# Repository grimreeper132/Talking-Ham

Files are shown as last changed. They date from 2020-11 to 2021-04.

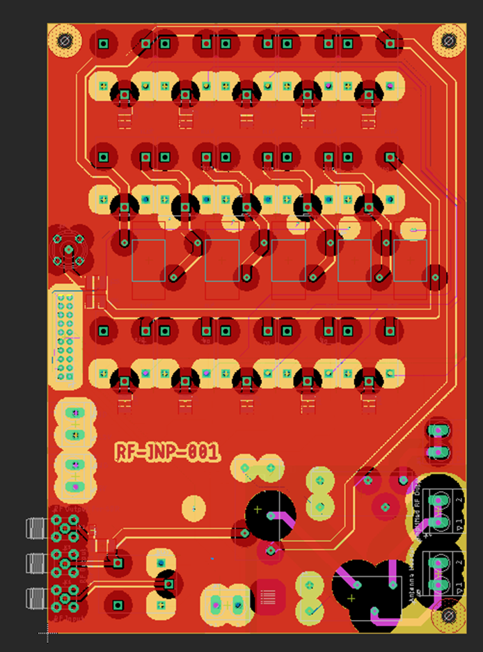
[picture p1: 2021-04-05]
Schematics/Layout Scheen shots/RF-INP-001 With Planes.png

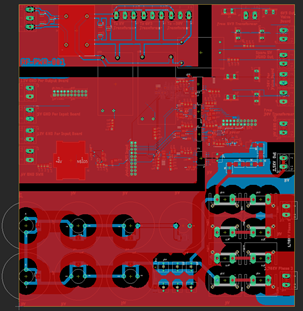
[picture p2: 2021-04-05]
Schematics/Layout Scheen shots/RF-PWR-001 With Planes.png

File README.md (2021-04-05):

# Talking-Ham
Open source HF, RF Valve Amplifier for HAM Radio. 

This has been started as a 4th year University Project in collaberation between Mage Control Systems and Strathclyde University

This project was taken up to the finalising the design but at time of writing (5/4/2021) it has not been written up

WARNING This device uses HV (2500 V) do not design it without prior knowledge and making a safety plan

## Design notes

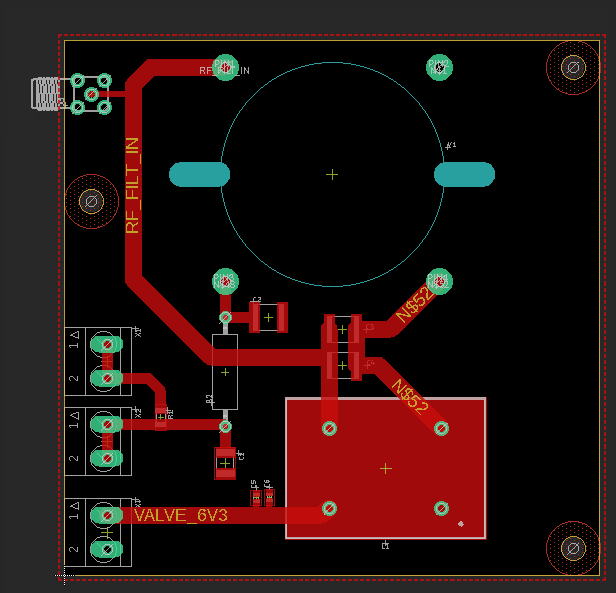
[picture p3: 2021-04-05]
Schematics/Layout Scheen shots/RF-VAL-001 W Hole.png

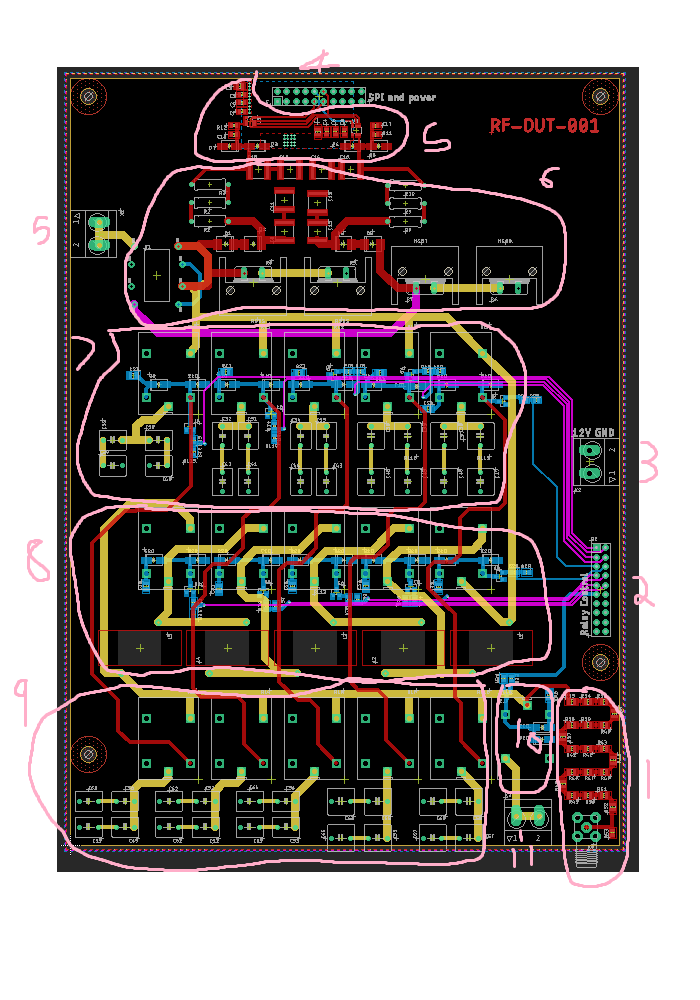
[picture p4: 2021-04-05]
Schematics/Layout Scheen shots/RF-OUT-001 Annotated.png

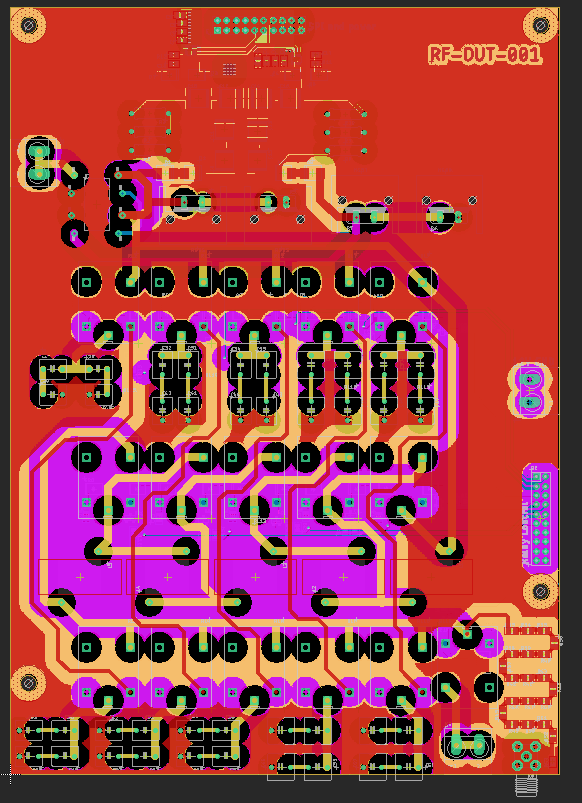
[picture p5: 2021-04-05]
Schematics/Layout Scheen shots/RF-OUT-001 With Planes.png

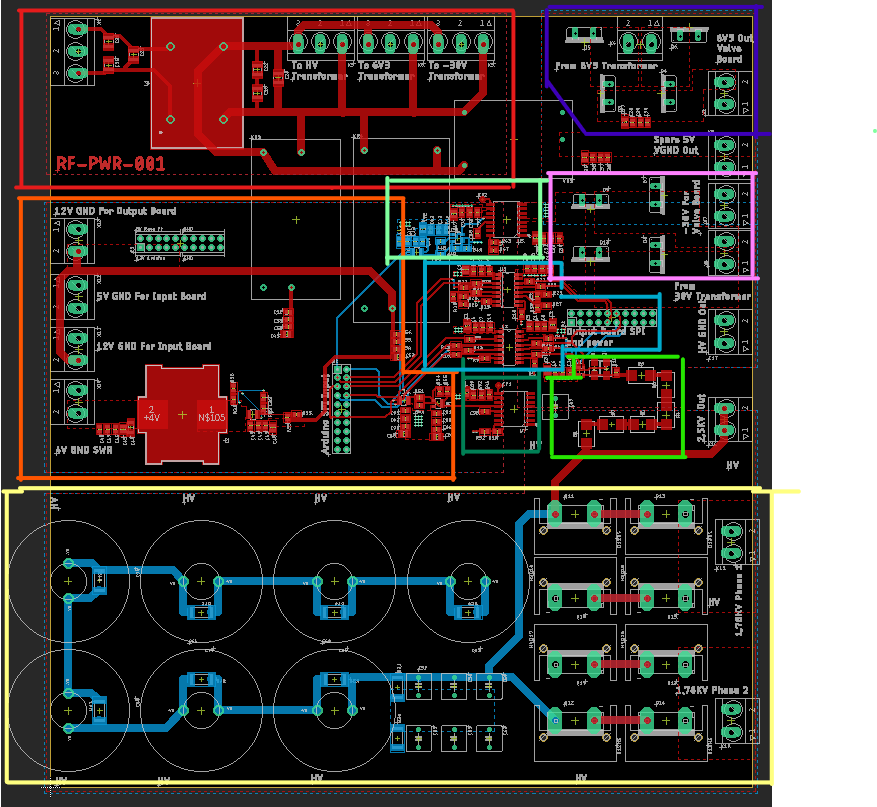
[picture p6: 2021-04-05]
Schematics/Layout Scheen shots/RF-PWR-001 Annotated.png

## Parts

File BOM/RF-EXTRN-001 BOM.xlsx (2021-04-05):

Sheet: Complete
 | Board ID |  |  | Engineer |  |  | Project |  |  | Job NO.
 | Revision | 1 |  | Approval |  |  | Customer |  |  | Boards Required | 1
Type Colour | Schematic Ref | Quantity | Spare Parts | Description | Footprint | Value | Tolerance | Manufacturer | Manufacturer Part Number | Preferred Supplier | Order-code | Alternate Supplier | Alt Order-Code | Unit/Reel Price | Packaging | Reel QTY | Stock | Price per board | Total Price (all boards) | Order Quantity | Order Price
7 | VNA1 | 1 |  | Nano VNA 4 | External | up to 1.5GHz |  | TANOU | NANO VNA 4 | Amazon | Link (https://www.amazon.co.uk/TANOU-NanoVNA-H4-Display-50KHz-1-5GHz-Analyzer/dp/B08BNC626K) |  |  | £49.61 | Cut Tape | 1000 |  | £49.61 | £49.61 | 1 | £49.61
7 | RSP1 | 1 |  | Raspberry Pi 3 | External |  |  | Raspberry Pi | RPI3-MODBP-BULK | Mouser | 358-RPI3-MODBP-BULK |  |  | £33.70 | Cut Tape | 1000 |  | £33.70 | £33.70 | 1 | £33.70
7 | DUE1 | 1 |  | Arduino Due | External |  |  | Arduino | Due | Mouser | 782-A000062 | Digi-Key | 1050-1049-ND | £28.51 | Cut Tape | 1000 |  | £28.51 | £28.51 | 1 | £28.51
7 | SDR1, SDR2 | 2 |  | Software Defined Radio | External |  |  | RTL-SDR | R820T2 RTL2832U | Amazon | Link (https://www.amazon.co.uk/RTL-SDR-Blog-RTL2832U-Software-Defined/dp/B0129EBDS2) |  |  | £49.99 | Cut Tape | 1000 |  | £99.98 | £99.98 | 2 | £99.98
10 | PCB1 | 1 |  | RF-PWR-001 PCB | RF-PWR-001 |  |  | JLC | RF-PWR-001 | JLC |  |  |  | £15.62 | Cut Tape | 1000 |  | £15.62 | £15.62 | 1 | £15.62
10 | PCB2 | 1 |  | RF-INP-001 PCB | RF-INP-001 |  |  | JLC | RF-INP-001 | JLC |  |  |  | £32.26 | Cut Tape | 1000 |  | £32.26 | £32.26 | 1 | £32.26
10 | PCB3 | 1 |  | RF-VAL-001 PCB | RF-VAL-001 |  |  | JLC | RF-VAL-001 | JLC |  |  |  | £1.45 | Cut Tape | 1000 |  | £1.45 | £1.45 | 1 | £1.45
10 | PCB4 | 1 |  | RF-OUT-001 PCB | RF-OUT-001 |  |  | JLC | RF-OUT-001 | JLC |  |  |  | £36.40 | Cut Tape | 1000 |  | £36.40 | £36.40 | 1 | £36.40
7 | USB1, USB2 | 2 |  | USB Isolator | External |  |  | Seeed Studio | 114991949 | Mouser | 713-114991949 |  |  | £14.47 | Cut Tape | 1000 |  | £28.94 | £28.94 | 2 | £28.94
 |  |  |  |  |  |  |  |  |  |  |  |  |  |  | Cut Tape | 1000 |  | £0.00 | £0.00 | 0 | £0.00
 |  |  |  |  |  |  |  |  |  |  |  |  |  |  | Cut Tape | 1000 |  | £0.00 | £0.00 | 0 | £0.00
 |  |  |  |  |  |  |  |  |  |  |  |  |  |  | Cut Tape | 1000 |  | £0.00 | £0.00 | 0 | £0.00
 |  |  |  |  |  |  |  |  |  |  |  |  |  |  | Cut Tape | 1000 |  | £0.00 | £0.00 | 0 | £0.00
 |  |  |  |  |  |  |  |  |  |  |  |  |  |  | Cut Tape | 1000 |  | £0.00 | £0.00 | 0 | £0.00
 |  |  |  |  |  |  |  |  |  |  |  |  |  |  | Cut Tape | 1000 |  | £0.00 | £0.00 | 0 | £0.00
 |  |  |  |  |  |  |  |  |  |  |  |  |  |  | Cut Tape | 1000 |  | £0.00 | £0.00 | 0 | £0.00
 |  |  |  |  |  |  |  |  |  |  |  |  |  |  | Cut Tape | 1000 |  | £0.00 | £0.00 | 0 | £0.00
 |  |  |  |  |  |  |  |  |  |  |  |  |  |  | Cut Tape | 1000 |  | £0.00 | £0.00 | 0 | £0.00
 |  |  |  |  |  |  |  |  |  |  |  |  |  |  | Cut Tape | 1000 |  | £0.00 | £0.00 | 0 | £0.00
 |  |  |  |  |  |  |  |  |  |  |  |  |  |  | Cut Tape | 1000 |  | £0.00 | £0.00 | 0 | £0.00
 |  |  |  |  |  |  |  |  |  |  |  |  |  |  | Cut Tape | 1000 |  | £0.00 | £0.00 | 0 | £0.00
 |  |  |  |  |  |  |  |  |  |  |  |  |  |  | Cut Tape | 1000 |  | £0.00 | £0.00 | 0 | £0.00
 |  |  |  |  |  |  |  |  |  |  |  |  |  |  | Cut Tape | 1000 |  | £0.00 | £0.00 | 0 | £0.00
 |  |  |  |  |  |  |  |  |  |  |  |  |  |  | Cut Tape | 1000 |  | £0.00 | £0.00 | 0 | £0.00
 |  |  |  |  |  |  |  |  |  |  |  |  |  |  | Cut Tape | 1000 |  | £0.00 | £0.00 | 0 | £0.00
 |  |  |  |  |  |  |  |  |  |  |  |  |  |  | Cut Tape | 1000 |  | £0.00 | £0.00 | 0 | £0.00
 |  |  |  |  |  |  |  |  |  |  |  |  |  |  | Cut Tape | 1000 |  | £0.00 | £0.00 | 0 | £0.00
 |  |  |  |  |  |  |  |  |  |  |  |  |  |  | Cut Tape | 1000 |  | £0.00 | £0.00 | 0 | £0.00
 |  |  |  |  |  |  |  |  |  |  |  |  |  |  | Cut Tape | 1000 |  | £0.00 | £0.00 | 0 | £0.00
 |  |  |  |  |  |  |  |  |  |  |  |  |  |  | Cut Tape | 1000 |  | £0.00 | £0.00 | 0 | £0.00
 |  |  |  |  |  |  |  |  |  |  |  |  |  |  | Cut Tape | 1000 |  | £0.00 | £0.00 | 0 | £0.00
 |  |  |  |  |  |  |  |  |  |  |  |  |  |  | Cut Tape | 1000 |  | £0.00 | £0.00 | 0 | £0.00
 |  |  |  |  |  |  |  |  |  |  |  |  |  |  | Cut Tape | 1000 |  | £0.00 | £0.00 | 0 | £0.00
 |  |  |  |  |  |  |  |  |  |  |  |  |  |  | Cut Tape | 1000 |  | £0.00 | £0.00 | 0 | £0.00
 |  |  |  |  |  |  |  |  |  |  |  |  |  |  | Cut Tape | 1000 |  | £0.00 | £0.00 | 0 | £0.00
 |  |  |  |  |  |  |  |  |  |  |  |  |  |  | Cut Tape | 1000 |  | £0.00 | £0.00 | 0 | £0.00
 |  |  |  |  |  |  |  |  |  |  |  |  |  |  | Cut Tape | 1000 |  | £0.00 | £0.00 | 0 | £0.00
 |  |  |  |  |  |  |  |  |  |  |  |  |  |  | Cut Tape | 1000 |  | £0.00 | £0.00 | 0 | £0.00
 |  |  |  |  |  |  |  |  |  |  |  |  |  |  | Cut Tape | 1000 |  | £0.00 | £0.00 | 0 | £0.00
 |  |  |  |  |  |  |  |  |  |  |  |  |  |  | Cut Tape | 1000 |  | £0.00 | £0.00 | 0 | £0.00
 |  |  |  |  |  |  |  |  |  |  |  |  |  |  | Cut Tape | 1000 |  | £0.00 | £0.00 | 0 | £0.00
 |  |  |  |  |  |  |  |  |  |  |  |  |  |  | Cut Tape | 1000 |  | £0.00 | £0.00 | 0 | £0.00
 |  |  |  |  |  |  |  |  |  |  |  |  |  |  | Cut Tape | 1000 |  | £0.00 | £0.00 | 0 | £0.00
 |  |  |  |  |  |  |  |  |  |  |  |  |  |  | Cut Tape | 1000 |  | £0.00 | £0.00 | 0 | £0.00
 |  |  |  |  |  |  |  |  |  |  |  |  |  |  | Cut Tape | 1000 |  | £0.00 | £0.00 | 0 | £0.00
 |  |  |  |  |  |  |  |  |  |  |  |  |  |  | Cut Tape | 1000 |  | £0.00 | £0.00 | 0 | £0.00
 |  |  |  |  |  |  |  |  |  |  |  |  |  |  | Cut Tape | 1000 |  | £0.00 | £0.00 | 0 | £0.00
 |  |  |  |  |  |  |  |  |  |  |  |  |  |  | Cut Tape | 1000 |  | £0.00 | £0.00 | 0 | £0.00
 |  |  |  |  |  |  |  |  |  |  |  |  |  |  | Cut Tape | 1000 |  | £0.00 | £0.00 | 0 | £0.00
 |  |  |  |  |  |  |  |  |  |  |  |  |  |  | Cut Tape | 1000 |  | £0.00 | £0.00 | 0 | £0.00
 |  |  |  |  |  |  |  |  |  |  |  |  |  |  | Cut Tape | 1000 |  | £0.00 | £0.00 | 0 | £0.00
 |  |  |  |  |  |  |  |  |  |  |  |  |  |  | Cut Tape | 1000 |  | £0.00 | £0.00 | 0 | £0.00
 |  |  |  |  |  |  |  |  |  |  |  |  |  |  | Cut Tape | 1000 |  | £0.00 | £0.00 | 0 | £0.00
 |  |  |  |  |  |  |  |  |  |  |  |  |  |  | Cut Tape | 1000 |  | £0.00 | £0.00 | 0 | £0.00
 |  |  |  |  |  |  |  |  |  |  |  |  |  |  | Cut Tape | 1000 |  | £0.00 | £0.00 | 0 | £0.00
 |  |  |  |  |  |  |  |  |  |  |  |  |  |  | Cut Tape | 1000 |  | £0.00 | £0.00 | 0 | £0.00
 |  |  |  |  |  |  |  |  |  |  |  |  |  |  | Cut Tape | 1000 |  | £0.00 | £0.00 | 0 | £0.00
 |  |  |  |  |  |  |  |  |  |  |  |  |  |  | Cut Tape | 1000 |  | £0.00 | £0.00 | 0 | £0.00
 |  |  |  |  |  |  |  |  |  |  |  |  |  |  | Cut Tape | 1000 |  | £0.00 | £0.00 | 0 | £0.00
 |  |  |  |  |  |  |  |  |  |  |  |  |  |  | Cut Tape | 1000 |  | £0.00 | £0.00 | 0 | £0.00
 |  |  |  |  |  |  |  |  |  |  |  |  |  |  | Cut Tape | 1000 |  | £0.00 | £0.00 | 0 | £0.00
 |  |  |  |  |  |  |  |  |  |  |  |  |  |  | Cut Tape | 1000 |  | £0.00 | £0.00 | 0 | £0.00
 |  |  |  |  |  |  |  |  |  |  |  |  |  |  | Cut Tape | 1000 |  | £0.00 | £0.00 | 0 | £0.00
 |  |  |  |  |  |  |  |  |  |  |  |  |  |  | Cut Tape | 1000 |  | £0.00 | £0.00 | 0 | £0.00
 |  |  |  |  |  |  |  |  |  |  |  |  |  |  | Cut Tape | 1000 |  | £0.00 | £0.00 | 0 | £0.00
 |  |  |  |  |  |  |  |  |  |  |  |  |  |  | Cut Tape | 1000 |  | £0.00 | £0.00 | 0 | £0.00
 |  |  |  |  |  |  |  |  |  |  |  |  |  |  | Cut Tape | 1000 |  | £0.00 | £0.00 | 0 | £0.00
 |  |  |  |  |  |  |  |  |  |  |  |  |  |  | Cut Tape | 1000 |  | £0.00 | £0.00 | 0 | £0.00
 |  |  |  |  |  |  |  |  |  |  |  |  |  |  | Cut Tape | 1000 |  | £0.00 | £0.00 | 0 | £0.00
 |  |  |  |  |  |  |  |  |  |  |  |  |  |  | Cut Tape | 1000 |  | £0.00 | £0.00 | 0 | £0.00
 |  |  |  |  |  |  |  |  |  |  |  |  |  |  | Cut Tape | 1000 |  | £0.00 | £0.00 | 0 | £0.00
 |  |  |  |  |  |  |  |  |  |  |  |  |  |  | Cut Tape | 1000 |  | £0.00 | £0.00 | 0 | £0.00
 |  |  |  |  |  |  |  |  |  |  |  |  |  |  | Cut Tape | 1000 |  | £0.00 | £0.00 | 0 | £0.00
 |  |  |  |  |  |  |  |  |  |  |  |  |  |  | Cut Tape | 1000 |  | £0.00 | £0.00 | 0 | £0.00
 |  |  |  |  |  |  |  |  |  |  |  |  |  |  | Cut Tape | 1000 |  | £0.00 | £0.00 | 0 | £0.00
 |  |  |  |  |  |  |  |  |  |  |  |  |  |  | Cut Tape | 1000 |  | £0.00 | £0.00 | 0 | £0.00
 |  |  |  |  |  |  |  |  |  |  |  |  |  |  | Cut Tape | 1000 |  | £0.00 | £0.00 | 0 | £0.00
 |  |  |  |  |  |  |  |  |  |  |  |  |  |  | Cut Tape | 1000 |  | £0.00 | £0.00 | 0 | £0.00
 |  |  |  |  |  |  |  |  |  |  |  |  |  |  | Cut Tape | 1000 |  | £0.00 | £0.00 | 0 | £0.00
 |  |  |  |  |  |  |  |  |  |  |  |  |  |  | Cut Tape | 1000 |  | £0.00 | £0.00 | 0 | £0.00
 |  |  |  |  |  |  |  |  |  |  |  |  |  |  | Cut Tape | 1000 |  | £0.00 | £0.00 | 0 | £0.00
 |  |  |  |  |  |  |  |  |  |  |  |  |  |  | Cut Tape | 1000 |  | £0.00 | £0.00 | 0 | £0.00
 |  |  |  |  |  |  |  |  |  |  |  |  |  |  | Cut Tape | 1000 |  | £0.00 | £0.00 | 0 | £0.00
 |  |  |  |  |  |  |  |  |  |  |  |  |  |  | Cut Tape | 1000 |  | £0.00 | £0.00 | 0 | £0.00
 |  |  |  |  |  |  |  |  |  |  |  |  |  |  | Cut Tape | 1000 |  | £0.00 | £0.00 | 0 | £0.00
 |  |  |  |  |  |  |  |  |  |  |  |  |  |  | Cut Tape | 1000 |  | £0.00 | £0.00 | 0 | £0.00
 |  |  |  |  |  |  |  |  |  |  |  |  |  |  | Cut Tape | 1000 |  | £0.00 | £0.00 | 0 | £0.00
 |  |  |  |  |  |  |  |  |  |  |  |  |  |  | Cut Tape | 1000 |  | £0.00 | £0.00 | 0 | £0.00
 |  |  |  |  |  |  |  |  |  |  |  |  |  |  | Cut Tape | 1000 |  | £0.00 | £0.00 | 0 | £0.00
 |  |  |  |  |  |  |  |  |  |  |  |  |  |  | Cut Tape | 1000 |  | £0.00 | £0.00 | 0 | £0.00
 |  |  |  |  |  |  |  |  |  |  |  |  |  |  | Cut Tape | 1000 |  | £0.00 | £0.00 | 0 | £0.00
 |  |  |  |  |  |  |  |  |  |  |  |  |  |  | Cut Tape | 1000 |  | £0.00 | £0.00 | 0 | £0.00
 |  |  |  |  |  |  |  |  |  |  |  |  |  |  | Cut Tape | 1000 |  | £0.00 | £0.00 | 0 | £0.00
 |  |  |  |  |  |  |  |  |  |  |  |  |  |  | Cut Tape | 1000 |  | £0.00 | £0.00 | 0 | £0.00
 |  |  |  |  |  |  |  |  |  |  |  |  |  |  | Cut Tape | 1000 |  | £0.00 | £0.00 | 0 | £0.00
 |  |  |  |  |  |  |  |  |  |  |  |  |  |  | Cut Tape | 1000 |  | £0.00 | £0.00 | 0 | £0.00
 |  |  |  |  |  |  |  |  |  |  |  |  |  |  | Cut Tape | 1000 |  | £0.00 | £0.00 | 0 | £0.00
 |  |  |  |  |  |  |  |  |  |  |  |  |  |  | Cut Tape | 1000 |  | £0.00 | £0.00 | 0 | £0.00
 |  |  |  |  |  |  |  |  |  |  |  |  |  |  | Cut Tape | 1000 |  | £0.00 | £0.00 | 0 | £0.00
 |  |  |  |  |  |  |  |  |  |  |  |  |  |  | Cut Tape | 1000 |  | £0.00 | £0.00 | 0 | £0.00
 |  |  |  |  |  |  |  |  |  |  |  |  |  |  | Cut Tape | 1000 |  | £0.00 | £0.00 | 0 | £0.00
 |  |  |  |  |  |  |  |  |  |  |  |  |  |  | Cut Tape | 1000 |  | £0.00 | £0.00 | 0 | £0.00
 |  |  |  |  |  |  |  |  |  |  |  |  |  |  | Cut Tape | 1000 |  | £0.00 | £0.00 | 0 | £0.00
 |  |  |  |  |  |  |  |  |  |  |  |  |  |  | Cut Tape | 1000 |  | £0.00 | £0.00 | 0 | £0.00
 |  |  |  |  |  |  |  |  |  |  |  |  |  |  | Cut Tape | 1000 |  | £0.00 | £0.00 | 0 | £0.00
 |  |  |  |  |  |  |  |  |  |  |  |  |  |  | Cut Tape | 1000 |  | £0.00 | £0.00 | 0 | £0.00
 |  |  |  |  |  |  |  |  |  |  |  |  |  |  | Cut Tape | 1000 |  | £0.00 | £0.00 | 0 | £0.00
 |  |  |  |  |  |  |  |  |  |  |  |  |  |  | Cut Tape | 1000 |  | £0.00 | £0.00 | 0 | £0.00
 |  |  |  |  |  |  |  |  |  |  |  |  |  |  | Cut Tape | 1000 |  | £0.00 | £0.00 | 0 | £0.00
 |  |  |  |  |  |  |  |  |  |  |  |  |  |  | Cut Tape | 1000 |  | £0.00 | £0.00 | 0 | £0.00
 |  |  |  |  |  |  |  |  |  |  |  |  |  |  | Cut Tape | 1000 |  | £0.00 | £0.00 | 0 | £0.00
 |  |  |  |  |  |  |  |  |  |  |  |  |  |  | Cut Tape | 1000 |  | £0.00 | £0.00 | 0 | £0.00
 |  |  |  |  |  |  |  |  |  |  |  |  |  |  | Cut Tape | 1000 |  | £0.00 | £0.00 | 0 | £0.00
 |  |  |  |  |  |  |  |  |  |  |  |  |  |  | Cut Tape | 1000 |  | £0.00 | £0.00 | 0 | £0.00
 |  |  |  |  |  |  |  |  |  |  |  |  |  |  | Cut Tape | 1000 |  | £0.00 | £0.00 | 0 | £0.00
 |  |  |  |  |  |  |  |  |  |  |  |  |  |  | Cut Tape | 1000 |  | £0.00 | £0.00 | 0 | £0.00
 |  |  |  |  |  |  |  |  |  |  |  |  |  |  | Cut Tape | 1000 |  | £0.00 | £0.00 | 0 | £0.00
 |  |  |  |  |  |  |  |  |  |  |  |  |  |  | Cut Tape | 1000 |  | £0.00 | £0.00 | 0 | £0.00
 |  |  |  |  |  |  |  |  |  |  |  |  |  |  | Cut Tape | 1000 |  | £0.00 | £0.00 | 0 | £0.00
 |  |  |  |  |  |  |  |  |  |  |  |  |  |  | Cut Tape | 1000 |  | £0.00 | £0.00 | 0 | £0.00
 |  |  |  |  |  |  |  |  |  |  |  |  |  |  | Cut Tape | 1000 |  | £0.00 | £0.00 | 0 | £0.00
 |  |  |  |  |  |  |  |  |  |  |  |  |  |  | Cut Tape | 1000 |  | £0.00 | £0.00 | 0 | £0.00
 |  |  |  |  |  |  |  |  |  |  |  |  |  |  | Cut Tape | 1000 |  | £0.00 | £0.00 | 0 | £0.00
 |  |  |  |  |  |  |  |  |  |  |  |  |  |  | Cut Tape | 1000 |  | £0.00 | £0.00 | 0 | £0.00
 |  |  |  |  |  |  |  |  |  |  |  |  |  |  | Cut Tape | 1000 |  | £0.00 | £0.00 | 0 | £0.00
 |  |  |  |  |  |  |  |  |  |  |  |  |  |  | Cut Tape | 1000 |  | £0.00 | £0.00 | 0 | £0.00
 |  |  |  |  |  |  |  |  |  |  |  |  |  |  | Cut Tape | 1000 |  | £0.00 | £0.00 | 0 | £0.00
 |  |  |  |  |  |  |  |  |  |  |  |  |  |  | Cut Tape | 1000 |  | £0.00 | £0.00 | 0 | £0.00
 |  |  |  |  |  |  |  |  |  |  |  |  |  |  | Cut Tape | 1000 |  | £0.00 | £0.00 | 0 | £0.00
 |  |  |  |  |  |  |  |  |  |  |  |  |  |  | Cut Tape | 1000 |  | £0.00 | £0.00 | 0 | £0.00
 |  |  |  |  |  |  |  |  |  |  |  |  |  |  | Cut Tape | 1000 |  | £0.00 | £0.00 | 0 | £0.00
 |  |  |  |  |  |  |  |  |  |  |  |  |  |  | Cut Tape | 1000 |  | £0.00 | £0.00 | 0 | £0.00
 |  |  |  |  |  |  |  |  |  |  |  |  |  |  | Cut Tape | 1000 |  | £0.00 | £0.00 | 0 | £0.00
 |  |  |  |  |  |  |  |  |  |  |  |  |  |  | Cut Tape | 1000 |  | £0.00 | £0.00 | 0 | £0.00
 |  |  |  |  |  |  |  |  |  |  |  |  |  |  | Cut Tape | 1000 |  | £0.00 | £0.00 | 0 | £0.00
 |  |  |  |  |  |  |  |  |  |  |  |  |  |  | Cut Tape | 1000 |  | £0.00 | £0.00 | 0 | £0.00
 |  |  |  |  |  |  |  |  |  |  |  |  |  |  | Cut Tape | 1000 |  | £0.00 | £0.00 | 0 | £0.00
 |  |  |  |  |  |  |  |  |  |  |  |  |  |  | Cut Tape | 1000 |  | £0.00 | £0.00 | 0 | £0.00
 |  |  |  |  |  |  |  |  |  |  |  |  |  |  | Cut Tape | 1000 |  | £0.00 | £0.00 | 0 | £0.00
 |  |  |  |  |  |  |  |  |  |  |  |  |  |  | Cut Tape | 1000 |  | £0.00 | £0.00 | 0 | £0.00
 |  |  |  |  |  |  |  |  |  |  |  |  |  |  | Cut Tape | 1000 |  | £0.00 | £0.00 | 0 | £0.00
 |  |  |  |  |  |  |  |  |  |  |  |  |  |  | Cut Tape | 1000 |  | £0.00 | £0.00 | 0 | £0.00
 |  |  |  |  |  |  |  |  |  |  |  |  |  |  | Cut Tape | 1000 |  | £0.00 | £0.00 | 0 | £0.00
 |  |  |  |  |  |  |  |  |  |  |  |  |  |  | Cut Tape | 1000 |  | £0.00 | £0.00 | 0 | £0.00
 |  |  |  |  |  |  |  |  |  |  |  |  |  |  | Cut Tape | 1000 |  | £0.00 | £0.00 | 0 | £0.00
 |  |  |  |  |  |  |  |  |  |  |  |  |  |  | Cut Tape | 1000 |  | £0.00 | £0.00 | 0 | £0.00
 |  |  |  |  |  |  |  |  |  |  |  |  |  |  | Cut Tape | 1000 |  | £0.00 | £0.00 | 0 | £0.00
 |  |  |  |  |  |  |  |  |  |  |  |  |  |  | Cut Tape | 1000 |  | £0.00 | £0.00 | 0 | £0.00
 |  |  |  |  |  |  |  |  |  |  |  |  |  |  | Cut Tape | 1000 |  | £0.00 | £0.00 | 0 | £0.00
 |  |  |  |  |  |  |  |  |  |  |  |  |  |  | Cut Tape | 1000 |  | £0.00 | £0.00 | 0 | £0.00
 |  |  |  |  |  |  |  |  |  |  |  |  |  |  | Cut Tape | 1000 |  | £0.00 | £0.00 | 0 | £0.00
 |  |  |  |  |  |  |  |  |  |  |  |  |  |  | Cut Tape | 1000 |  | £0.00 | £0.00 | 0 | £0.00
 |  |  |  |  |  |  |  |  |  |  |  |  |  |  | Cut Tape | 1000 |  | £0.00 | £0.00 | 0 | £0.00
 |  |  |  |  |  |  |  |  |  |  |  |  |  |  | Cut Tape | 1000 |  | £0.00 | £0.00 | 0 | £0.00
 |  |  |  |  |  |  |  |  |  |  |  |  |  |  | Cut Tape | 1000 |  | £0.00 | £0.00 | 0 | £0.00
 |  |  |  |  |  |  |  |  |  |  |  |  |  |  | Cut Tape | 1000 |  | £0.00 | £0.00 | 0 | £0.00
 |  |  |  |  |  |  |  |  |  |  |  |  |  |  | Cut Tape | 1000 |  | £0.00 | £0.00 | 0 | £0.00
 |  |  |  |  |  |  |  |  |  |  |  |  |  |  | Cut Tape | 1000 |  | £0.00 | £0.00 | 0 | £0.00
 |  |  |  |  |  |  |  |  |  |  |  |  |  |  | Cut Tape | 1000 |  | £0.00 | £0.00 | 0 | £0.00
 |  |  |  |  |  |  |  |  |  |  |  |  |  |  | Cut Tape | 1001 |  | £0.00 | £0.00 | 0 | £0.00
 |  |  |  |  |  |  |  |  |  |  |  |  |  |  | Cut Tape | 1002 |  | £0.00 | £0.00 | 0 | £0.00
 |  |  |  |  |  |  |  |  |  |  |  |  |  |  | Cut Tape | 1003 |  | £0.00 | £0.00 | 0 | £0.00
 |  |  |  |  |  |  |  |  |  |  |  |  |  |  | Cut Tape | 1004 |  | £0.00 | £0.00 | 0 | £0.00
 |  |  |  |  |  |  |  |  |  |  |  |  |  |  | Cut Tape | 1005 |  | £0.00 | £0.00 | 0 | £0.00
 |  |  |  |  |  |  |  |  |  |  |  |  |  |  | Cut Tape | 1006 |  | £0.00 | £0.00 | 0 | £0.00
 |  |  |  |  |  |  |  |  |  |  |  |  |  |  | Cut Tape | 1007 |  | £0.00 | £0.00 | 0 | £0.00
 |  |  |  |  |  |  |  |  |  |  |  |  |  |  | Cut Tape | 1008 |  | £0.00 | £0.00 | 0 | £0.00
 |  |  |  |  |  |  |  |  |  |  |  |  |  |  | Cut Tape | 1009 |  | £0.00 | £0.00 | 0 | £0.00
 |  |  |  |  |  |  |  |  |  |  |  |  |  |  | Cut Tape | 1010 |  | £0.00 | £0.00 | 0 | £0.00
 |  |  |  |  |  |  |  |  |  |  |  |  |  |  | Cut Tape | 1011 |  | £0.00 | £0.00 | 0 | £0.00
 |  |  |  |  |  |  |  |  |  |  |  |  |  |  | Cut Tape | 1012 |  | £0.00 | £0.00 | 0 | £0.00
 |  |  |  |  |  |  |  |  |  |  |  |  |  |  | Cut Tape | 1013 |  | £0.00 | £0.00 | 0 | £0.00
 |  |  |  |  |  |  |  |  |  |  |  |  |  |  | Cut Tape | 1014 |  | £0.00 | £0.00 | 0 | £0.00
 |  |  |  |  |  |  |  |  |  |  |  |  |  |  | Cut Tape | 1015 |  | £0.00 | £0.00 | 0 | £0.00
 |  |  |  |  |  |  |  |  |  |  |  |  |  |  | Cut Tape | 1016 |  | £0.00 | £0.00 | 0 | £0.00
 |  |  |  |  |  |  |  |  |  |  |  |  |  |  | Cut Tape | 1017 |  | £0.00 | £0.00 | 0 | £0.00
 |  |  |  |  |  |  |  |  |  |  |  |  |  |  | Cut Tape | 1018 |  | £0.00 | £0.00 | 0 | £0.00
 |  |  |  |  |  |  |  |  |  |  |  |  |  |  | Cut Tape | 1019 |  | £0.00 | £0.00 | 0 | £0.00
 |  |  |  |  |  |  |  |  |  |  |  |  |  |  | Cut Tape | 1020 |  | £0.00 | £0.00 | 0 | £0.00
 |  |  |  |  |  |  |  |  |  |  |  |  |  |  | Cut Tape | 1021 |  | £0.00 | £0.00 | 0 | £0.00
 |  |  |  |  |  |  |  |  |  |  |  |  |  |  | Cut Tape | 1022 |  | £0.00 | £0.00 | 0 | £0.00
 |  |  |  |  |  |  |  |  |  |  |  |  |  |  | Cut Tape | 1023 |  | £0.00 | £0.00 | 0 | £0.00
 |  |  |  |  |  |  |  |  |  |  |  |  |  |  | Cut Tape | 1024 |  | £0.00 | £0.00 | 0 | £0.00
 |  |  |  |  |  |  |  |  |  |  |  |  |  |  | Cut Tape | 1025 |  | £0.00 | £0.00 | 0 | £0.00
 |  |  |  |  |  |  |  |  |  |  |  |  |  |  | Cut Tape | 1026 |  | £0.00 | £0.00 | 0 | £0.00
 |  |  |  |  |  |  |  |  |  |  |  |  |  |  | Cut Tape | 1027 |  | £0.00 | £0.00 | 0 | £0.00
 |  |  |  |  |  |  |  |  |  |  |  |  |  |  | Cut Tape | 1028 |  | £0.00 | £0.00 | 0 | £0.00
 |  |  |  |  |  |  |  |  |  |  |  |  |  |  | Cut Tape | 1029 |  | £0.00 | £0.00 | 0 | £0.00
 |  |  |  |  |  |  |  |  |  |  |  |  |  |  | Cut Tape | 1030 |  | £0.00 | £0.00 | 0 | £0.00
 |  |  |  |  |  |  |  |  |  |  |  |  |  |  | Cut Tape | 1031 |  | £0.00 | £0.00 | 0 | £0.00
 |  |  |  |  |  |  |  |  |  |  |  |  |  |  | Cut Tape | 1032 |  | £0.00 | £0.00 | 0 | £0.00
 |  |  |  |  |  |  |  |  |  |  |  |  |  |  | Cut Tape | 1033 |  | £0.00 | £0.00 | 0 | £0.00
 |  |  |  |  |  |  |  |  |  |  |  |  |  |  | Cut Tape | 1034 |  | £0.00 | £0.00 | 0 | £0.00
 |  |  |  |  |  |  |  |  |  |  |  |  |  |  | Cut Tape | 1035 |  | £0.00 | £0.00 | 0 | £0.00
 |  |  |  |  |  |  |  |  |  |  |  |  |  |  | Cut Tape | 1036 |  | £0.00 | £0.00 | 0 | £0.00
 |  |  |  |  |  |  |  |  |  |  |  |  |  |  | Cut Tape | 1037 |  | £0.00 | £0.00 | 0 | £0.00
 |  |  |  |  |  |  |  |  |  |  |  |  |  |  | Cut Tape | 1038 |  | £0.00 | £0.00 | 0 | £0.00
 |  |  |  |  |  |  |  |  |  |  |  |  |  |  | Cut Tape | 1039 |  | £0.00 | £0.00 | 0 | £0.00
 |  |  |  |  |  |  |  |  |  |  |  |  |  |  | Cut Tape | 1040 |  | £0.00 | £0.00 | 0 | £0.00
 |  |  |  |  |  |  |  |  |  |  |  |  |  |  | Cut Tape | 1041 |  | £0.00 | £0.00 | 0 | £0.00
 |  |  |  |  |  |  |  |  |  |  |  |  |  |  | Cut Tape | 1042 |  | £0.00 | £0.00 | 0 | £0.00
 |  |  |  |  |  |  |  |  |  |  |  |  |  |  | Cut Tape | 1043 |  | £0.00 | £0.00 | 0 | £0.00
 |  |  |  |  |  |  |  |  |  |  |  |  |  |  | Cut Tape | 1044 |  | £0.00 | £0.00 | 0 | £0.00
 |  |  |  |  |  |  |  |  |  |  |  |  |  |  | Cut Tape | 1045 |  | £0.00 | £0.00 | 0 | £0.00
 |  |  |  |  |  |  |  |  |  |  |  |  |  |  | Cut Tape | 1046 |  | £0.00 | £0.00 | 0 | £0.00
 |  |  |  |  |  |  |  |  |  |  |  |  |  |  | Cut Tape | 1047 |  | £0.00 | £0.00 | 0 | £0.00
 |  |  |  |  |  |  |  |  |  |  |  |  |  |  | Cut Tape | 1048 |  | £0.00 | £0.00 | 0 | £0.00
 |  |  |  |  |  |  |  |  |  |  |  |  |  |  | Cut Tape | 1049 |  | £0.00 | £0.00 | 0 | £0.00
 |  |  |  |  |  |  |  |  |  |  |  |  |  |  | Cut Tape | 1050 |  | £0.00 | £0.00 | 0 | £0.00
 |  |  |  |  |  |  |  |  |  |  |  |  |  |  | Cut Tape | 1051 |  | £0.00 | £0.00 | 0 | £0.00
 |  |  |  |  |  |  |  |  |  |  |  |  |  |  | Cut Tape | 1052 |  | £0.00 | £0.00 | 0 | £0.00
 |  |  |  |  |  |  |  |  |  |  |  |  |  |  | Cut Tape | 1053 |  | £0.00 | £0.00 | 0 | £0.00
 |  |  |  |  |  |  |  |  |  |  |  |  |  |  | Cut Tape | 1054 |  | £0.00 | £0.00 | 0 | £0.00
 |  |  |  |  |  |  |  |  |  |  |  |  |  |  | Cut Tape | 1055 |  | £0.00 | £0.00 | 0 | £0.00
 |  |  |  |  |  |  |  |  |  |  |  |  |  |  | Cut Tape | 1056 |  | £0.00 | £0.00 | 0 | £0.00
 |  |  |  |  |  |  |  |  |  |  |  |  |  |  | Cut Tape | 1057 |  | £0.00 | £0.00 | 0 | £0.00
 |  |  |  |  |  |  |  |  |  |  |  |  |  |  | Cut Tape | 1058 |  | £0.00 | £0.00 | 0 | £0.00
 |  |  |  |  |  |  |  |  |  |  |  |  |  |  | Cut Tape | 1059 |  | £0.00 | £0.00 | 0 | £0.00
 |  |  |  |  |  |  |  |  |  |  |  |  |  |  | Cut Tape | 1060 |  | £0.00 | £0.00 | 0 | £0.00
 |  |  |  |  |  |  |  |  |  |  |  |  |  |  | Cut Tape | 1061 |  | £0.00 | £0.00 | 0 | £0.00
 |  |  |  |  |  |  |  |  |  |  |  |  |  |  | Cut Tape | 1062 |  | £0.00 | £0.00 | 0 | £0.00
 |  |  |  |  |  |  |  |  |  |  |  |  |  |  | Cut Tape | 1063 |  | £0.00 | £0.00 | 0 | £0.00
 |  |  |  |  |  |  |  |  |  |  |  |  |  |  | Cut Tape | 1064 |  | £0.00 | £0.00 | 0 | £0.00
 |  |  |  |  |  |  |  |  |  |  |  |  |  |  | Cut Tape | 1065 |  | £0.00 | £0.00 | 0 | £0.00
 |  |  |  |  |  |  |  |  |  |  |  |  |  |  | Cut Tape | 1066 |  | £0.00 | £0.00 | 0 | £0.00
 |  |  |  |  |  |  |  |  |  |  |  |  |  |  | Cut Tape | 1067 |  | £0.00 | £0.00 | 0 | £0.00
 |  |  |  |  |  |  |  |  |  |  |  |  |  |  | Cut Tape | 1068 |  | £0.00 | £0.00 | 0 | £0.00
 |  |  |  |  |  |  |  |  |  |  |  |  |  |  | Cut Tape | 1069 |  | £0.00 | £0.00 | 0 | £0.00
 |  |  |  |  |  |  |  |  |  |  |  |  |  |  | Cut Tape | 1070 |  | £0.00 | £0.00 | 0 | £0.00
 |  |  |  |  |  |  |  |  |  |  |  |  |  |  | Cut Tape | 1071 |  | £0.00 | £0.00 | 0 | £0.00
 |  |  |  |  |  |  |  |  |  |  |  |  |  |  | Cut Tape | 1072 |  | £0.00 | £0.00 | 0 | £0.00
 |  |  |  |  |  |  |  |  |  |  |  |  |  |  | Cut Tape | 1073 |  | £0.00 | £0.00 | 0 | £0.00
 |  |  |  |  |  |  |  |  |  |  |  |  |  |  | Cut Tape | 1074 |  | £0.00 | £0.00 | 0 | £0.00
 |  |  |  |  |  |  |  |  |  |  |  |  |  |  | Cut Tape | 1075 |  | £0.00 | £0.00 | 0 | £0.00
 |  |  |  |  |  |  |  |  |  |  |  |  |  |  | Cut Tape | 1076 |  | £0.00 | £0.00 | 0 | £0.00
 |  |  |  |  |  |  |  |  |  |  |  |  |  |  | Cut Tape | 1077 |  | £0.00 | £0.00 | 0 | £0.00
 |  |  |  |  |  |  |  |  |  |  |  |  |  |  | Cut Tape | 1078 |  | £0.00 | £0.00 | 0 | £0.00
 |  |  |  |  |  |  |  |  |  |  |  |  |  |  | Cut Tape | 1079 |  | £0.00 | £0.00 | 0 | £0.00
 |  |  |  |  |  |  |  |  |  |  |  |  |  |  | Cut Tape | 1080 |  | £0.00 | £0.00 | 0 | £0.00
 |  |  |  |  |  |  |  |  |  |  |  |  |  |  | Cut Tape | 1081 |  | £0.00 | £0.00 | 0 | £0.00
 |  |  |  |  |  |  |  |  |  |  |  |  |  |  | Cut Tape | 1082 |  | £0.00 | £0.00 | 0 | £0.00
 |  |  |  |  |  |  |  |  |  |  |  |  |  |  | Cut Tape | 1083 |  | £0.00 | £0.00 | 0 | £0.00
 |  |  |  |  |  |  |  |  |  |  |  |  |  |  | Cut Tape | 1084 |  | £0.00 | £0.00 | 0 | £0.00
 |  |  |  |  |  |  |  |  |  |  |  |  |  |  | Cut Tape | 1085 |  | £0.00 | £0.00 | 0 | £0.00
 |  |  |  |  |  |  |  |  |  |  |  |  |  |  | Cut Tape | 1086 |  | £0.00 | £0.00 | 0 | £0.00
 |  |  |  |  |  |  |  |  |  |  |  |  |  |  | Cut Tape | 1087 |  | £0.00 | £0.00 | 0 | £0.00
 |  |  |  |  |  |  |  |  |  |  |  |  |  |  | Cut Tape | 1088 |  | £0.00 | £0.00 | 0 | £0.00
 |  |  |  |  |  |  |  |  |  |  |  |  |  |  | Cut Tape | 1089 |  | £0.00 | £0.00 | 0 | £0.00
 |  |  |  |  |  |  |  |  |  |  |  |  |  |  | Cut Tape | 1090 |  | £0.00 | £0.00 | 0 | £0.00
 |  |  |  |  |  |  |  |  |  |  |  |  |  |  | Cut Tape | 1091 |  | £0.00 | £0.00 | 0 | £0.00
 |  |  |  |  |  |  |  |  |  |  |  |  |  |  | Cut Tape | 1092 |  | £0.00 | £0.00 | 0 | £0.00
 |  |  |  |  |  |  |  |  |  |  |  |  |  |  | Cut Tape | 1093 |  | £0.00 | £0.00 | 0 | £0.00
 |  |  |  |  |  |  |  |  |  |  |  |  |  |  | Cut Tape | 1094 |  | £0.00 | £0.00 | 0 | £0.00
 |  |  |  |  |  |  |  |  |  |  |  |  |  |  | Cut Tape | 1095 |  | £0.00 | £0.00 | 0 | £0.00
 |  |  |  |  |  |  |  |  |  |  |  |  |  |  | Cut Tape | 1096 |  | £0.00 | £0.00 | 0 | £0.00
 |  |  |  |  |  |  |  |  |  |  |  |  |  |  | Cut Tape | 1097 |  | £0.00 | £0.00 | 0 | £0.00
 |  |  |  |  |  |  |  |  |  |  |  |  |  |  | Cut Tape | 1098 |  | £0.00 | £0.00 | 0 | £0.00
 |  |  |  |  |  |  |  |  |  |  |  |  |  |  | Cut Tape | 1099 |  | £0.00 | £0.00 | 0 | £0.00
 |  |  |  |  |  |  |  |  |  |  |  |  |  |  | Cut Tape | 1100 |  | £0.00 | £0.00 | 0 | £0.00
 |  |  |  |  |  |  |  |  |  |  |  |  |  |  | Cut Tape | 1101 |  | £0.00 | £0.00 | 0 | £0.00
 |  |  |  |  |  |  |  |  |  |  |  |  |  |  | Cut Tape | 1102 |  | £0.00 | £0.00 | 0 | £0.00
 |  |  |  |  |  |  |  |  |  |  |  |  |  |  | Cut Tape | 1103 |  | £0.00 | £0.00 | 0 | £0.00
 |  |  |  |  |  |  |  |  |  |  |  |  |  |  | Cut Tape | 1104 |  | £0.00 | £0.00 | 0 | £0.00
 |  |  |  |  |  |  |  |  |  |  |  |  |  |  | Cut Tape | 1105 |  | £0.00 | £0.00 | 0 | £0.00
 |  |  |  |  |  |  |  |  |  |  |  |  |  |  | Cut Tape | 1106 |  | £0.00 | £0.00 | 0 | £0.00
 |  |  |  |  |  |  |  |  |  |  |  |  |  |  | Cut Tape | 1107 |  | £0.00 | £0.00 | 0 | £0.00
 |  |  |  |  |  |  |  |  |  |  |  |  |  |  | Cut Tape | 1108 |  | £0.00 | £0.00 | 0 | £0.00
 |  |  |  |  |  |  |  |  |  |  |  |  |  |  | Cut Tape | 1109 |  | £0.00 | £0.00 | 0 | £0.00
 |  |  |  |  |  |  |  |  |  |  |  |  |  |  | Cut Tape | 1110 |  | £0.00 | £0.00 | 0 | £0.00
 |  |  |  |  |  |  |  |  |  |  |  |  |  |  | Cut Tape | 1111 |  | £0.00 | £0.00 | 0 | £0.00
 |  |  |  |  |  |  |  |  |  |  |  |  |  |  | Cut Tape | 1112 |  | £0.00 | £0.00 | 0 | £0.00
 |  |  |  |  |  |  |  |  |  |  |  |  |  |  | Cut Tape | 1113 |  | £0.00 | £0.00 | 0 | £0.00
 |  |  |  |  |  |  |  |  |  |  |  |  |  |  | Cut Tape | 1114 |  | £0.00 | £0.00 | 0 | £0.00
 |  |  |  |  |  |  |  |  |  |  |  |  |  |  | Cut Tape | 1115 |  | £0.00 | £0.00 | 0 | £0.00
 |  |  |  |  |  |  |  |  |  |  |  |  |  |  | Cut Tape | 1116 |  | £0.00 | £0.00 | 0 | £0.00
 |  |  |  |  |  |  |  |  |  |  |  |  |  |  | Cut Tape | 1117 |  | £0.00 | £0.00 | 0 | £0.00
 |  |  |  |  |  |  |  |  |  |  |  |  |  |  | Cut Tape | 1118 |  | £0.00 | £0.00 | 0 | £0.00
 |  |  |  |  |  |  |  |  |  |  |  |  |  |  | Cut Tape | 1119 |  | £0.00 | £0.00 | 0 | £0.00
 |  |  |  |  |  |  |  |  |  |  |  |  |  |  | Cut Tape | 1120 |  | £0.00 | £0.00 | 0 | £0.00
 |  |  |  |  |  |  |  |  |  |  |  |  |  |  | Cut Tape | 1121 |  | £0.00 | £0.00 | 0 | £0.00
 |  |  |  |  |  |  |  |  |  |  |  |  |  |  | Cut Tape | 1122 |  | £0.00 | £0.00 | 0 | £0.00
 |  |  |  |  |  |  |  |  |  |  |  |  |  |  | Cut Tape | 1123 |  | £0.00 | £0.00 | 0 | £0.00
 |  |  |  |  |  |  |  |  |  |  |  |  |  |  | Cut Tape | 1124 |  | £0.00 | £0.00 | 0 | £0.00
 |  |  |  |  |  |  |  |  |  |  |  |  |  |  | Cut Tape | 1125 |  | £0.00 | £0.00 | 0 | £0.00
 |  |  |  |  |  |  |  |  |  |  |  |  |  |  | Cut Tape | 1126 |  | £0.00 | £0.00 | 0 | £0.00
 |  |  |  |  |  |  |  |  |  |  |  |  |  |  | Cut Tape | 1127 |  | £0.00 | £0.00 | 0 | £0.00
 |  |  |  |  |  |  |  |  |  |  |  |  |  |  | Cut Tape | 1128 |  | £0.00 | £0.00 | 0 | £0.00
 |  |  |  |  |  |  |  |  |  |  |  |  |  |  | Cut Tape | 1129 |  | £0.00 | £0.00 | 0 | £0.00
 |  |  |  |  |  |  |  |  |  |  |  |  |  |  | Cut Tape | 1130 |  | £0.00 | £0.00 | 0 | £0.00
 |  |  |  |  |  |  |  |  |  |  |  |  |  |  | Cut Tape | 1131 |  | £0.00 | £0.00 | 0 | £0.00
 |  |  |  |  |  |  |  |  |  |  |  |  |  |  | Cut Tape | 1132 |  | £0.00 | £0.00 | 0 | £0.00
 |  |  |  |  |  |  |  |  |  |  |  |  |  |  | Cut Tape | 1133 |  | £0.00 | £0.00 | 0 | £0.00
 |  |  |  |  |  |  |  |  |  |  |  |  |  |  | Cut Tape | 1134 |  | £0.00 | £0.00 | 0 | £0.00
 |  |  |  |  |  |  |  |  |  |  |  |  |  |  | Cut Tape | 1135 |  | £0.00 | £0.00 | 0 | £0.00
 |  |  |  |  |  |  |  |  |  |  |  |  |  |  | Cut Tape | 1136 |  | £0.00 | £0.00 | 0 | £0.00
 |  |  |  |  |  |  |  |  |  |  |  |  |  |  | Cut Tape | 1137 |  | £0.00 | £0.00 | 0 | £0.00
 |  |  |  |  |  |  |  |  |  |  |  |  |  |  | Cut Tape | 1138 |  | £0.00 | £0.00 | 0 | £0.00
 |  |  |  |  |  |  |  |  |  |  |  |  |  |  | Cut Tape | 1139 |  | £0.00 | £0.00 | 0 | £0.00
 |  |  |  |  |  |  |  |  |  |  |  |  |  |  | Cut Tape | 1140 |  | £0.00 | £0.00 | 0 | £0.00
 |  |  |  |  |  |  |  |  |  |  |  |  |  |  | Cut Tape | 1141 |  | £0.00 | £0.00 | 0 | £0.00
 |  |  |  |  |  |  |  |  |  |  |  |  |  |  | Cut Tape | 1142 |  | £0.00 | £0.00 | 0 | £0.00
 |  |  |  |  |  |  |  |  |  |  |  |  |  |  | Cut Tape | 1143 |  | £0.00 | £0.00 | 0 | £0.00
 |  |  |  |  |  |  |  |  |  |  |  |  |  |  | Cut Tape | 1144 |  | £0.00 | £0.00 | 0 | £0.00
 |  |  |  |  |  |  |  |  |  |  |  |  |  |  | Cut Tape | 1145 |  | £0.00 | £0.00 | 0 | £0.00
 |  |  |  |  |  |  |  |  |  |  |  |  |  |  | Cut Tape | 1146 |  | £0.00 | £0.00 | 0 | £0.00
 |  |  |  |  |  |  |  |  |  |  |  |  |  |  | Cut Tape | 1147 |  | £0.00 | £0.00 | 0 | £0.00
 |  |  |  |  |  |  |  |  |  |  |  |  |  |  | Cut Tape | 1148 |  | £0.00 | £0.00 | 0 | £0.00
 |  |  |  |  |  |  |  |  |  |  |  |  |  |  | Cut Tape | 1149 |  | £0.00 | £0.00 | 0 | £0.00
 |  |  |  |  |  |  |  |  |  |  |  |  |  |  | Cut Tape | 1150 |  | £0.00 | £0.00 | 0 | £0.00
 |  |  |  |  |  |  |  |  |  |  |  |  |  |  | Cut Tape | 1151 |  | £0.00 | £0.00 | 0 | £0.00
 |  |  |  |  |  |  |  |  |  |  |  |  |  |  | Cut Tape | 1152 |  | £0.00 | £0.00 | 0 | £0.00
 |  |  |  |  |  |  |  |  |  |  |  |  |  |  | Cut Tape | 1153 |  | £0.00 | £0.00 | 0 | £0.00
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

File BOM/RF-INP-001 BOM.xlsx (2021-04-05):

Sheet: Complete
 | Board ID |  |  | Engineer |  |  | Project |  |  | Job NO.
 | Revision | 1 |  | Approval |  |  | Customer |  |  | Boards Required | 1
Type Colour | Schematic Ref | Quantity | Spare Parts | Description | Footprint | Value | Tolerance | Manufacturer | Manufacturer Part Number | Preferred Supplier | Order-code | Alternate Supplier | Alt Order-Code | Unit/Reel Price | Packaging | Reel QTY | Stock | Price per board | Total Price (all boards) | Order Quantity | Order Price
1 | C1, C2, C3, C4, C5, C6, C8, C9, C10, C11, C12, C16 | 12 |  | X5R Ceramic Capacitor | C0805 | 10u/25V |  | Samsung Electro-Mechanics | CL21A106KAYNNNE | Mouser | 187-CL21A106KAYNNNE |  |  | £0.14 | Cut Tape | 1000 |  | £1.64 | £1.64 | 12 | £1.64
2 | R1, R2, R3, R4, R9, R15, R16, R17, R18, R19, R31, R32 | 12 |  | Thick Film Resistor | R0603 | 100R | 1.00% | Vishay/Dale | CRCW0603100RFKEAC | Mouser | 71-CRCW0603100RFKEAC |  |  | £0.08 | Cut Tape | 1000 |  | £0.92 | £0.92 | 12 | £0.92
2 | R29 | 1 |  | Thick Film Resistor | R2512 | 51k/200V/250mW | 5.00% | Yageo | RC2512JK-0751KL | Mouser | 603-RC2512JK-0751KL |  |  | £0.28 | Cut Tape | 1000 |  | £0.28 | £0.28 | 1 | £0.28
2 | R30 | 1 |  | Thick Film Resistor | R0603 | 50R | 1.00% | Vishay / Dale | CRCW060350R0FKTA | Mouser | 71-CRCW0603-50 |  |  | £0.18 | Cut Tape | 1000 |  | £0.18 | £0.18 | 1 | £0.18
2 | R5, R6, R7, R8, R10, R12, R20, R21, R22, R23, R24, R34 | 12 |  | Thick Film Resistor | R0603 | 4k7 | 5.00% | Vishay / Dale | CRCW06034K70JNEAC | Mouser | 71-CRCW06034K70JNEAC |  |  | £0.08 | Cut Tape | 1000 |  | £0.92 | £0.92 | 12 | £0.92
2 | R33 | 1 |  | Thick Film Resistor | R0603 | 9k1 | 5.00% | ROHM Semiconductor | SDR03EZPJ912 | Mouser | 755-SDR03EZPJ912 |  |  | £0.08 | Cut Tape | 1000 |  | £0.08 | £0.08 | 1 | £0.08
3 | L1 | 1 |  | RF Inductor Toroid Core | T80-6 | 5 turns 20 AWG |  | Micrometals | T60-6 | Pace Components | link (http://www.pacecomponents.co.uk/pace-components/micrometals-iron-powder-Miscellaneous/rf-applications/t-60-6-micrometals-iron-powder-toroid) |  |  | £0.88 | Cut Tape | 1000 |  | £0.88 | £0.88 | 1 | £0.88
3 | L2 | 1 |  | RF Inductor Toroid Core | T80-6 | 7 turns 20 AWG |  | Micrometals | T60-6 | Pace Components | link (http://www.pacecomponents.co.uk/pace-components/micrometals-iron-powder-Miscellaneous/rf-applications/t-60-6-micrometals-iron-powder-toroid) |  |  | £0.88 | Cut Tape | 1000 |  | £0.88 | £0.88 | 1 | £0.88
3 | L3 | 1 |  | RF Inductor Toroid Core | T80-6 | 10 turns 20 AWG |  | Micrometals | T60-6 | Pace Components | link (http://www.pacecomponents.co.uk/pace-components/micrometals-iron-powder-Miscellaneous/rf-applications/t-60-6-micrometals-iron-powder-toroid) |  |  | £0.88 | Cut Tape | 1000 |  | £0.88 | £0.88 | 1 | £0.88
3 | L4 | 1 |  | RF Inductor Toroid Core | T80-6 | 15 turns 20 AWG |  | Micrometals | T60-6 | Pace Components | link (http://www.pacecomponents.co.uk/pace-components/micrometals-iron-powder-Miscellaneous/rf-applications/t-60-6-micrometals-iron-powder-toroid) |  |  | £0.88 | Cut Tape | 1000 |  | £0.88 | £0.88 | 1 | £0.88
3 | L5 | 1 |  | RF Inductor Toroid Core | T80-6 | 22 turns 20 AWG |  | Micrometals | T60-6 | Pace Components | link (http://www.pacecomponents.co.uk/pace-components/micrometals-iron-powder-Miscellaneous/rf-applications/t-60-6-micrometals-iron-powder-toroid) |  |  | £0.88 | Cut Tape | 1000 |  | £0.88 | £0.88 | 1 | £0.88
4 | D1, D2, D3, D4, D5, D6, D7, D8, D9, D10, D11, D12, D15, D16, D17, D18, D19, D20, D21, D22, D23, D24, D30, D32 | 24 |  | Schottky Diode | SMA | 0.62V 1A |  | Vishay General Semiconductor | SS1H10-M3/61T | Mouser | 78-SS1H10-M361T |  |  | £0.28 | Cut Tape | 1000 |  | £6.77 | £6.77 | 24 | £6.77
6 | Q1, Q2, Q3, Q4, Q5, Q6, Q8, Q9, Q10, Q11, Q12, Q16 | 12 |  | N-Channel MOSFET | SOT23 |  |  | Nexperia | 2N7002NXAKR | Mouser | 771-2N7002NXAKR |  |  | £0.08 | Cut Tape | 1000 |  | £0.92 | £0.92 | 12 | £0.92
7 | K1, K2, K3 | 3 |  | General Purpose Relay | Custom |  |  | TE Connectivity / P&B | 3-1415899-5 | Mouser | 655-3-1415899-5 |  |  | £1.50 | Cut Tape | 1000 |  | £4.50 | £4.50 | 3 | £4.50
7 | P1 | 1 |  | 20 pin Headeer | 2.54mm 2 by 10 pos | 20 pins |  | Amphenol FCI | 10129381-920001BLF | Mouser | 649-1012938192001BLF |  |  | £0.33 | Cut Tape | 1000 |  | £0.33 | £0.33 | 1 | £0.33
7 | RL1, RL2, RL3, RL4, RL5, RL6, RL7, RL8, RL9, RL10, RL15, RL16, RL17, RL18, RL19, RL22 | 16 |  | General Purpose Relay | G5LE | SPDT |  | Omron Electronics | G5LE-1-VD DC12 | Mouser | 653-G5LE-1-VDDC12 |  |  | £1.07 | Cut Tape | 1000 |  | £17.12 | £17.12 | 16 | £17.12
8 | X1, X2, X5 | 3 |  | SMA Connector | Through hole SMA |  |  | Linx Technologies | CONSMA002-L-G | Mouser | 712-CONSMA002-L-G | Digi-Key | CONSMA002-L-G-ND | £3.11 | Cut Tape | 1000 |  | £9.33 | £9.33 | 3 | £9.33
8 | X3, X4, X6, X7, X9, X10 | 6 |  | Terminal Block | 6.35mm 2 pos | 2 pos |  | Phoenix Contact | 1714955 | Mouser | 651-1714955 | Digi-Key | 277-1269-ND | £0.96 | Cut Tape | 1000 |  | £5.78 | £5.78 | 6 | £5.78
8 | X8 | 1 |  | BNC RF Connector | TH BNC |  |  | Amphenol RF | 112404 | Mouser | 523-112404 |  |  | £2.18 | Cut Tape | 1000 |  | £2.18 | £2.18 | 1 | £2.18
 |  |  |  |  |  |  |  |  |  |  |  |  |  |  | Cut Tape | 1000 |  | £0.00 | £0.00 | 0 | £0.00
 |  |  |  |  |  |  |  |  |  |  |  |  |  |  | Cut Tape | 1000 |  | £0.00 | £0.00 | 0 | £0.00
 |  |  |  |  |  |  |  |  |  |  |  |  |  |  | Cut Tape | 1000 |  | £0.00 | £0.00 | 0 | £0.00
 |  |  |  |  |  |  |  |  |  |  |  |  |  |  | Cut Tape | 1000 |  | £0.00 | £0.00 | 0 | £0.00
 |  |  |  |  |  |  |  |  |  |  |  |  |  |  | Cut Tape | 1000 |  | £0.00 | £0.00 | 0 | £0.00
 |  |  |  |  |  |  |  |  |  |  |  |  |  |  | Cut Tape | 1000 |  | £0.00 | £0.00 | 0 | £0.00
 |  |  |  |  |  |  |  |  |  |  |  |  |  |  | Cut Tape | 1000 |  | £0.00 | £0.00 | 0 | £0.00
 |  |  |  |  |  |  |  |  |  |  |  |  |  |  | Cut Tape | 1000 |  | £0.00 | £0.00 | 0 | £0.00
 |  |  |  |  |  |  |  |  |  |  |  |  |  |  | Cut Tape | 1000 |  | £0.00 | £0.00 | 0 | £0.00
 |  |  |  |  |  |  |  |  |  |  |  |  |  |  | Cut Tape | 1000 |  | £0.00 | £0.00 | 0 | £0.00
 |  |  |  |  |  |  |  |  |  |  |  |  |  |  | Cut Tape | 1000 |  | £0.00 | £0.00 | 0 | £0.00
 |  |  |  |  |  |  |  |  |  |  |  |  |  |  | Cut Tape | 1000 |  | £0.00 | £0.00 | 0 | £0.00
 |  |  |  |  |  |  |  |  |  |  |  |  |  |  | Cut Tape | 1000 |  | £0.00 | £0.00 | 0 | £0.00
 |  |  |  |  |  |  |  |  |  |  |  |  |  |  | Cut Tape | 1000 |  | £0.00 | £0.00 | 0 | £0.00
 |  |  |  |  |  |  |  |  |  |  |  |  |  |  | Cut Tape | 1000 |  | £0.00 | £0.00 | 0 | £0.00
 |  |  |  |  |  |  |  |  |  |  |  |  |  |  | Cut Tape | 1000 |  | £0.00 | £0.00 | 0 | £0.00
 |  |  |  |  |  |  |  |  |  |  |  |  |  |  | Cut Tape | 1000 |  | £0.00 | £0.00 | 0 | £0.00
 |  |  |  |  |  |  |  |  |  |  |  |  |  |  | Cut Tape | 1000 |  | £0.00 | £0.00 | 0 | £0.00
 |  |  |  |  |  |  |  |  |  |  |  |  |  |  | Cut Tape | 1000 |  | £0.00 | £0.00 | 0 | £0.00
 |  |  |  |  |  |  |  |  |  |  |  |  |  |  | Cut Tape | 1000 |  | £0.00 | £0.00 | 0 | £0.00
 |  |  |  |  |  |  |  |  |  |  |  |  |  |  | Cut Tape | 1000 |  | £0.00 | £0.00 | 0 | £0.00
 |  |  |  |  |  |  |  |  |  |  |  |  |  |  | Cut Tape | 1000 |  | £0.00 | £0.00 | 0 | £0.00
 |  |  |  |  |  |  |  |  |  |  |  |  |  |  | Cut Tape | 1000 |  | £0.00 | £0.00 | 0 | £0.00
 |  |  |  |  |  |  |  |  |  |  |  |  |  |  | Cut Tape | 1000 |  | £0.00 | £0.00 | 0 | £0.00
 |  |  |  |  |  |  |  |  |  |  |  |  |  |  | Cut Tape | 1000 |  | £0.00 | £0.00 | 0 | £0.00
 |  |  |  |  |  |  |  |  |  |  |  |  |  |  | Cut Tape | 1000 |  | £0.00 | £0.00 | 0 | £0.00
 |  |  |  |  |  |  |  |  |  |  |  |  |  |  | Cut Tape | 1000 |  | £0.00 | £0.00 | 0 | £0.00
 |  |  |  |  |  |  |  |  |  |  |  |  |  |  | Cut Tape | 1000 |  | £0.00 | £0.00 | 0 | £0.00
 |  |  |  |  |  |  |  |  |  |  |  |  |  |  | Cut Tape | 1000 |  | £0.00 | £0.00 | 0 | £0.00
 |  |  |  |  |  |  |  |  |  |  |  |  |  |  | Cut Tape | 1000 |  | £0.00 | £0.00 | 0 | £0.00
 |  |  |  |  |  |  |  |  |  |  |  |  |  |  | Cut Tape | 1000 |  | £0.00 | £0.00 | 0 | £0.00
 |  |  |  |  |  |  |  |  |  |  |  |  |  |  | Cut Tape | 1000 |  | £0.00 | £0.00 | 0 | £0.00
 |  |  |  |  |  |  |  |  |  |  |  |  |  |  | Cut Tape | 1000 |  | £0.00 | £0.00 | 0 | £0.00
 |  |  |  |  |  |  |  |  |  |  |  |  |  |  | Cut Tape | 1000 |  | £0.00 | £0.00 | 0 | £0.00
 |  |  |  |  |  |  |  |  |  |  |  |  |  |  | Cut Tape | 1000 |  | £0.00 | £0.00 | 0 | £0.00
 |  |  |  |  |  |  |  |  |  |  |  |  |  |  | Cut Tape | 1000 |  | £0.00 | £0.00 | 0 | £0.00
 |  |  |  |  |  |  |  |  |  |  |  |  |  |  | Cut Tape | 1000 |  | £0.00 | £0.00 | 0 | £0.00
 |  |  |  |  |  |  |  |  |  |  |  |  |  |  | Cut Tape | 1000 |  | £0.00 | £0.00 | 0 | £0.00
 |  |  |  |  |  |  |  |  |  |  |  |  |  |  | Cut Tape | 1000 |  | £0.00 | £0.00 | 0 | £0.00
 |  |  |  |  |  |  |  |  |  |  |  |  |  |  | Cut Tape | 1000 |  | £0.00 | £0.00 | 0 | £0.00
 |  |  |  |  |  |  |  |  |  |  |  |  |  |  | Cut Tape | 1000 |  | £0.00 | £0.00 | 0 | £0.00
 |  |  |  |  |  |  |  |  |  |  |  |  |  |  | Cut Tape | 1000 |  | £0.00 | £0.00 | 0 | £0.00
 |  |  |  |  |  |  |  |  |  |  |  |  |  |  | Cut Tape | 1000 |  | £0.00 | £0.00 | 0 | £0.00
 |  |  |  |  |  |  |  |  |  |  |  |  |  |  | Cut Tape | 1000 |  | £0.00 | £0.00 | 0 | £0.00
 |  |  |  |  |  |  |  |  |  |  |  |  |  |  | Cut Tape | 1000 |  | £0.00 | £0.00 | 0 | £0.00
 |  |  |  |  |  |  |  |  |  |  |  |  |  |  | Cut Tape | 1000 |  | £0.00 | £0.00 | 0 | £0.00
 |  |  |  |  |  |  |  |  |  |  |  |  |  |  | Cut Tape | 1000 |  | £0.00 | £0.00 | 0 | £0.00
 |  |  |  |  |  |  |  |  |  |  |  |  |  |  | Cut Tape | 1000 |  | £0.00 | £0.00 | 0 | £0.00
 |  |  |  |  |  |  |  |  |  |  |  |  |  |  | Cut Tape | 1000 |  | £0.00 | £0.00 | 0 | £0.00
 |  |  |  |  |  |  |  |  |  |  |  |  |  |  | Cut Tape | 1000 |  | £0.00 | £0.00 | 0 | £0.00
 |  |  |  |  |  |  |  |  |  |  |  |  |  |  | Cut Tape | 1000 |  | £0.00 | £0.00 | 0 | £0.00
 |  |  |  |  |  |  |  |  |  |  |  |  |  |  | Cut Tape | 1000 |  | £0.00 | £0.00 | 0 | £0.00
 |  |  |  |  |  |  |  |  |  |  |  |  |  |  | Cut Tape | 1000 |  | £0.00 | £0.00 | 0 | £0.00
 |  |  |  |  |  |  |  |  |  |  |  |  |  |  | Cut Tape | 1000 |  | £0.00 | £0.00 | 0 | £0.00
 |  |  |  |  |  |  |  |  |  |  |  |  |  |  | Cut Tape | 1000 |  | £0.00 | £0.00 | 0 | £0.00
 |  |  |  |  |  |  |  |  |  |  |  |  |  |  | Cut Tape | 1000 |  | £0.00 | £0.00 | 0 | £0.00
 |  |  |  |  |  |  |  |  |  |  |  |  |  |  | Cut Tape | 1000 |  | £0.00 | £0.00 | 0 | £0.00
 |  |  |  |  |  |  |  |  |  |  |  |  |  |  | Cut Tape | 1000 |  | £0.00 | £0.00 | 0 | £0.00
 |  |  |  |  |  |  |  |  |  |  |  |  |  |  | Cut Tape | 1000 |  | £0.00 | £0.00 | 0 | £0.00
 |  |  |  |  |  |  |  |  |  |  |  |  |  |  | Cut Tape | 1000 |  | £0.00 | £0.00 | 0 | £0.00
 |  |  |  |  |  |  |  |  |  |  |  |  |  |  | Cut Tape | 1000 |  | £0.00 | £0.00 | 0 | £0.00
 |  |  |  |  |  |  |  |  |  |  |  |  |  |  | Cut Tape | 1000 |  | £0.00 | £0.00 | 0 | £0.00
 |  |  |  |  |  |  |  |  |  |  |  |  |  |  | Cut Tape | 1000 |  | £0.00 | £0.00 | 0 | £0.00
 |  |  |  |  |  |  |  |  |  |  |  |  |  |  | Cut Tape | 1000 |  | £0.00 | £0.00 | 0 | £0.00
 |  |  |  |  |  |  |  |  |  |  |  |  |  |  | Cut Tape | 1000 |  | £0.00 | £0.00 | 0 | £0.00
 |  |  |  |  |  |  |  |  |  |  |  |  |  |  | Cut Tape | 1000 |  | £0.00 | £0.00 | 0 | £0.00
 |  |  |  |  |  |  |  |  |  |  |  |  |  |  | Cut Tape | 1000 |  | £0.00 | £0.00 | 0 | £0.00
 |  |  |  |  |  |  |  |  |  |  |  |  |  |  | Cut Tape | 1000 |  | £0.00 | £0.00 | 0 | £0.00
 |  |  |  |  |  |  |  |  |  |  |  |  |  |  | Cut Tape | 1000 |  | £0.00 | £0.00 | 0 | £0.00
 |  |  |  |  |  |  |  |  |  |  |  |  |  |  | Cut Tape | 1000 |  | £0.00 | £0.00 | 0 | £0.00
 |  |  |  |  |  |  |  |  |  |  |  |  |  |  | Cut Tape | 1000 |  | £0.00 | £0.00 | 0 | £0.00
 |  |  |  |  |  |  |  |  |  |  |  |  |  |  | Cut Tape | 1000 |  | £0.00 | £0.00 | 0 | £0.00
 |  |  |  |  |  |  |  |  |  |  |  |  |  |  | Cut Tape | 1000 |  | £0.00 | £0.00 | 0 | £0.00
 |  |  |  |  |  |  |  |  |  |  |  |  |  |  | Cut Tape | 1000 |  | £0.00 | £0.00 | 0 | £0.00
 |  |  |  |  |  |  |  |  |  |  |  |  |  |  | Cut Tape | 1000 |  | £0.00 | £0.00 | 0 | £0.00
 |  |  |  |  |  |  |  |  |  |  |  |  |  |  | Cut Tape | 1000 |  | £0.00 | £0.00 | 0 | £0.00
 |  |  |  |  |  |  |  |  |  |  |  |  |  |  | Cut Tape | 1000 |  | £0.00 | £0.00 | 0 | £0.00
 |  |  |  |  |  |  |  |  |  |  |  |  |  |  | Cut Tape | 1000 |  | £0.00 | £0.00 | 0 | £0.00
 |  |  |  |  |  |  |  |  |  |  |  |  |  |  | Cut Tape | 1000 |  | £0.00 | £0.00 | 0 | £0.00
 |  |  |  |  |  |  |  |  |  |  |  |  |  |  | Cut Tape | 1000 |  | £0.00 | £0.00 | 0 | £0.00
 |  |  |  |  |  |  |  |  |  |  |  |  |  |  | Cut Tape | 1000 |  | £0.00 | £0.00 | 0 | £0.00
 |  |  |  |  |  |  |  |  |  |  |  |  |  |  | Cut Tape | 1000 |  | £0.00 | £0.00 | 0 | £0.00
 |  |  |  |  |  |  |  |  |  |  |  |  |  |  | Cut Tape | 1000 |  | £0.00 | £0.00 | 0 | £0.00
 |  |  |  |  |  |  |  |  |  |  |  |  |  |  | Cut Tape | 1000 |  | £0.00 | £0.00 | 0 | £0.00
 |  |  |  |  |  |  |  |  |  |  |  |  |  |  | Cut Tape | 1000 |  | £0.00 | £0.00 | 0 | £0.00
 |  |  |  |  |  |  |  |  |  |  |  |  |  |  | Cut Tape | 1000 |  | £0.00 | £0.00 | 0 | £0.00
 |  |  |  |  |  |  |  |  |  |  |  |  |  |  | Cut Tape | 1000 |  | £0.00 | £0.00 | 0 | £0.00
 |  |  |  |  |  |  |  |  |  |  |  |  |  |  | Cut Tape | 1000 |  | £0.00 | £0.00 | 0 | £0.00
 |  |  |  |  |  |  |  |  |  |  |  |  |  |  | Cut Tape | 1000 |  | £0.00 | £0.00 | 0 | £0.00
 |  |  |  |  |  |  |  |  |  |  |  |  |  |  | Cut Tape | 1000 |  | £0.00 | £0.00 | 0 | £0.00
 |  |  |  |  |  |  |  |  |  |  |  |  |  |  | Cut Tape | 1000 |  | £0.00 | £0.00 | 0 | £0.00
 |  |  |  |  |  |  |  |  |  |  |  |  |  |  | Cut Tape | 1000 |  | £0.00 | £0.00 | 0 | £0.00
 |  |  |  |  |  |  |  |  |  |  |  |  |  |  | Cut Tape | 1000 |  | £0.00 | £0.00 | 0 | £0.00
 |  |  |  |  |  |  |  |  |  |  |  |  |  |  | Cut Tape | 1000 |  | £0.00 | £0.00 | 0 | £0.00
 |  |  |  |  |  |  |  |  |  |  |  |  |  |  | Cut Tape | 1000 |  | £0.00 | £0.00 | 0 | £0.00
 |  |  |  |  |  |  |  |  |  |  |  |  |  |  | Cut Tape | 1000 |  | £0.00 | £0.00 | 0 | £0.00
 |  |  |  |  |  |  |  |  |  |  |  |  |  |  | Cut Tape | 1000 |  | £0.00 | £0.00 | 0 | £0.00
 |  |  |  |  |  |  |  |  |  |  |  |  |  |  | Cut Tape | 1000 |  | £0.00 | £0.00 | 0 | £0.00
 |  |  |  |  |  |  |  |  |  |  |  |  |  |  | Cut Tape | 1000 |  | £0.00 | £0.00 | 0 | £0.00
 |  |  |  |  |  |  |  |  |  |  |  |  |  |  | Cut Tape | 1000 |  | £0.00 | £0.00 | 0 | £0.00
 |  |  |  |  |  |  |  |  |  |  |  |  |  |  | Cut Tape | 1000 |  | £0.00 | £0.00 | 0 | £0.00
 |  |  |  |  |  |  |  |  |  |  |  |  |  |  | Cut Tape | 1000 |  | £0.00 | £0.00 | 0 | £0.00
 |  |  |  |  |  |  |  |  |  |  |  |  |  |  | Cut Tape | 1000 |  | £0.00 | £0.00 | 0 | £0.00
 |  |  |  |  |  |  |  |  |  |  |  |  |  |  | Cut Tape | 1000 |  | £0.00 | £0.00 | 0 | £0.00
 |  |  |  |  |  |  |  |  |  |  |  |  |  |  | Cut Tape | 1000 |  | £0.00 | £0.00 | 0 | £0.00
 |  |  |  |  |  |  |  |  |  |  |  |  |  |  | Cut Tape | 1000 |  | £0.00 | £0.00 | 0 | £0.00
 |  |  |  |  |  |  |  |  |  |  |  |  |  |  | Cut Tape | 1000 |  | £0.00 | £0.00 | 0 | £0.00
 |  |  |  |  |  |  |  |  |  |  |  |  |  |  | Cut Tape | 1000 |  | £0.00 | £0.00 | 0 | £0.00
 |  |  |  |  |  |  |  |  |  |  |  |  |  |  | Cut Tape | 1000 |  | £0.00 | £0.00 | 0 | £0.00
 |  |  |  |  |  |  |  |  |  |  |  |  |  |  | Cut Tape | 1000 |  | £0.00 | £0.00 | 0 | £0.00
 |  |  |  |  |  |  |  |  |  |  |  |  |  |  | Cut Tape | 1000 |  | £0.00 | £0.00 | 0 | £0.00
 |  |  |  |  |  |  |  |  |  |  |  |  |  |  | Cut Tape | 1000 |  | £0.00 | £0.00 | 0 | £0.00
 |  |  |  |  |  |  |  |  |  |  |  |  |  |  | Cut Tape | 1000 |  | £0.00 | £0.00 | 0 | £0.00
 |  |  |  |  |  |  |  |  |  |  |  |  |  |  | Cut Tape | 1000 |  | £0.00 | £0.00 | 0 | £0.00
 |  |  |  |  |  |  |  |  |  |  |  |  |  |  | Cut Tape | 1000 |  | £0.00 | £0.00 | 0 | £0.00
 |  |  |  |  |  |  |  |  |  |  |  |  |  |  | Cut Tape | 1000 |  | £0.00 | £0.00 | 0 | £0.00
 |  |  |  |  |  |  |  |  |  |  |  |  |  |  | Cut Tape | 1000 |  | £0.00 | £0.00 | 0 | £0.00
 |  |  |  |  |  |  |  |  |  |  |  |  |  |  | Cut Tape | 1000 |  | £0.00 | £0.00 | 0 | £0.00
 |  |  |  |  |  |  |  |  |  |  |  |  |  |  | Cut Tape | 1000 |  | £0.00 | £0.00 | 0 | £0.00
 |  |  |  |  |  |  |  |  |  |  |  |  |  |  | Cut Tape | 1000 |  | £0.00 | £0.00 | 0 | £0.00
 |  |  |  |  |  |  |  |  |  |  |  |  |  |  | Cut Tape | 1000 |  | £0.00 | £0.00 | 0 | £0.00
 |  |  |  |  |  |  |  |  |  |  |  |  |  |  | Cut Tape | 1000 |  | £0.00 | £0.00 | 0 | £0.00
 |  |  |  |  |  |  |  |  |  |  |  |  |  |  | Cut Tape | 1000 |  | £0.00 | £0.00 | 0 | £0.00
 |  |  |  |  |  |  |  |  |  |  |  |  |  |  | Cut Tape | 1000 |  | £0.00 | £0.00 | 0 | £0.00
 |  |  |  |  |  |  |  |  |  |  |  |  |  |  | Cut Tape | 1000 |  | £0.00 | £0.00 | 0 | £0.00
 |  |  |  |  |  |  |  |  |  |  |  |  |  |  | Cut Tape | 1000 |  | £0.00 | £0.00 | 0 | £0.00
 |  |  |  |  |  |  |  |  |  |  |  |  |  |  | Cut Tape | 1000 |  | £0.00 | £0.00 | 0 | £0.00
 |  |  |  |  |  |  |  |  |  |  |  |  |  |  | Cut Tape | 1000 |  | £0.00 | £0.00 | 0 | £0.00
 |  |  |  |  |  |  |  |  |  |  |  |  |  |  | Cut Tape | 1000 |  | £0.00 | £0.00 | 0 | £0.00
 |  |  |  |  |  |  |  |  |  |  |  |  |  |  | Cut Tape | 1000 |  | £0.00 | £0.00 | 0 | £0.00
 |  |  |  |  |  |  |  |  |  |  |  |  |  |  | Cut Tape | 1000 |  | £0.00 | £0.00 | 0 | £0.00
 |  |  |  |  |  |  |  |  |  |  |  |  |  |  | Cut Tape | 1000 |  | £0.00 | £0.00 | 0 | £0.00
 |  |  |  |  |  |  |  |  |  |  |  |  |  |  | Cut Tape | 1000 |  | £0.00 | £0.00 | 0 | £0.00
 |  |  |  |  |  |  |  |  |  |  |  |  |  |  | Cut Tape | 1000 |  | £0.00 | £0.00 | 0 | £0.00
 |  |  |  |  |  |  |  |  |  |  |  |  |  |  | Cut Tape | 1000 |  | £0.00 | £0.00 | 0 | £0.00
 |  |  |  |  |  |  |  |  |  |  |  |  |  |  | Cut Tape | 1000 |  | £0.00 | £0.00 | 0 | £0.00
 |  |  |  |  |  |  |  |  |  |  |  |  |  |  | Cut Tape | 1000 |  | £0.00 | £0.00 | 0 | £0.00
 |  |  |  |  |  |  |  |  |  |  |  |  |  |  | Cut Tape | 1000 |  | £0.00 | £0.00 | 0 | £0.00
 |  |  |  |  |  |  |  |  |  |  |  |  |  |  | Cut Tape | 1000 |  | £0.00 | £0.00 | 0 | £0.00
 |  |  |  |  |  |  |  |  |  |  |  |  |  |  | Cut Tape | 1000 |  | £0.00 | £0.00 | 0 | £0.00
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

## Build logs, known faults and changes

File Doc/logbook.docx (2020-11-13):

# Talking Ham Logbook

## System Architecture

There are 2 possible different possible overall system architecture of the system the difference between the two will be 1 works entirely off of a Raspberry pi or split between a Raspberry pi and an Atmel ATSAM3X8E AU, (same MCU on Arduino Due) the advantage between the 2 is the following

Just Raspberry Pi

This requires fewer components as you don’t require an additional MCU
No command translation between Raspberry Pi and Arduino

Combined Approach

This allows the code be separated between the two systems and the work load as well.
The MCU is more specially designed for use of controlling components
I already know how to code Arduinos

The Raspberry pi is needed in order to interface with the NANO VNAs used to monitor the input and output signals

### Version 1

The system architecture for V1 (the one with the Raspberry Pi and Arduino Due MCU) is shown in Figure 1.

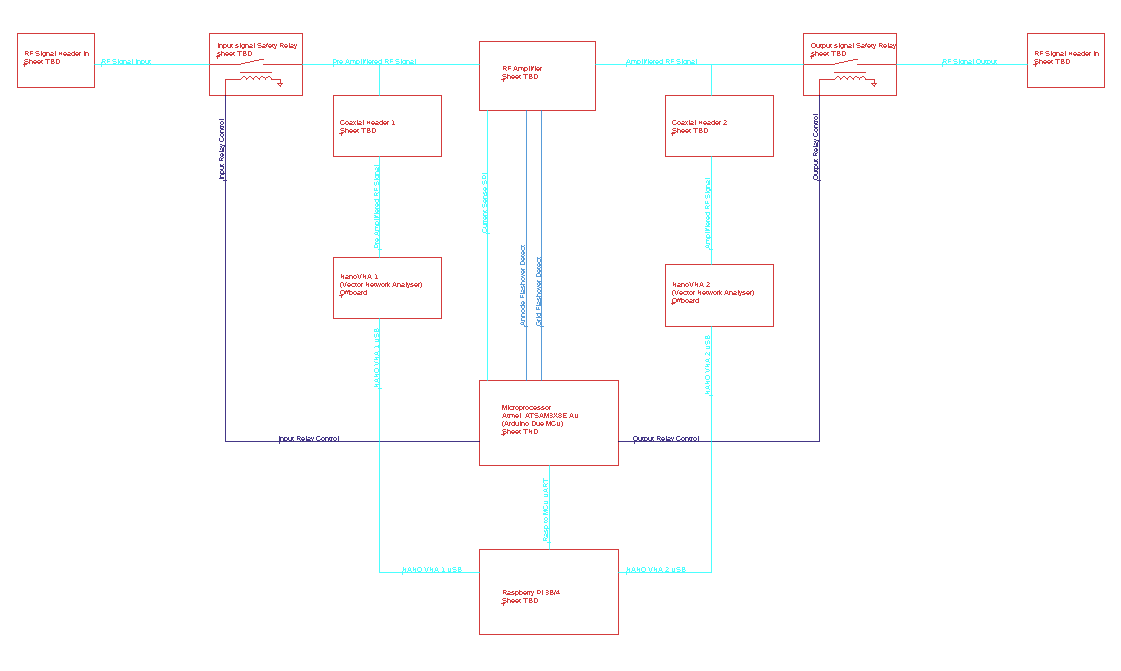
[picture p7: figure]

Figure 1- Overall System Arcitecture (With Rasp Pi and MCU)

### Version 2

The system architecture for V2 (the one with just the Raspberry Pi) is shown in Figure 2.

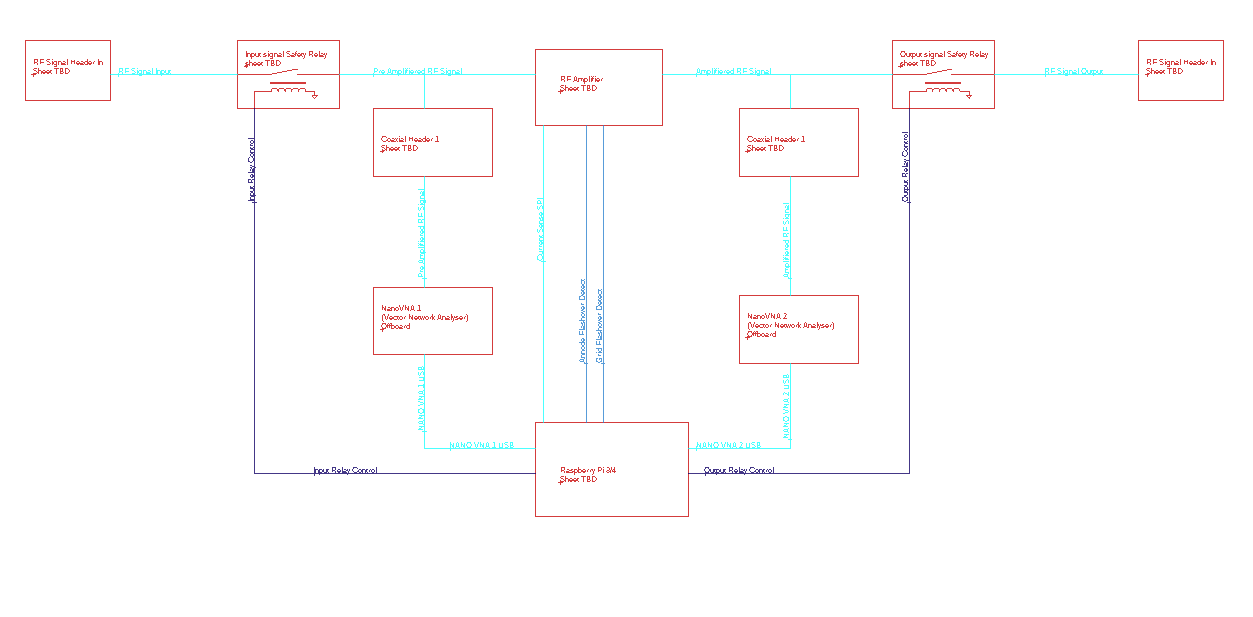
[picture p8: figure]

Figure 2- Overall System Architecture (With just Rasp Pi)

### RF Amplifier

The RF Amplifier mentioned in the Overall System Architecture is shown in more detail in Figure 3.

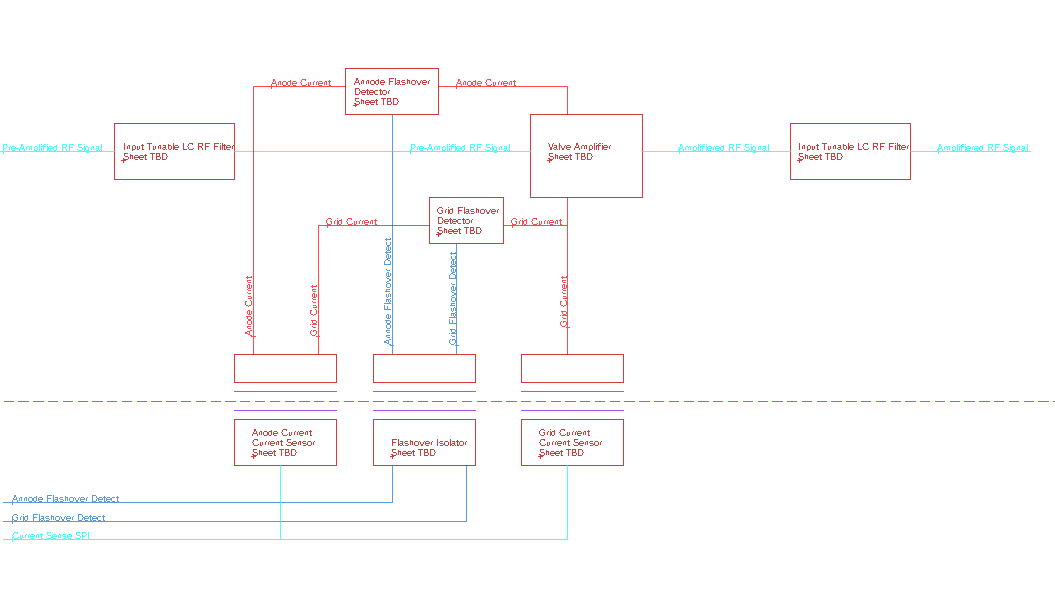
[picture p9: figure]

Figure 3- RF Amplifier System Architecture

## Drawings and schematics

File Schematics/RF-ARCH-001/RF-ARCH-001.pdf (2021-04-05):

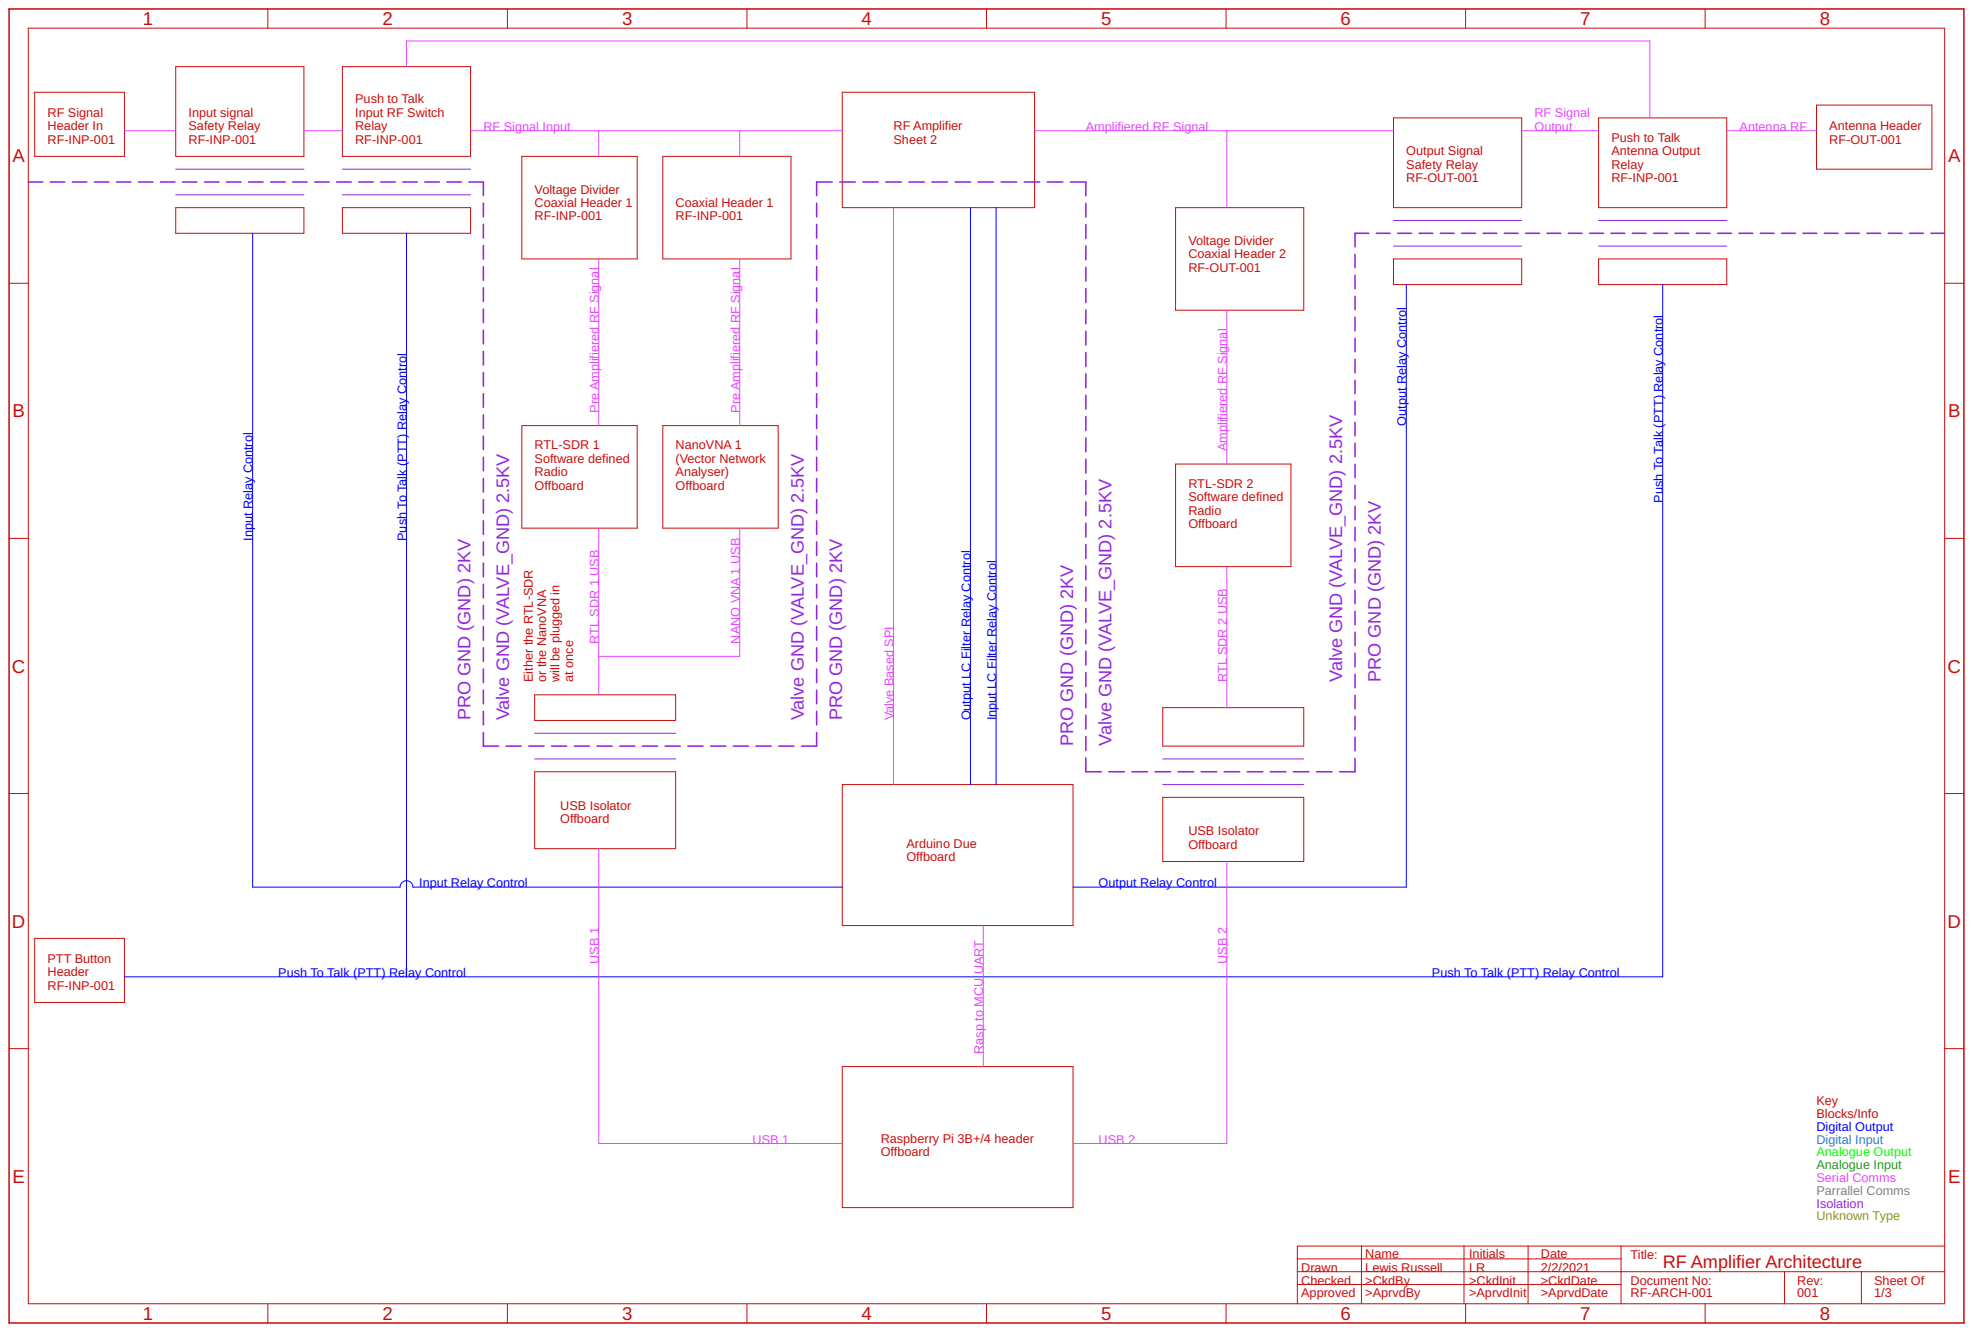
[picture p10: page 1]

Push To Talk (PTT) Relay Control

Name | Initials | Date | Title: RF Amplifier Architecture

Drawn | Lewis Russell | LR | 2/2/2021
Checked | >CkdBy | >CkdInit | >CkdDate | Document No: RF-ARCH-001 | Rev: | Sheet Of
Approved | >AprvdBy | >AprvdInit | >AprvdDate

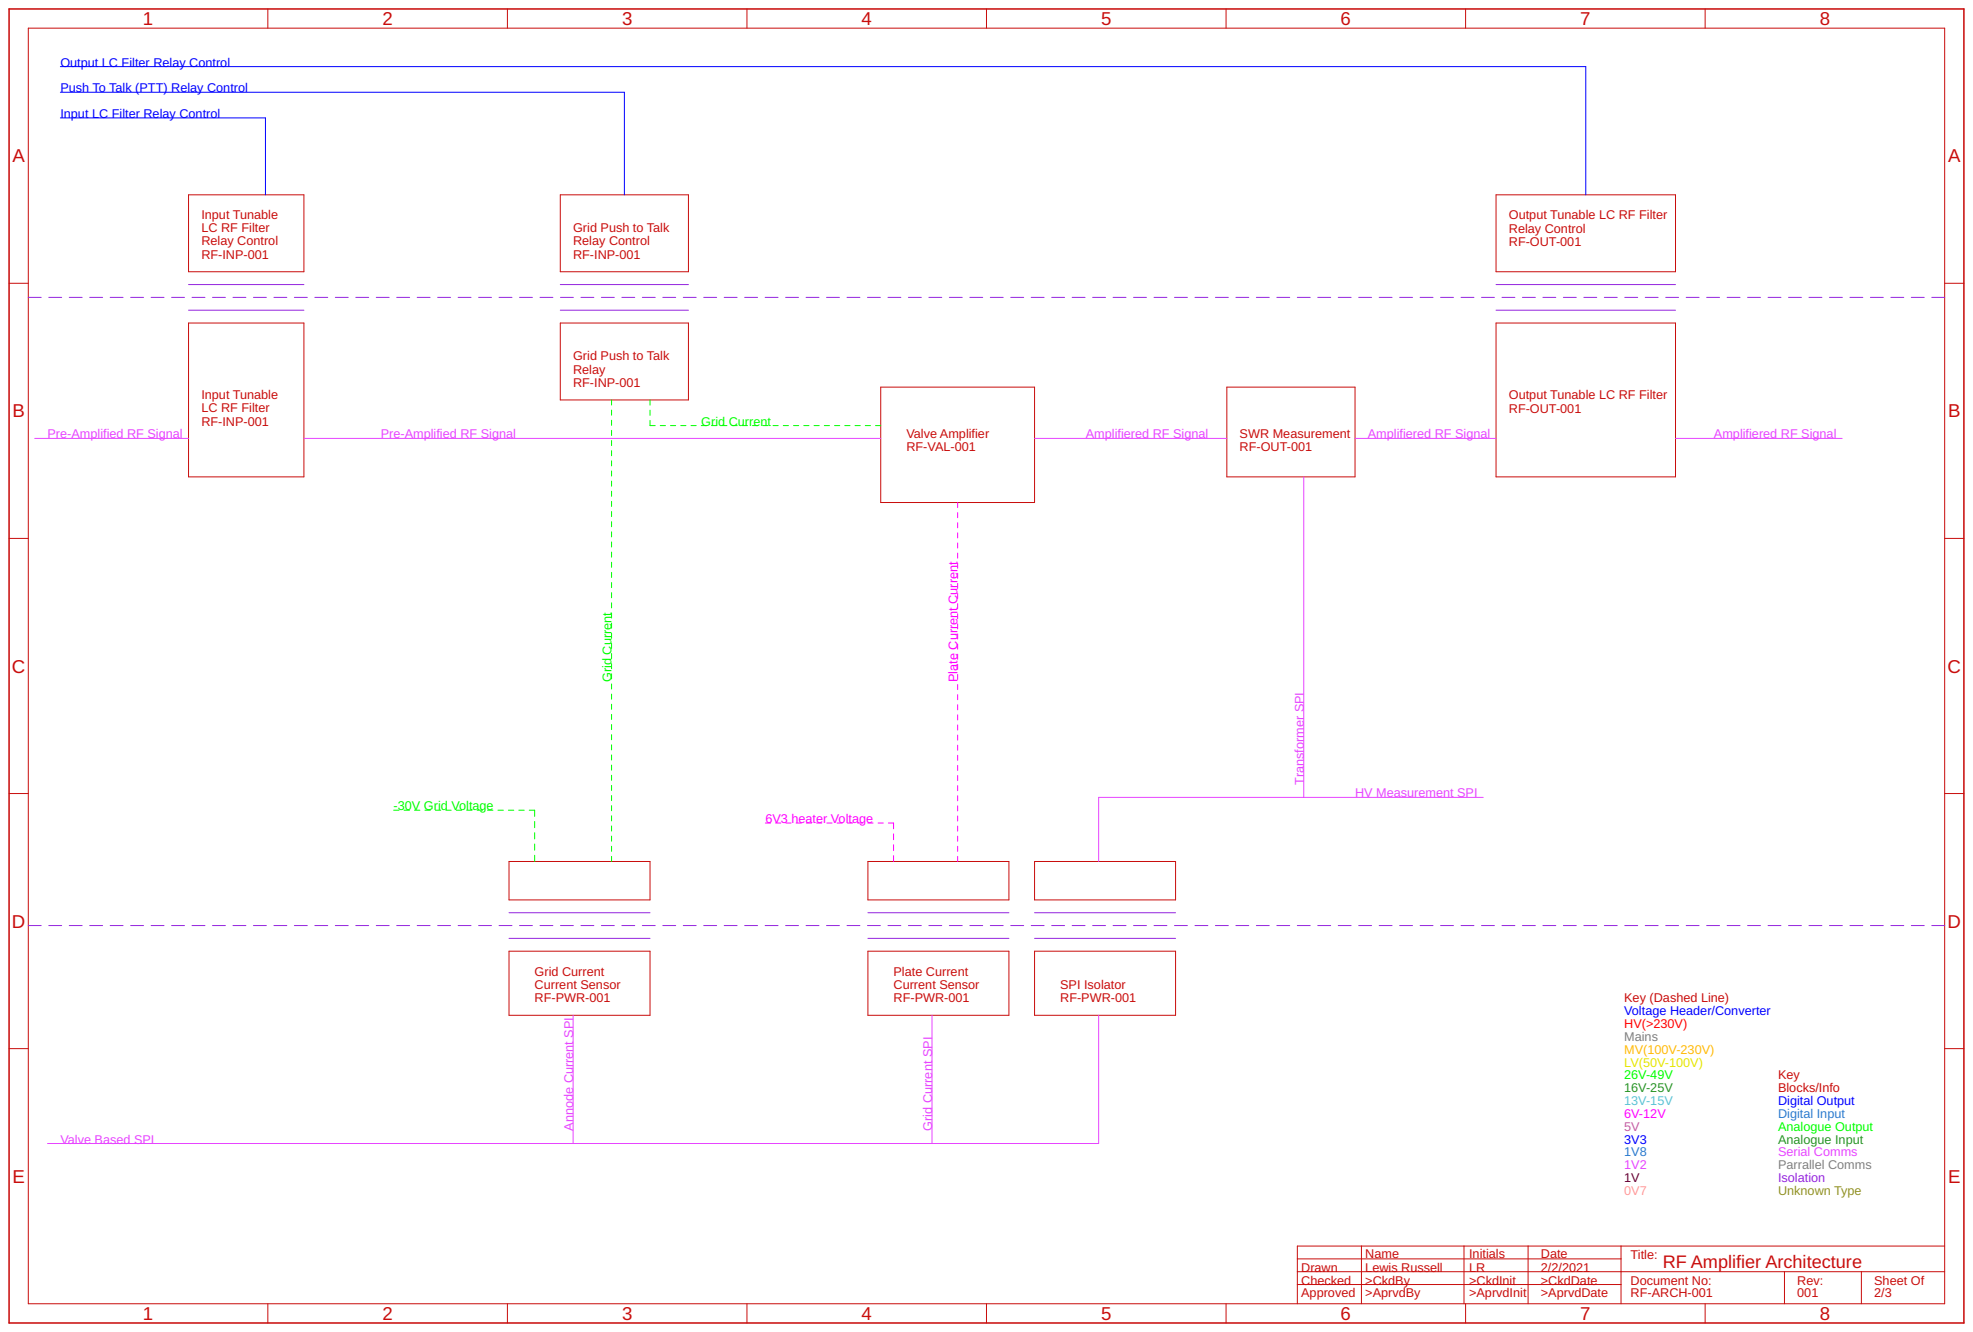
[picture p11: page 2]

Output LC Filter Relay Control

Push To Talk (PTT) Relay Control

Input LC Filter Relay Control

Output Tunable LC RF Filter
Relay Control
RF-OUT-001

Grid Push to Talk
RF-INP-001

Relay

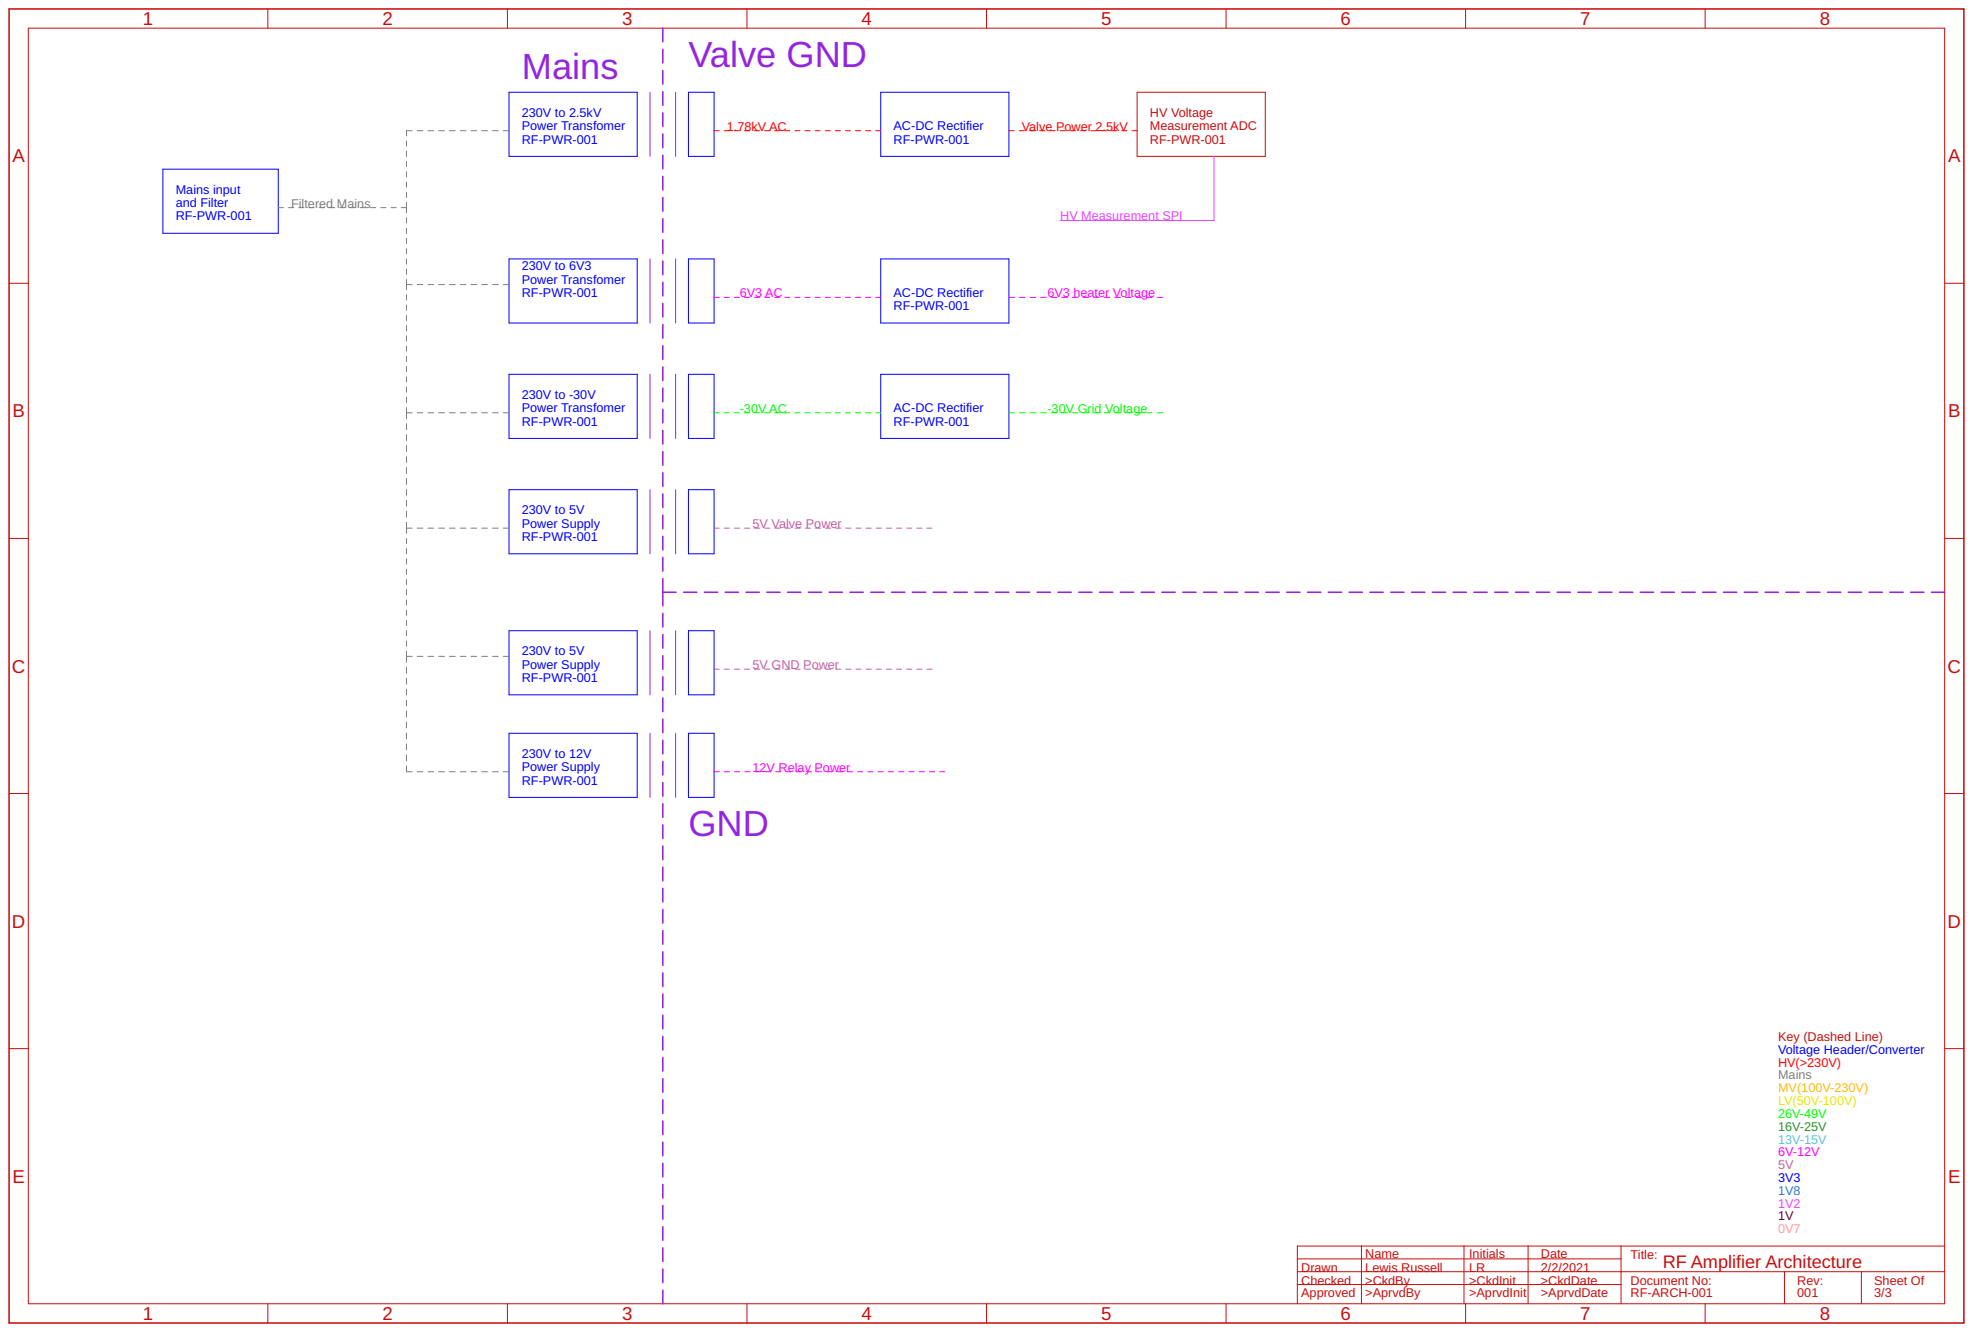
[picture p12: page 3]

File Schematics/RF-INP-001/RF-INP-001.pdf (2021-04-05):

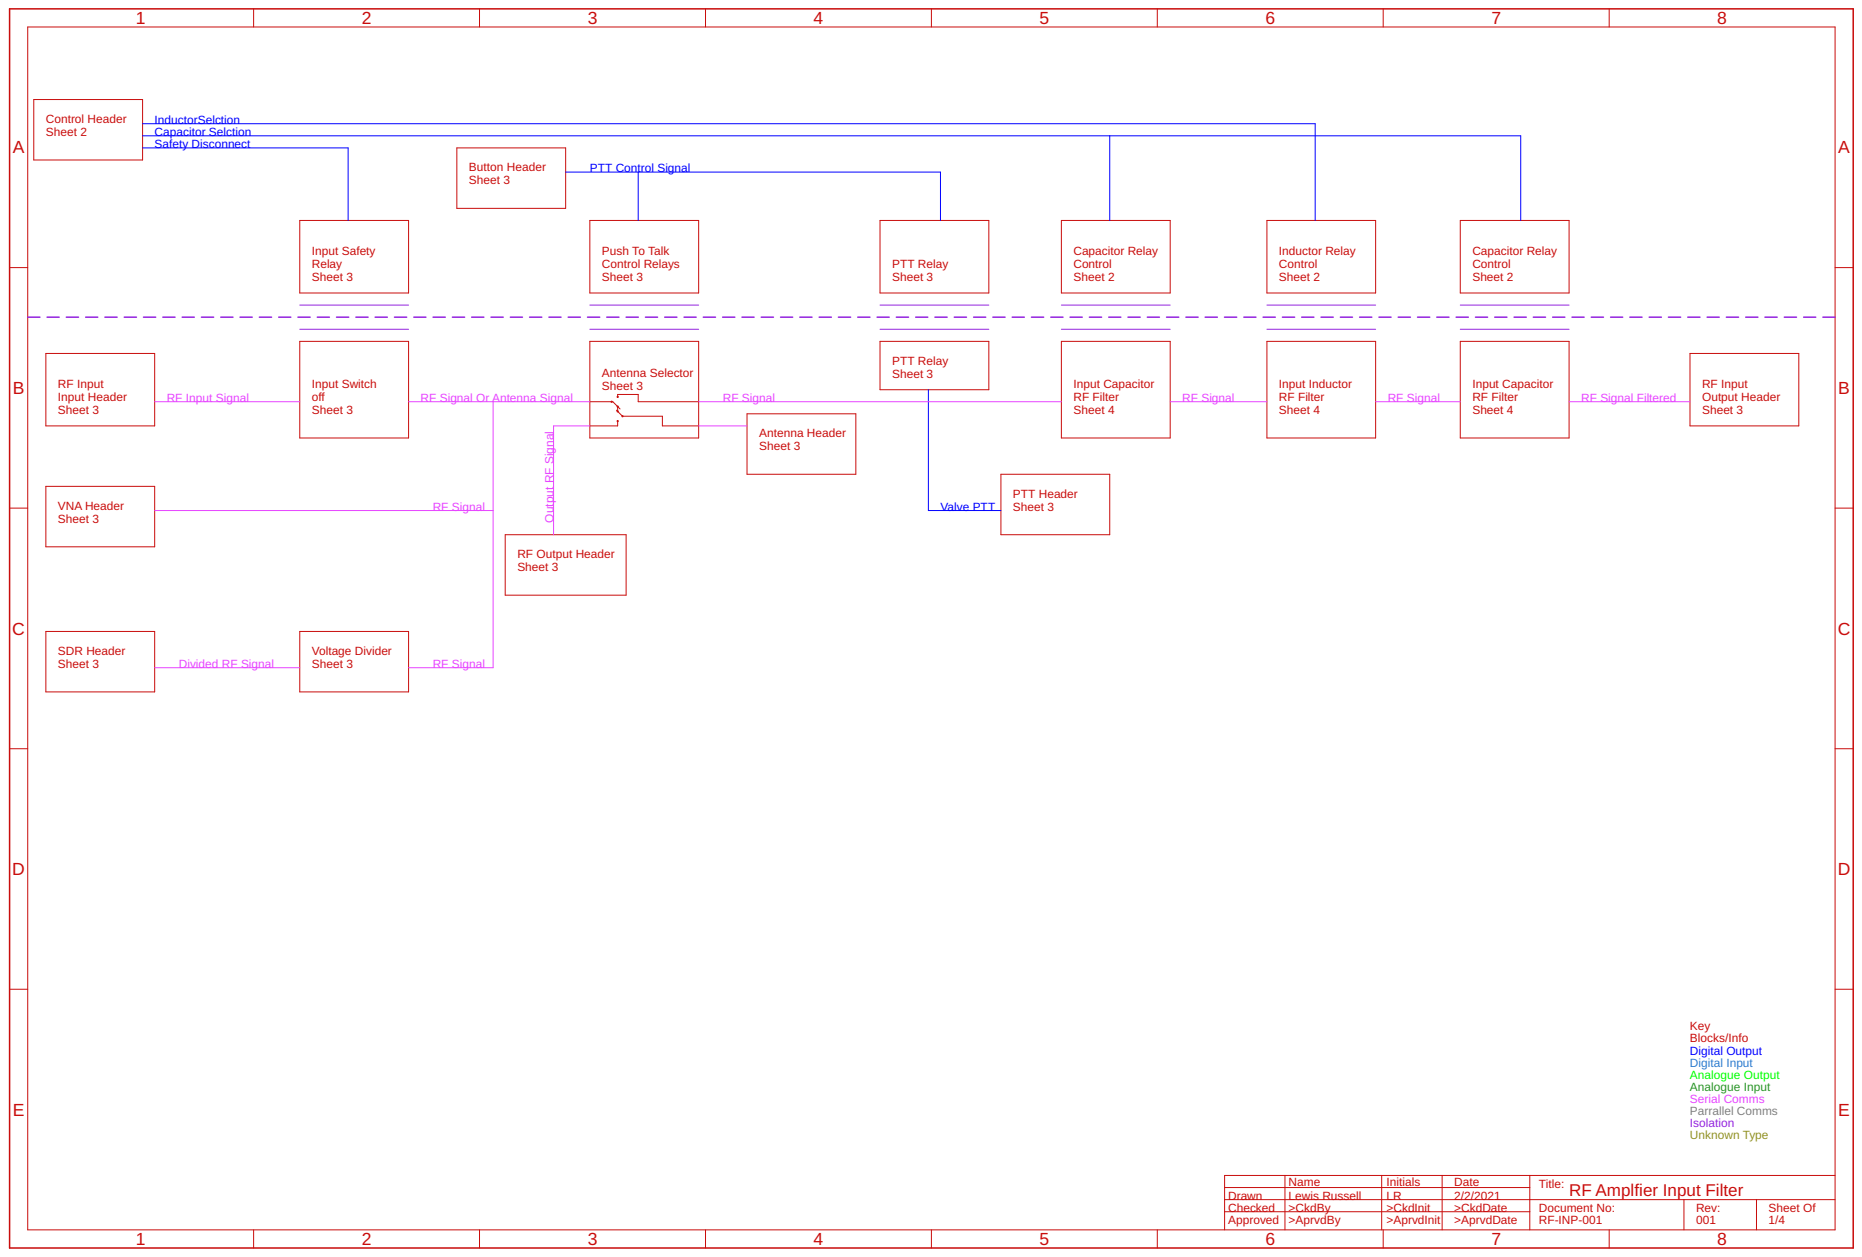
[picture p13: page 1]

Input Capacitor RF Filter Sheet 4

Input Inductor RF Filter Sheet 4

RF Output Header Sheet 3

Drawn Checked | Lewis Russell | LR | 2/2/2021

RF Amplfier Input Filter

RF-INP-001

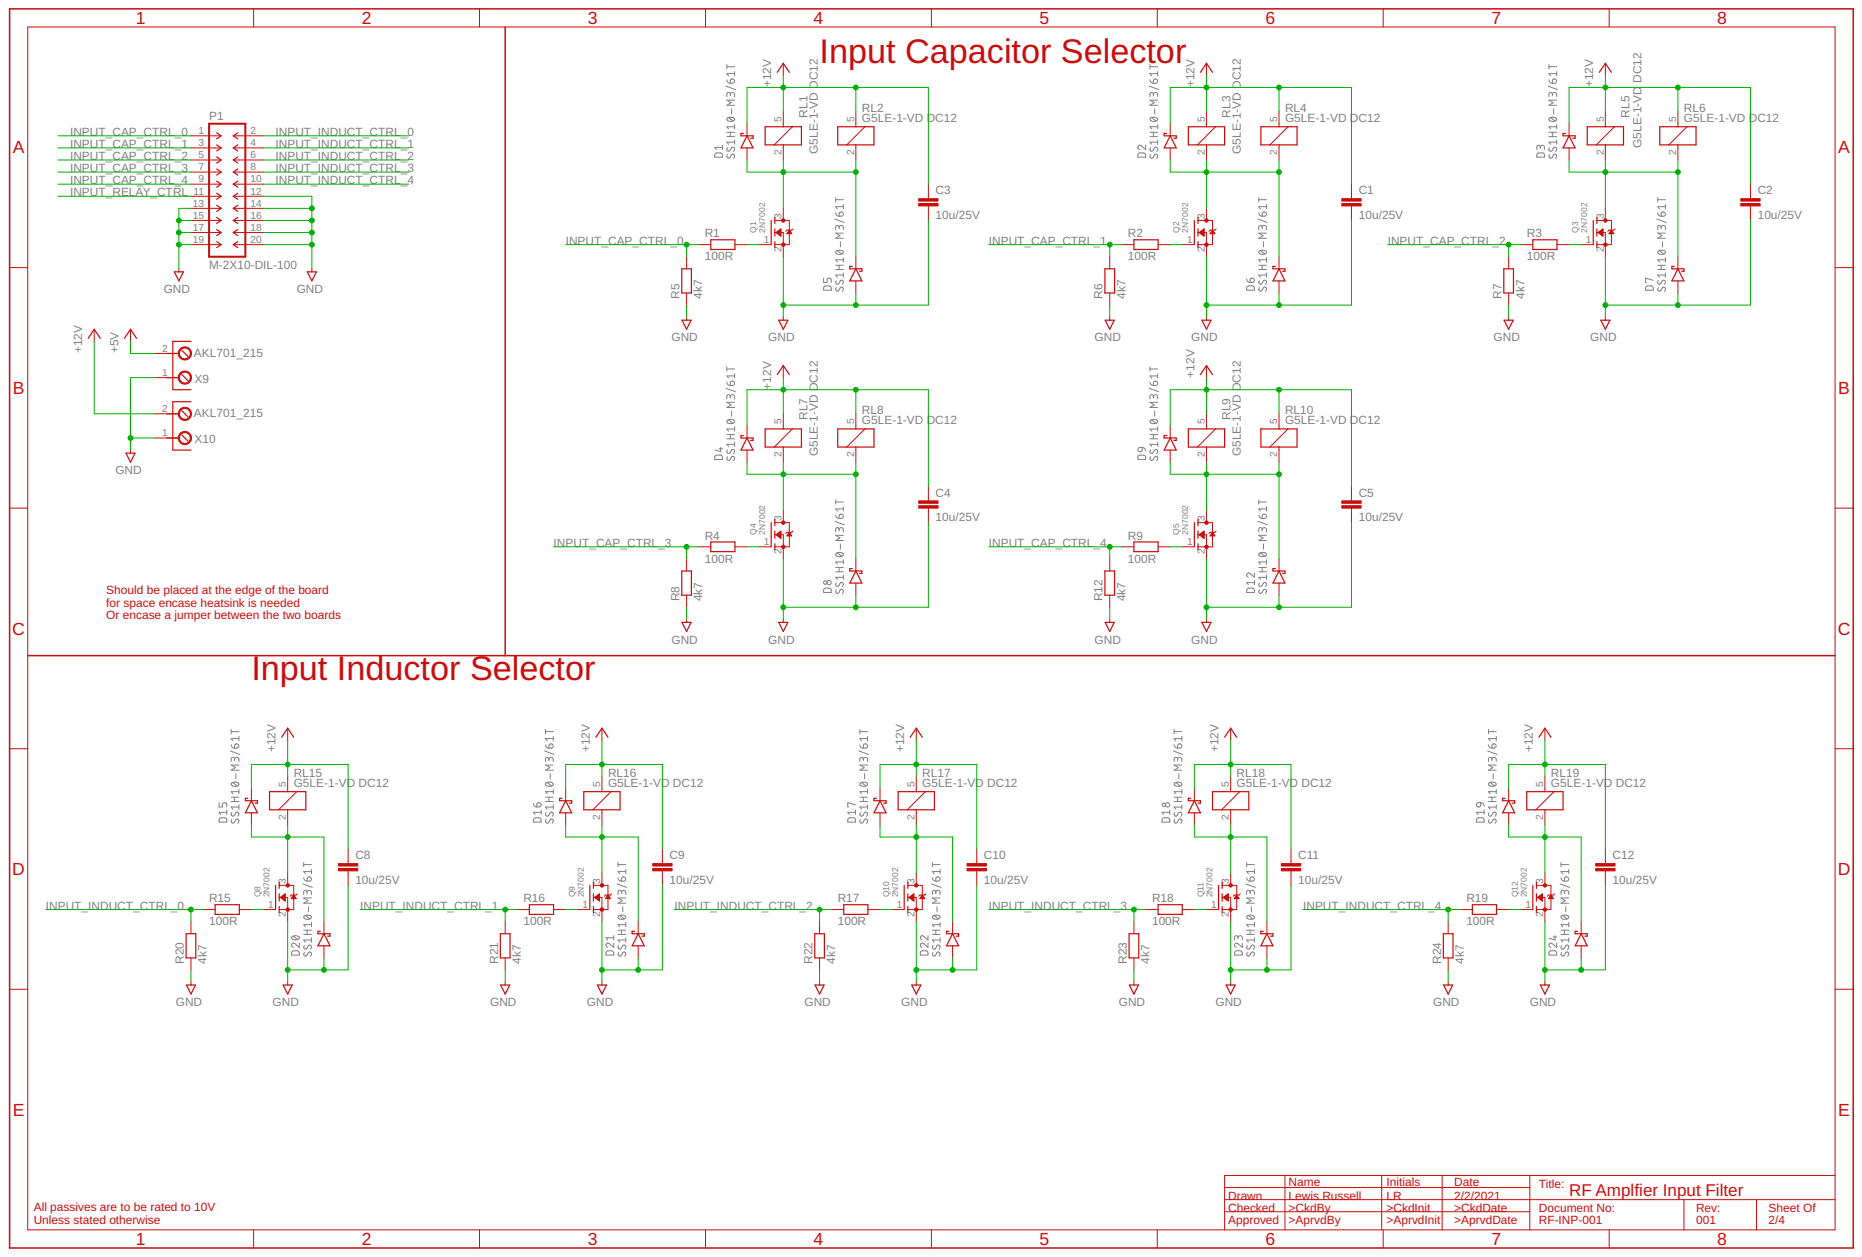
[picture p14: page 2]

15 | 16
17 | 18
19 | 20

Should be placed at the edge of the board
for space encase heatsink is needed
Or encase a jumper between the two boards

Drawn Checked | Lewis Russell | LR | 2/2/2021

RF Amplfier Input Filter

All passives are to be rated to 10V
Unless stated otherwise

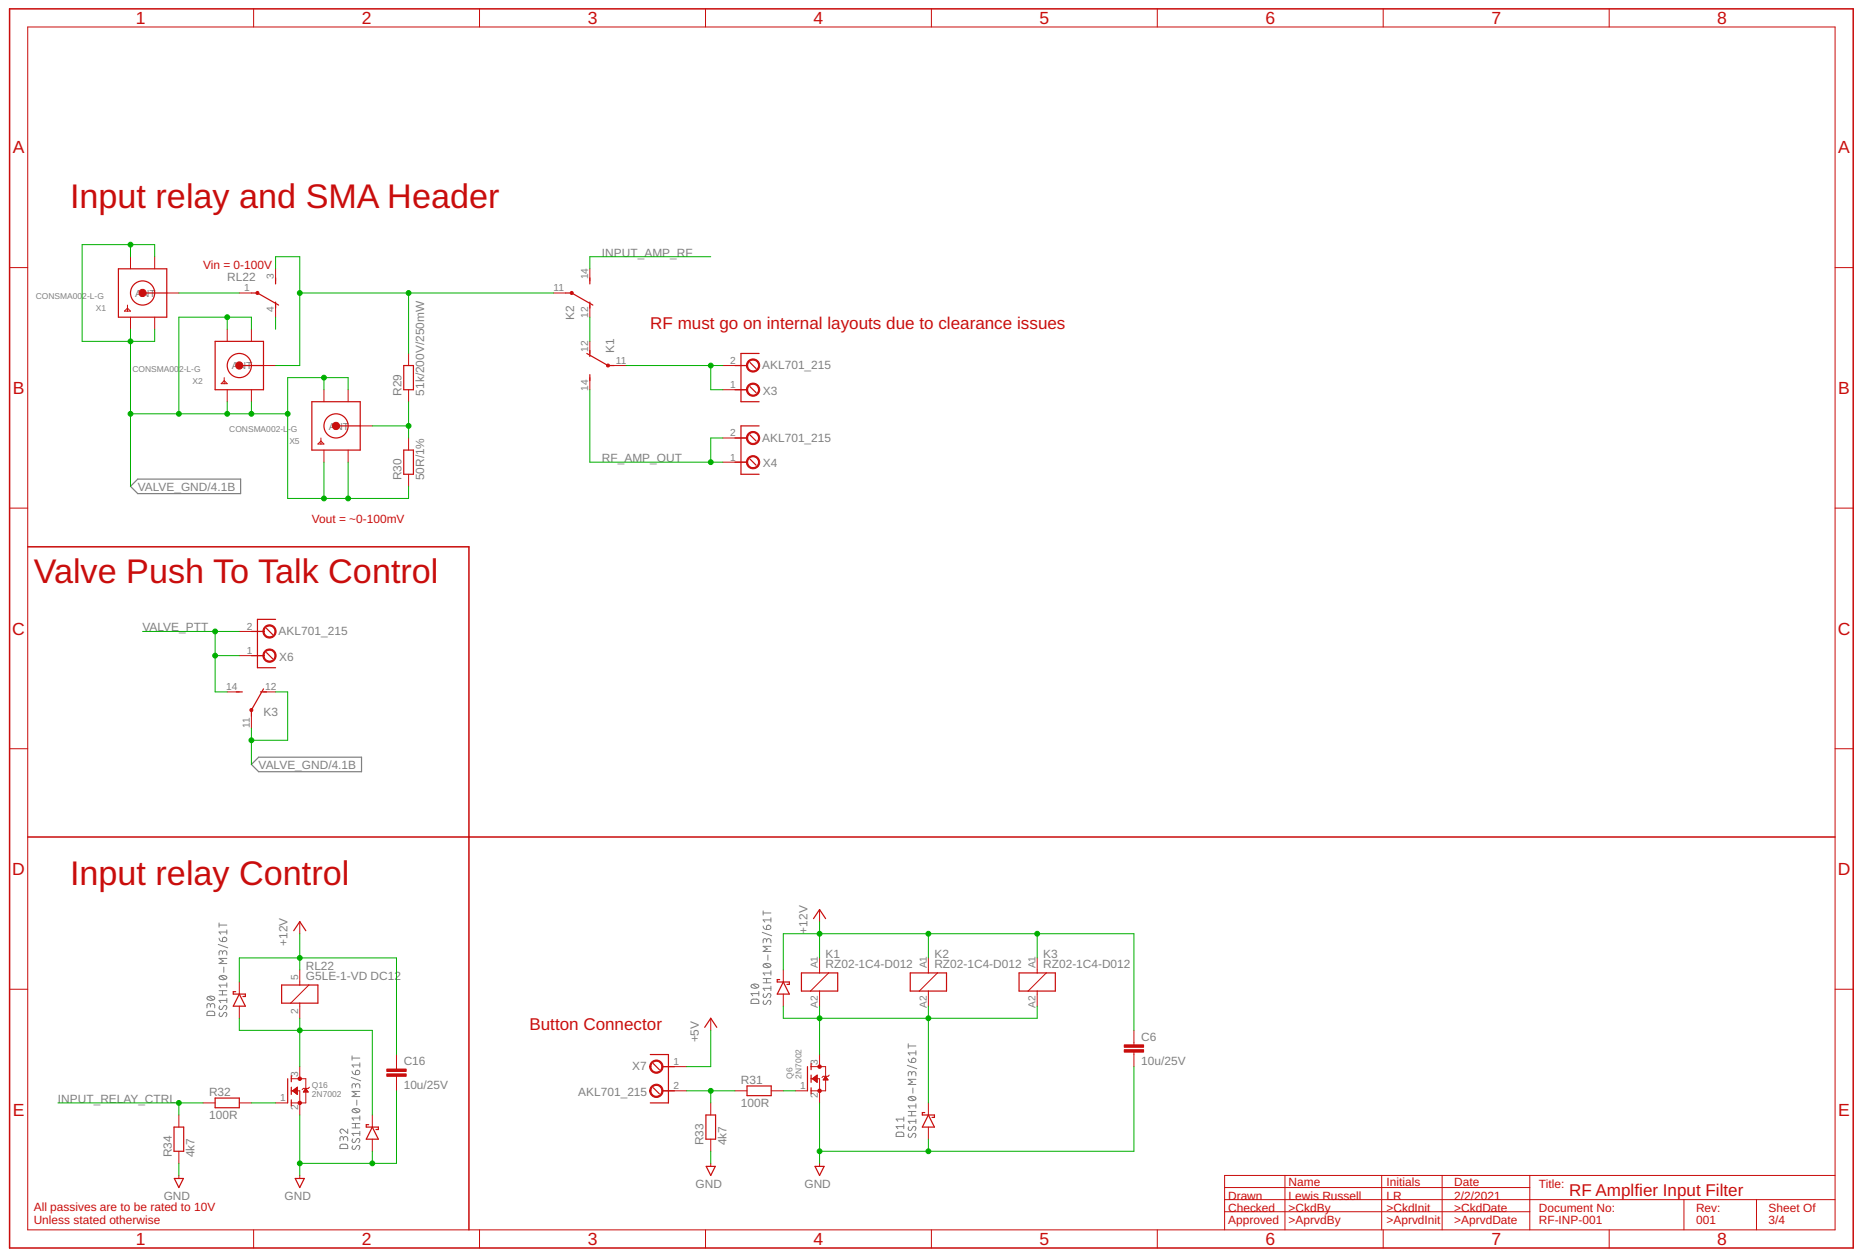
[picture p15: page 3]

Input relay and SMA Header

RF must go on internal layouts due to clearance issues

Valve Push To Talk Control

Drawn Checked | Lewis Russell | LR | 2/2/2021

RF Amplfier Input Filter

All passives are to be rated to 10V

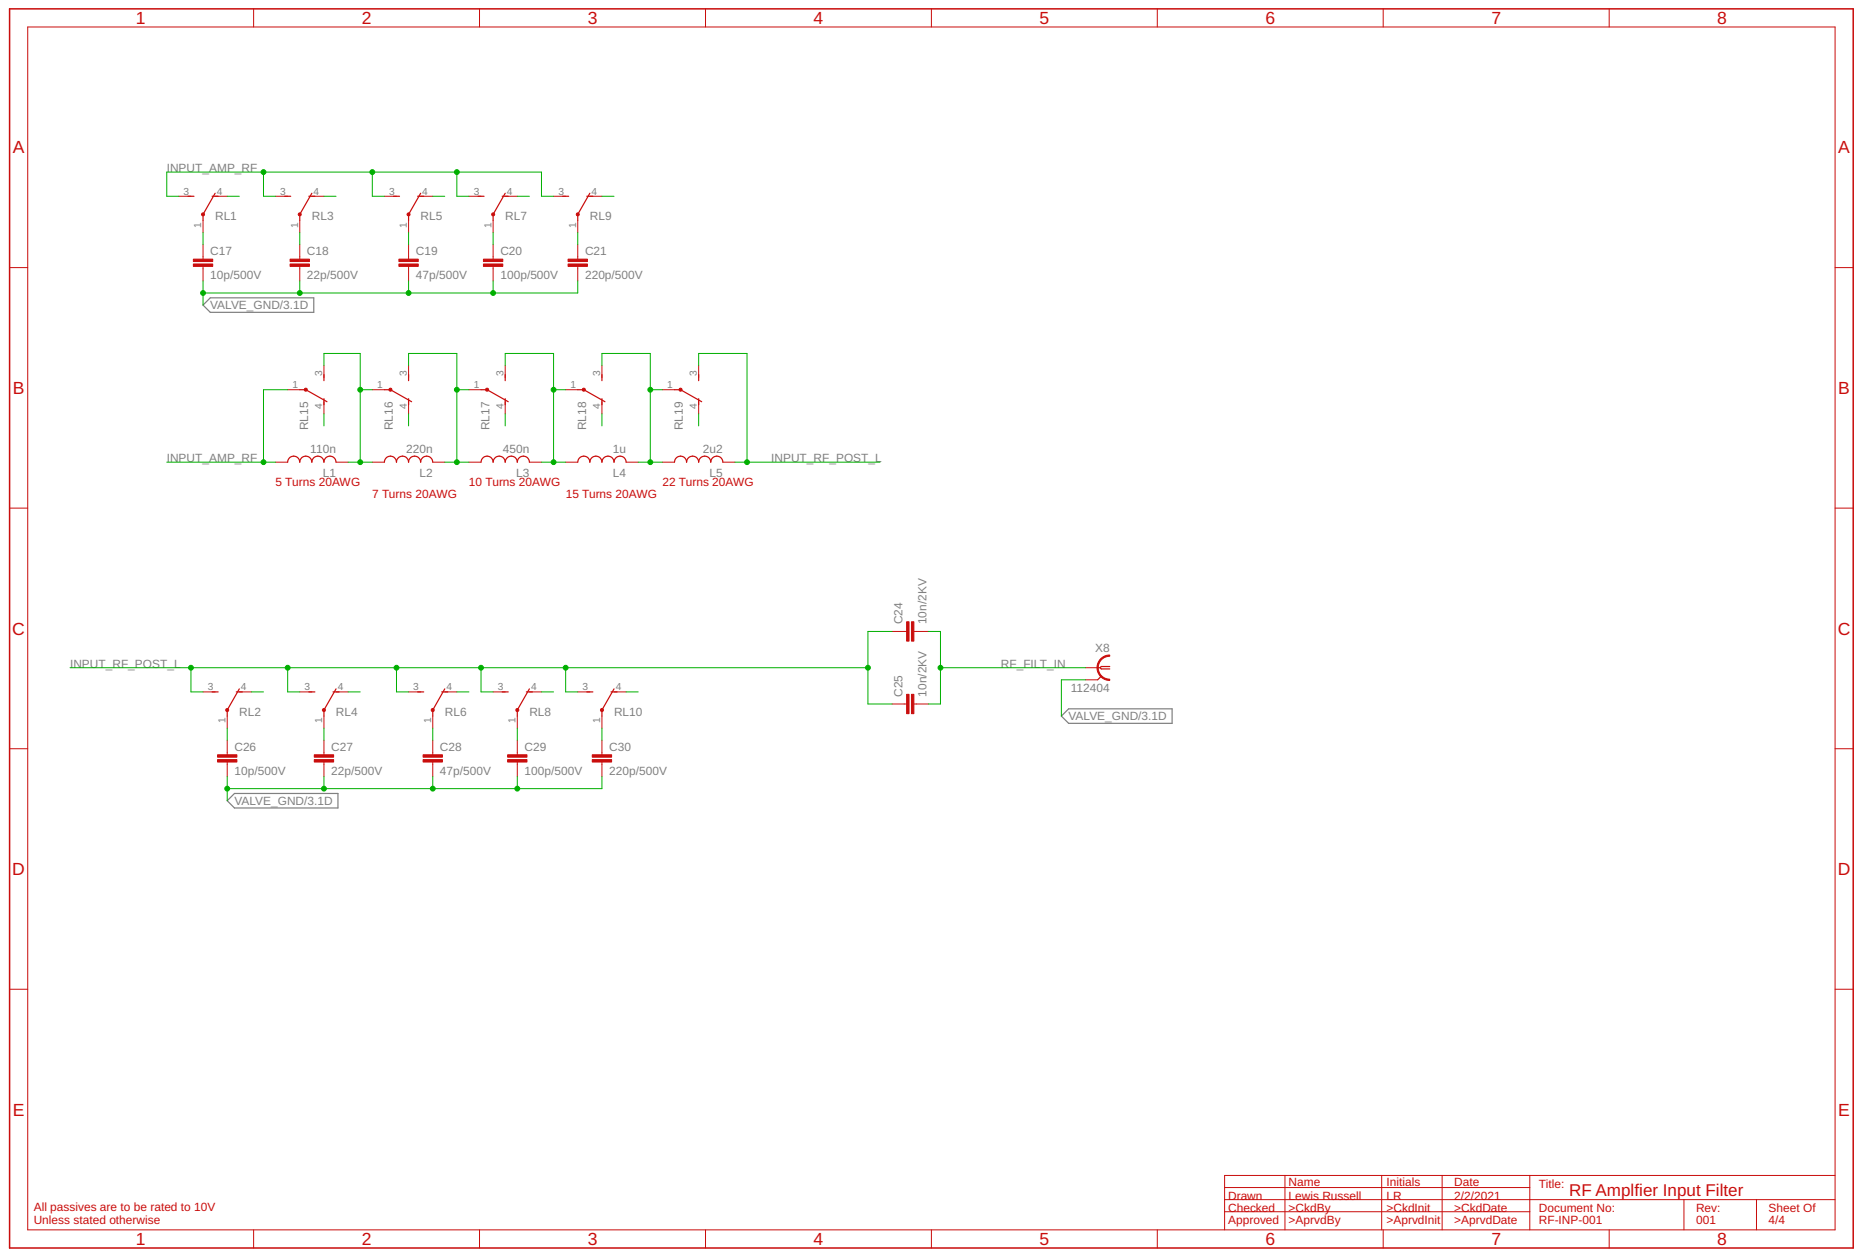
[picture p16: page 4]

Drawn Checked | Lewis Russell | LR | 2/2/2021

RF Amplfier Input Filter

All passives are to be rated to 10V

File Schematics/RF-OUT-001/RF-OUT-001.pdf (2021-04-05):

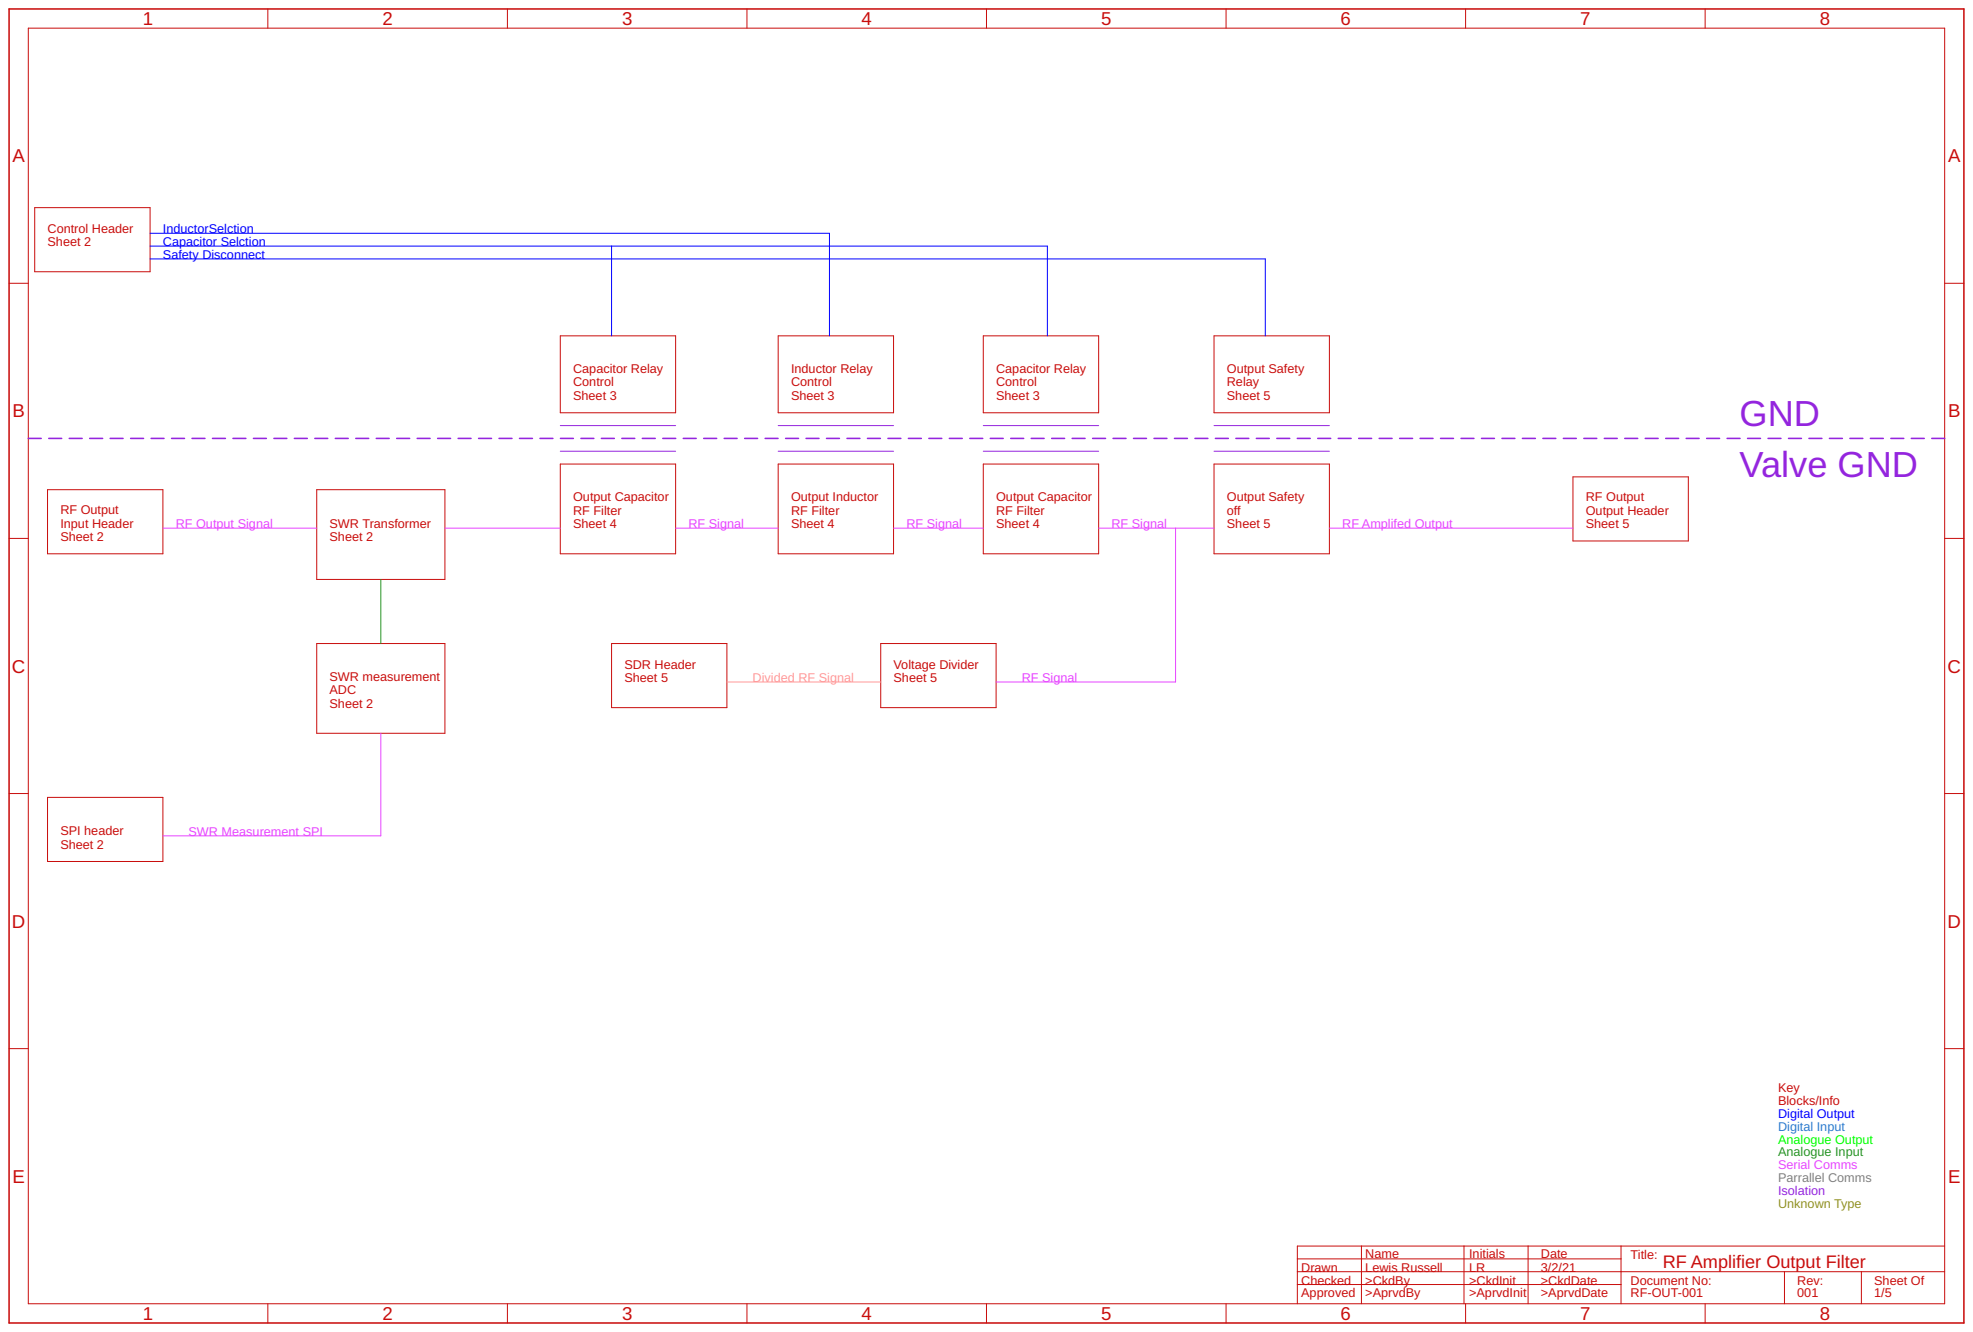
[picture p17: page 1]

Name | Initials | Date | Title: RF Amplifier Output Filter

Drawn | Lewis Russell | LR | 3/2/21
Checked | >CkdBy | >CkdInit | >CkdDate | Document No: RF-OUT-001 | Rev: | Sheet Of
Approved | >AprvdBy | >AprvdInit | >AprvdDate

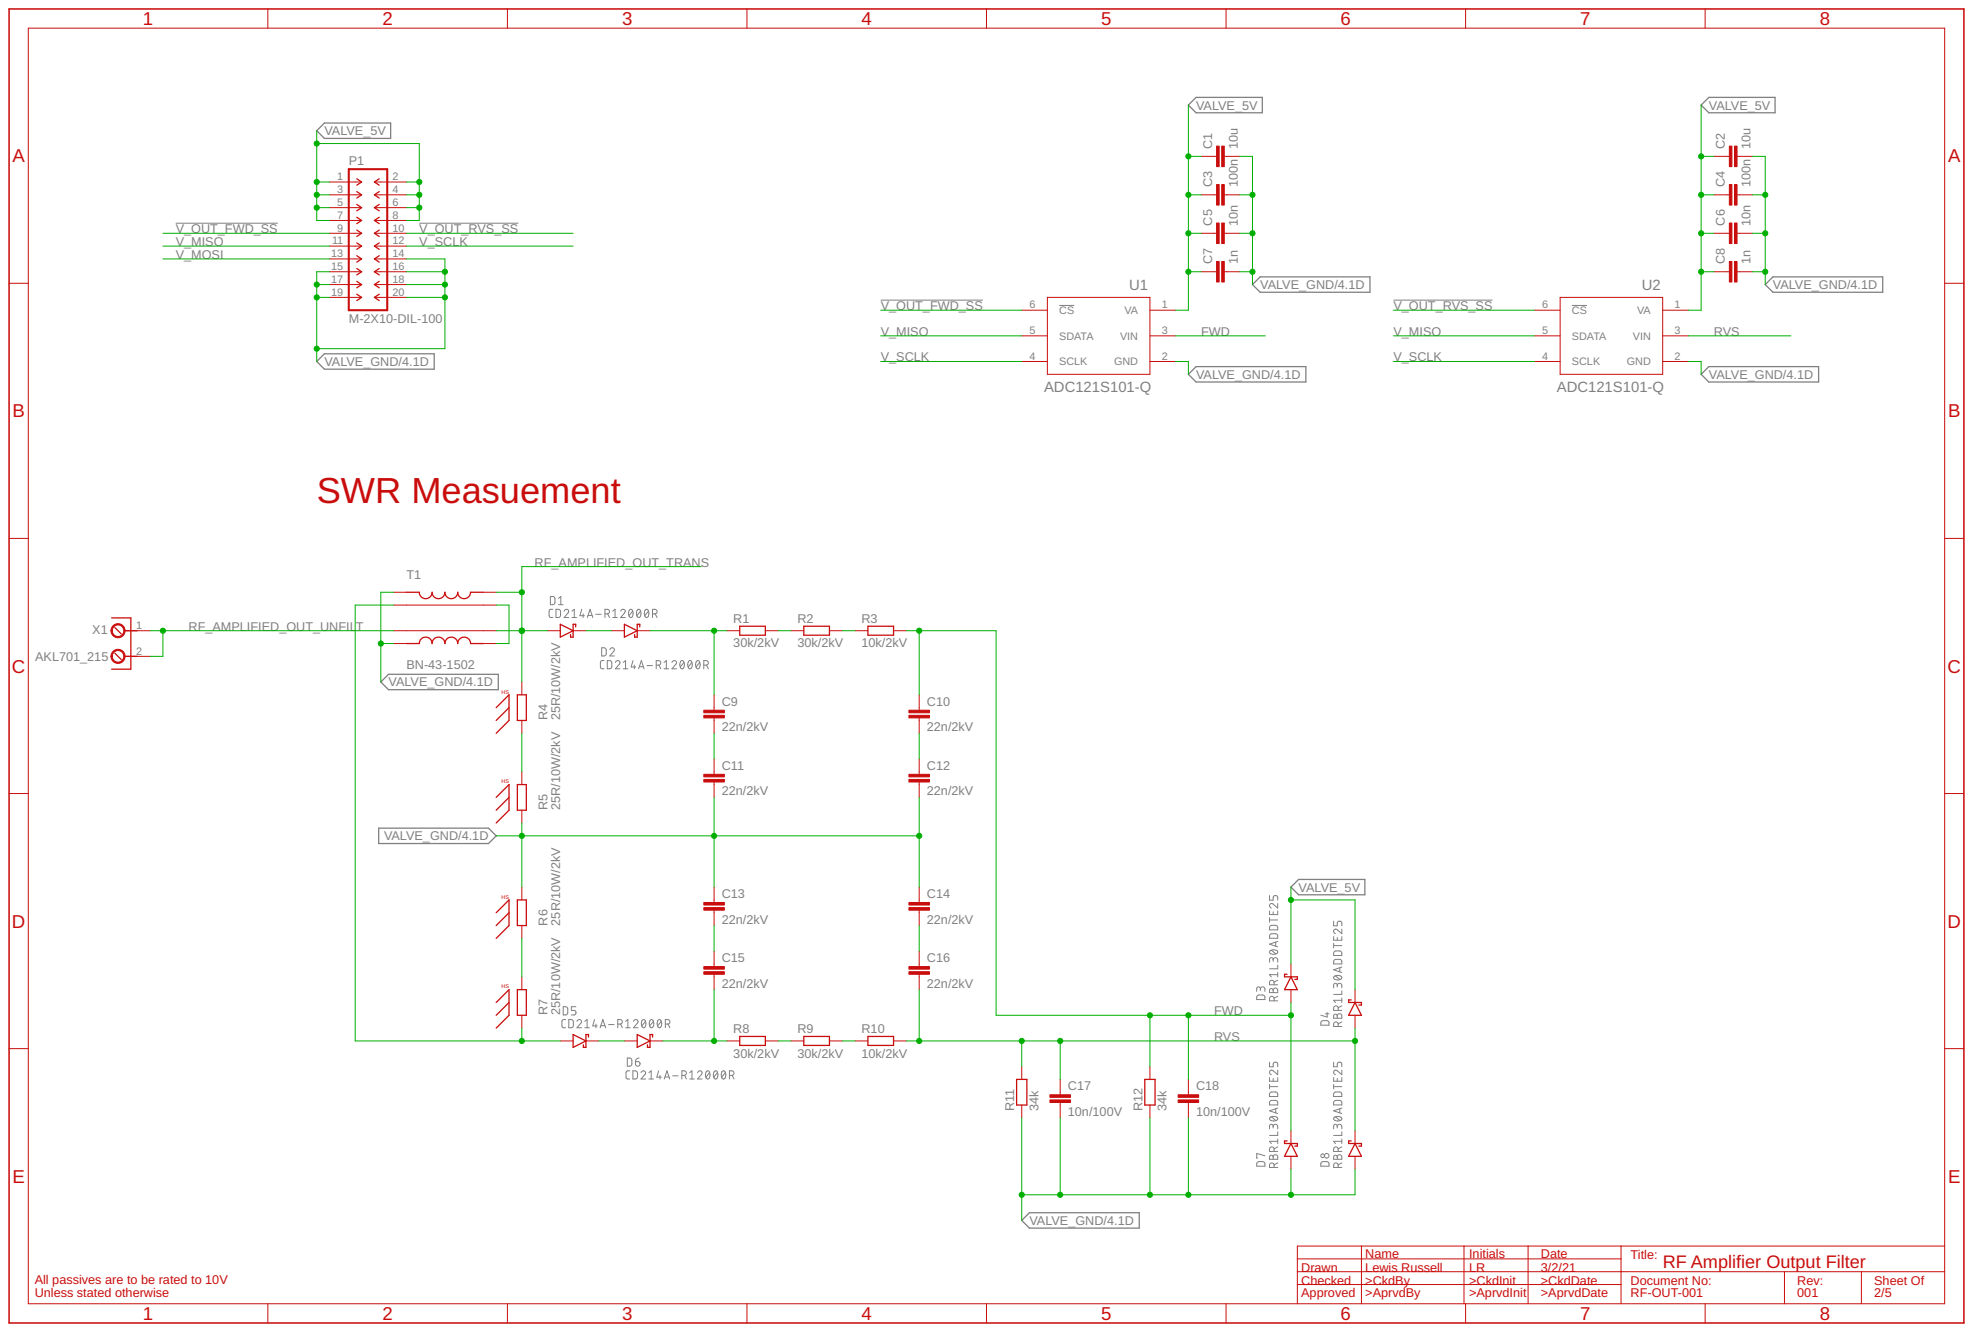
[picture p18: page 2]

All passives are to be rated to 10V
Unless stated otherwise

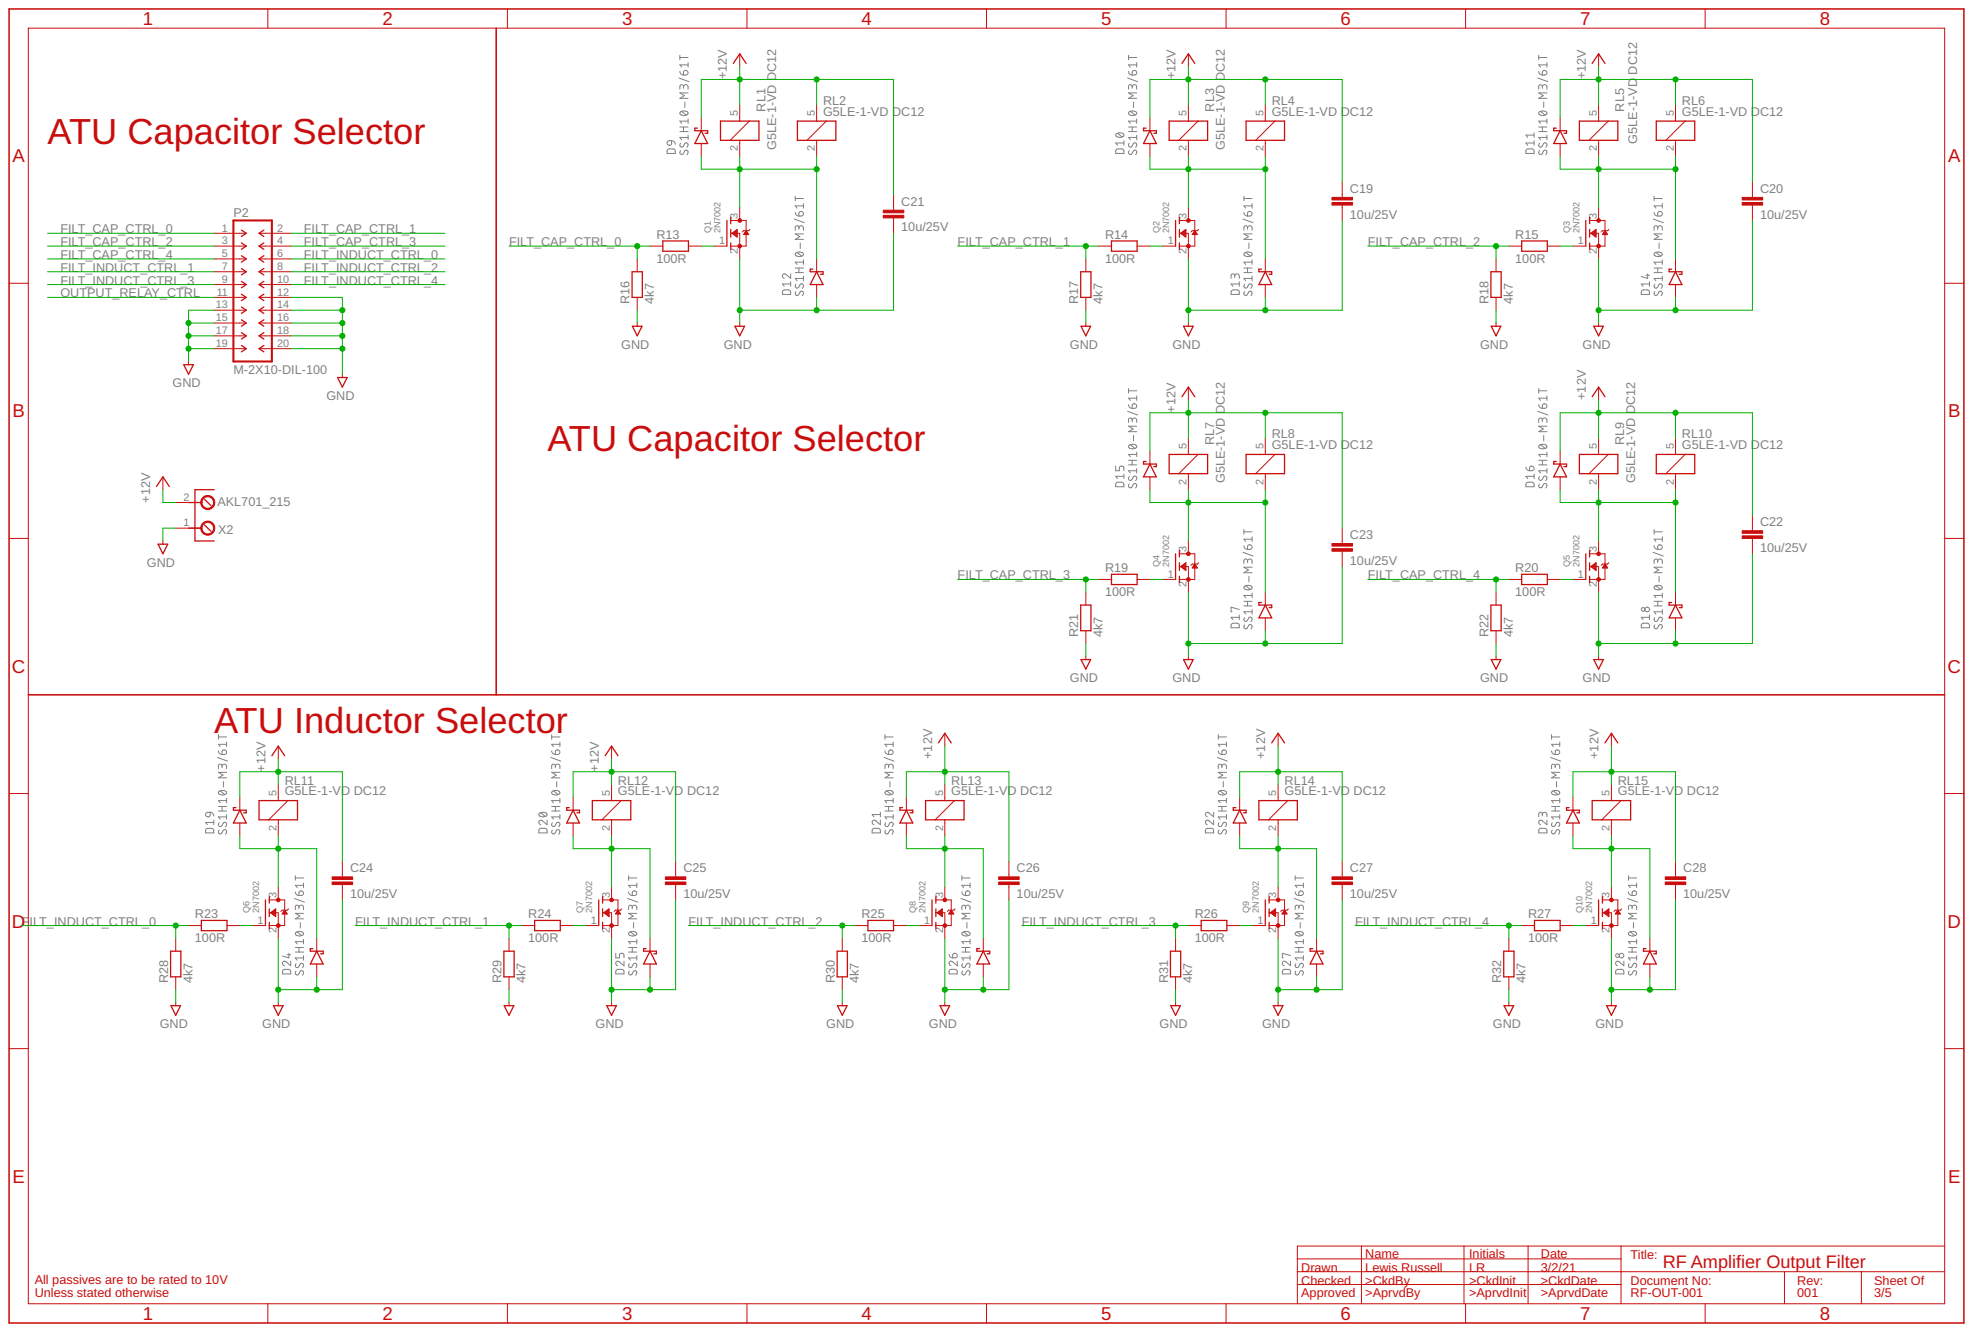
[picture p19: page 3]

15 | 16
17 | 18
19 | 20

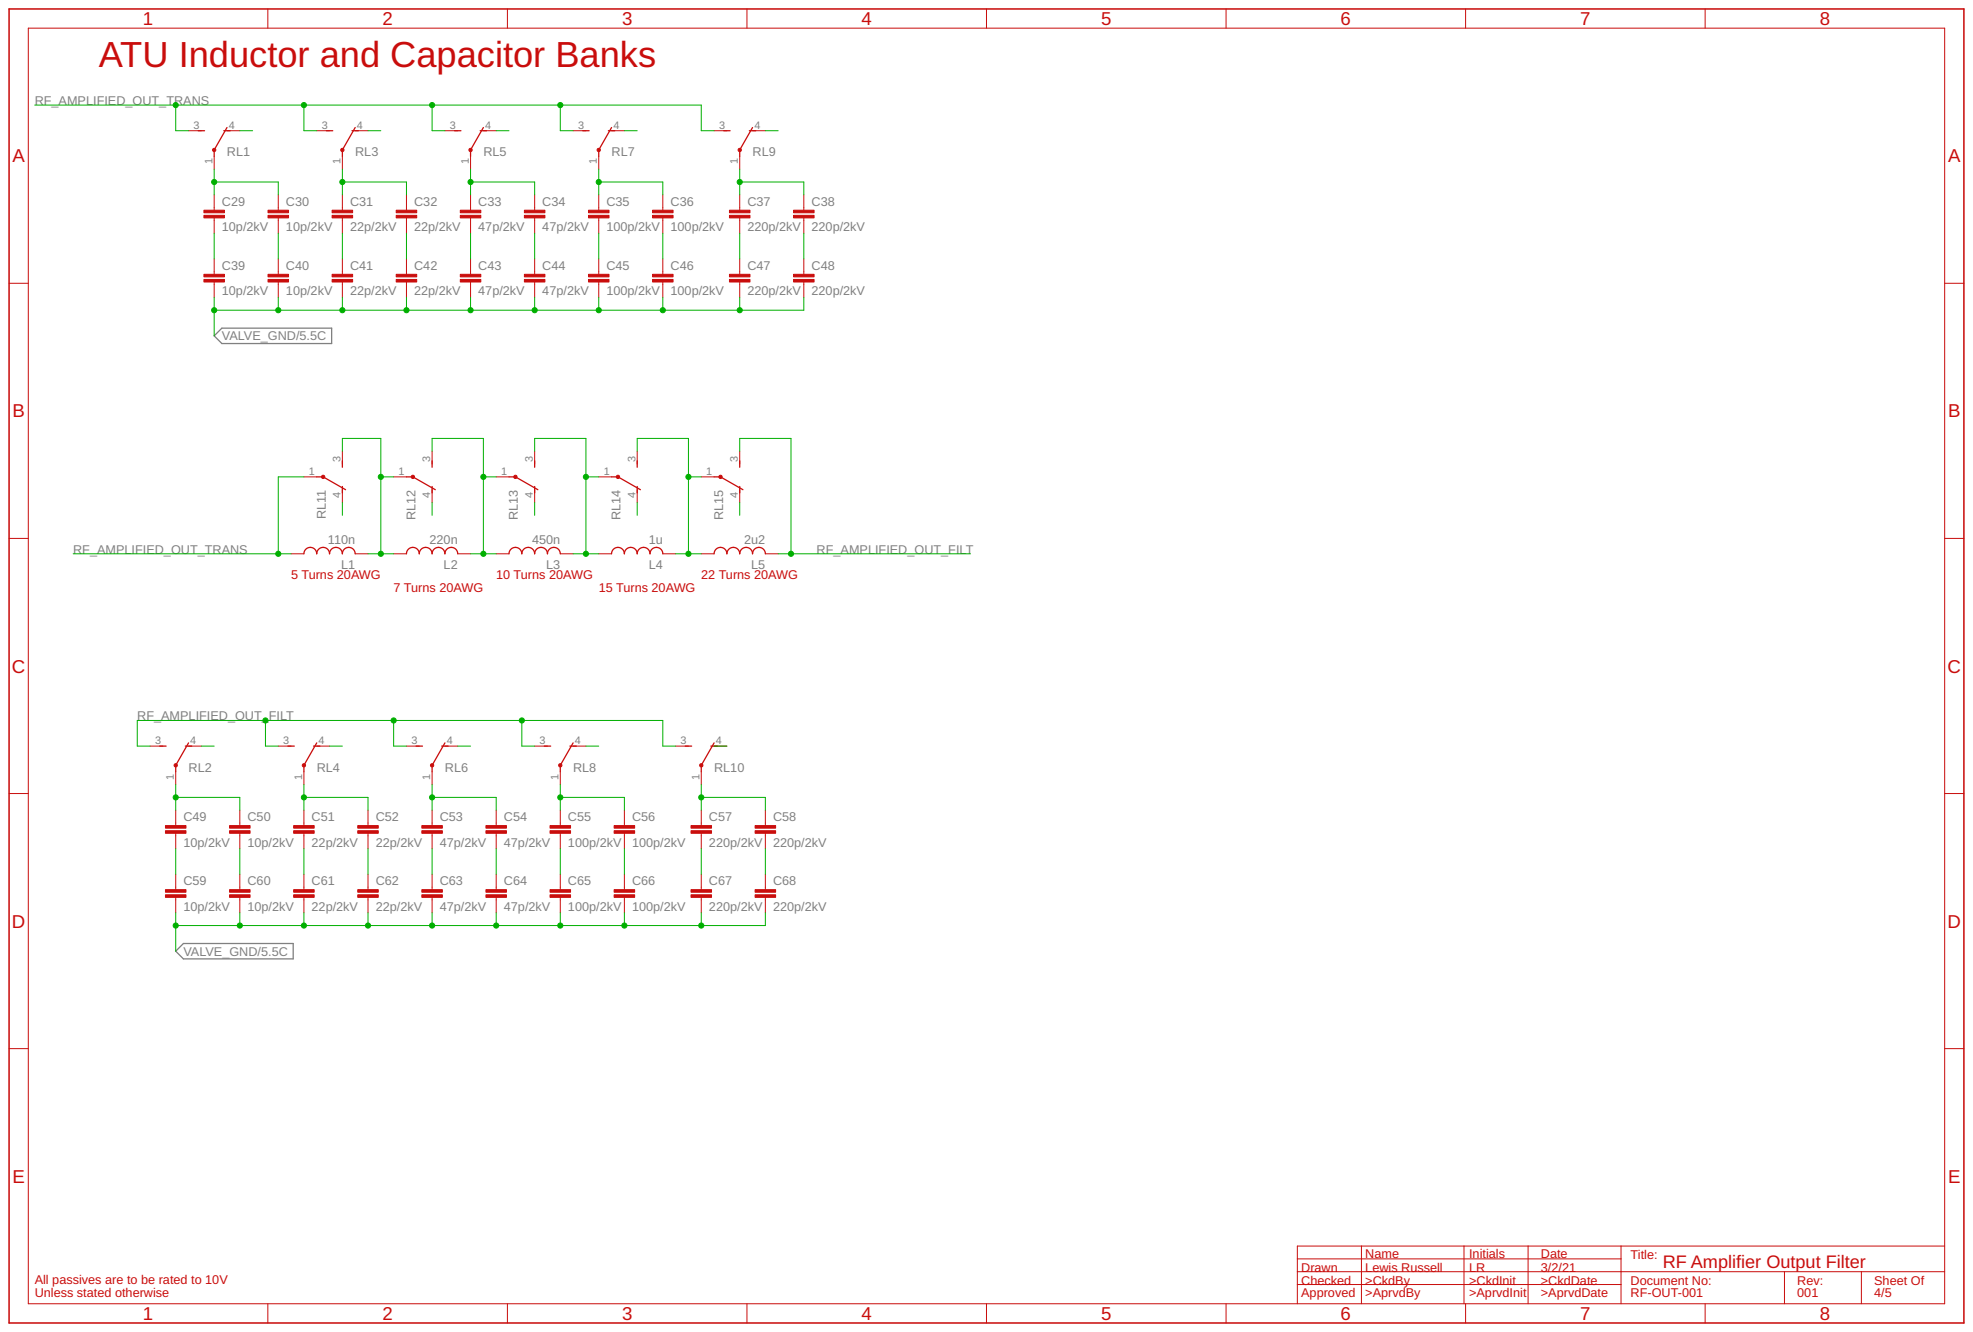
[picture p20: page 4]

ATU Inductor and Capacitor Banks

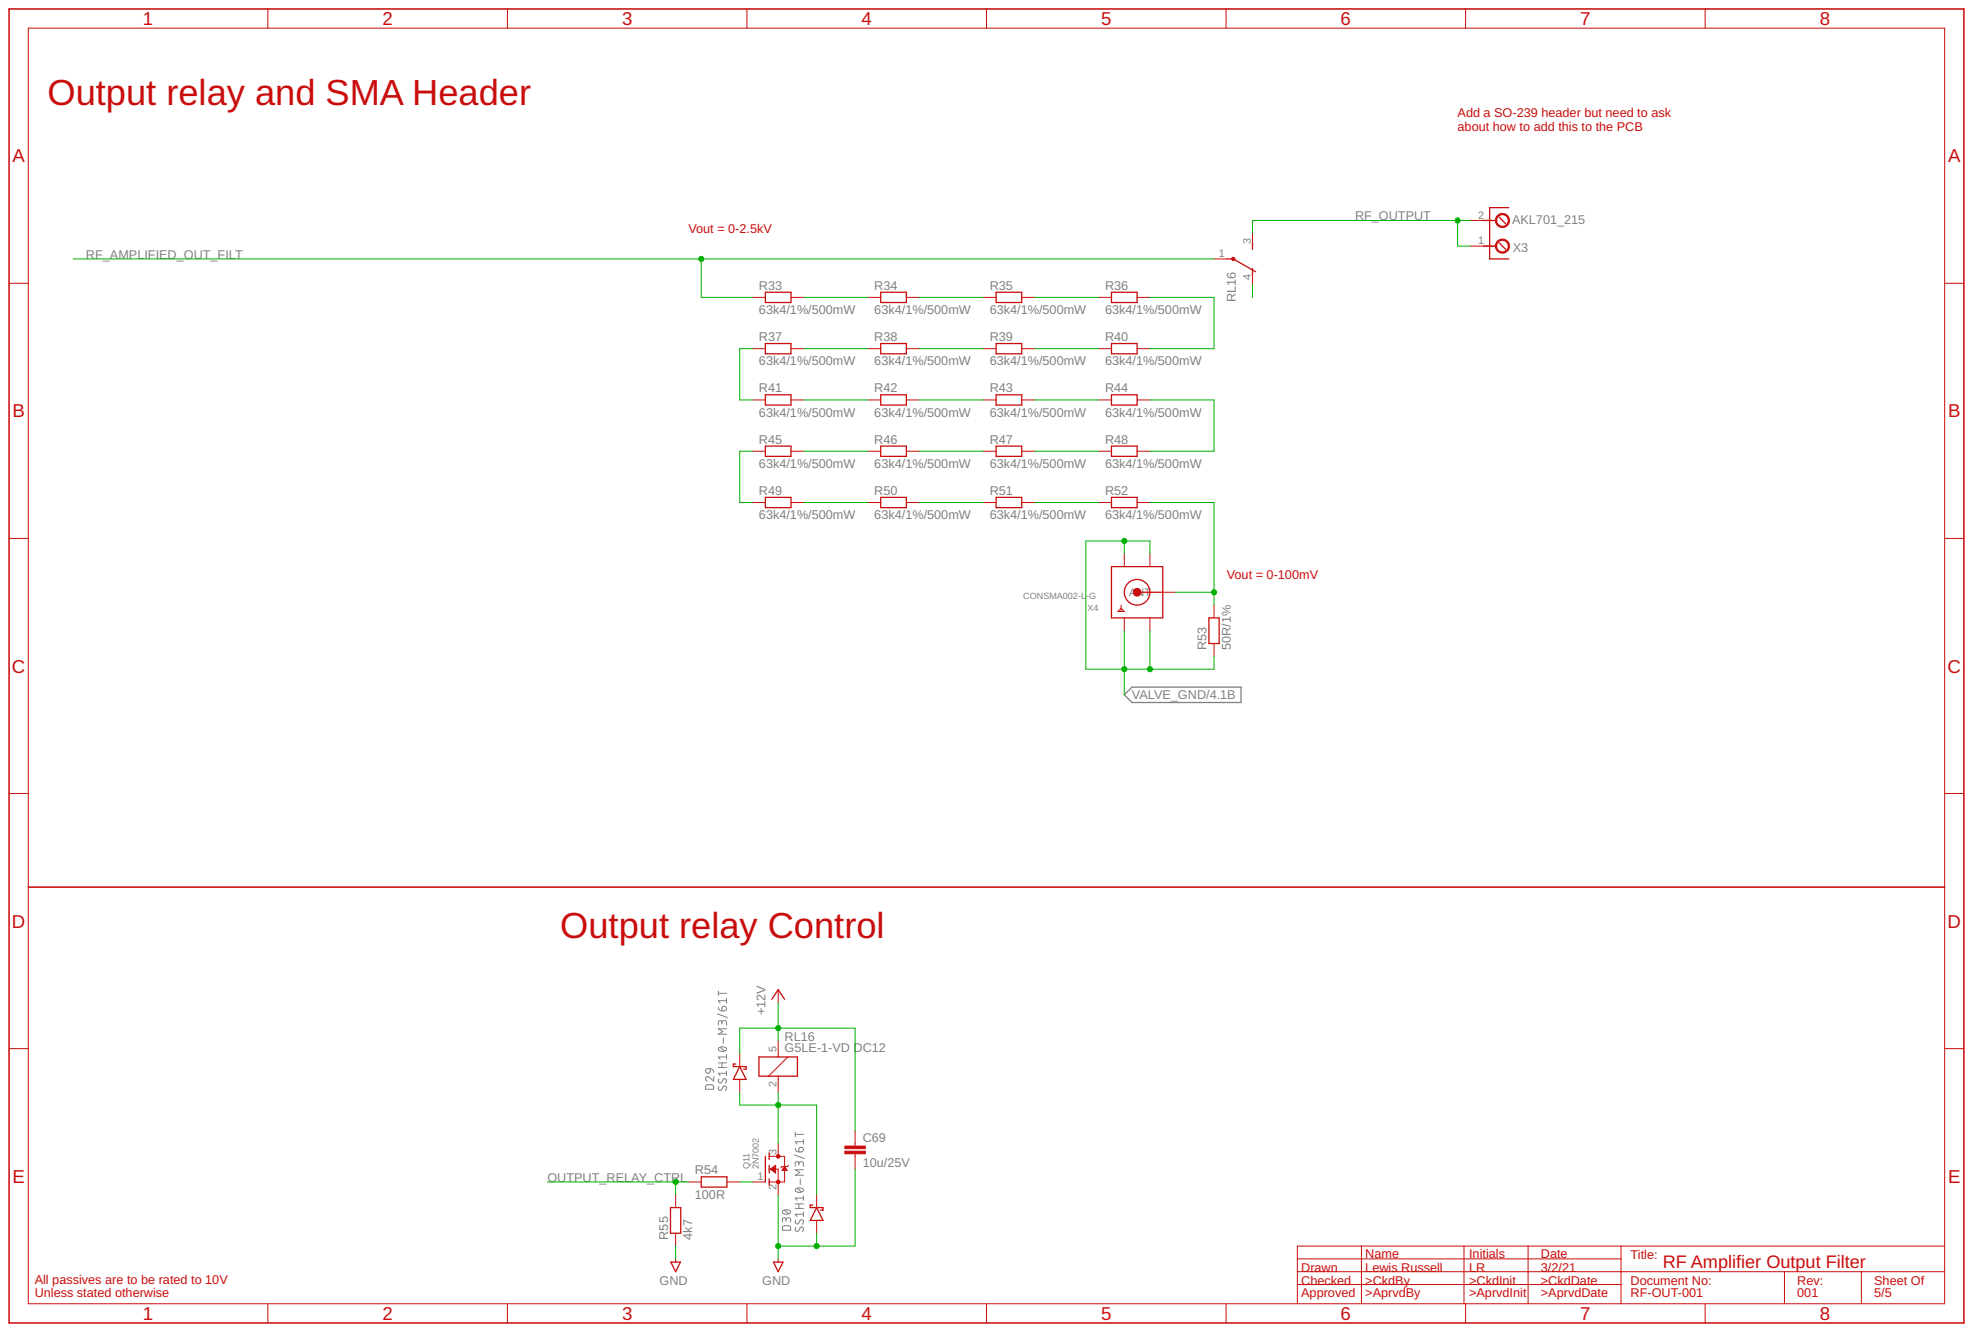
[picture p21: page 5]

Output relay and SMA Header

Add a SO-239 header but need to ask
about how to add this to the PCB

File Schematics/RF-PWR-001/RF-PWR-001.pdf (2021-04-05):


HV Header For Valves
To RF-VAL-001
Sheet 4

Name | Initials | Date | Title: RF Power Supply Board

Drawn | Lewis Russell | LR | 3/2/2021
Checked | >CkdBy | >CkdInit | >CkdDate | Document No: RF-PWR-001 | Rev: | Sheet Of
Approved | >AprvdBy | >AprvdInit | >AprvdDate


All passives are to be rated to 10V
Unless stated otherwise


Mains Input Filter and Choke

Pi and Rasp Power

All passives are to be rated to 10V
Unless stated otherwise


All passives are to be rated to 10V
Unless stated otherwise
Plate Current Sensor

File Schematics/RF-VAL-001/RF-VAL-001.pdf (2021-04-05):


mplified RF and Annode power

Vacuum Tube Amplifer Sheet 2

RF Input Header Sheet 2

Heater power and RF

Drawn Checked | Lewis Russell | LR | 30/1/2021

RF Valve Amplifer Board

RF-VAL-001 | 001 | 1/2


Drawn Checked | Lewis Russell | LR | 30/1/2021

RF Valve Amplifer Board

All passives are to be rated to 10V
Unless stated otherwise

RF-VAL-001 | 001 | 2/2

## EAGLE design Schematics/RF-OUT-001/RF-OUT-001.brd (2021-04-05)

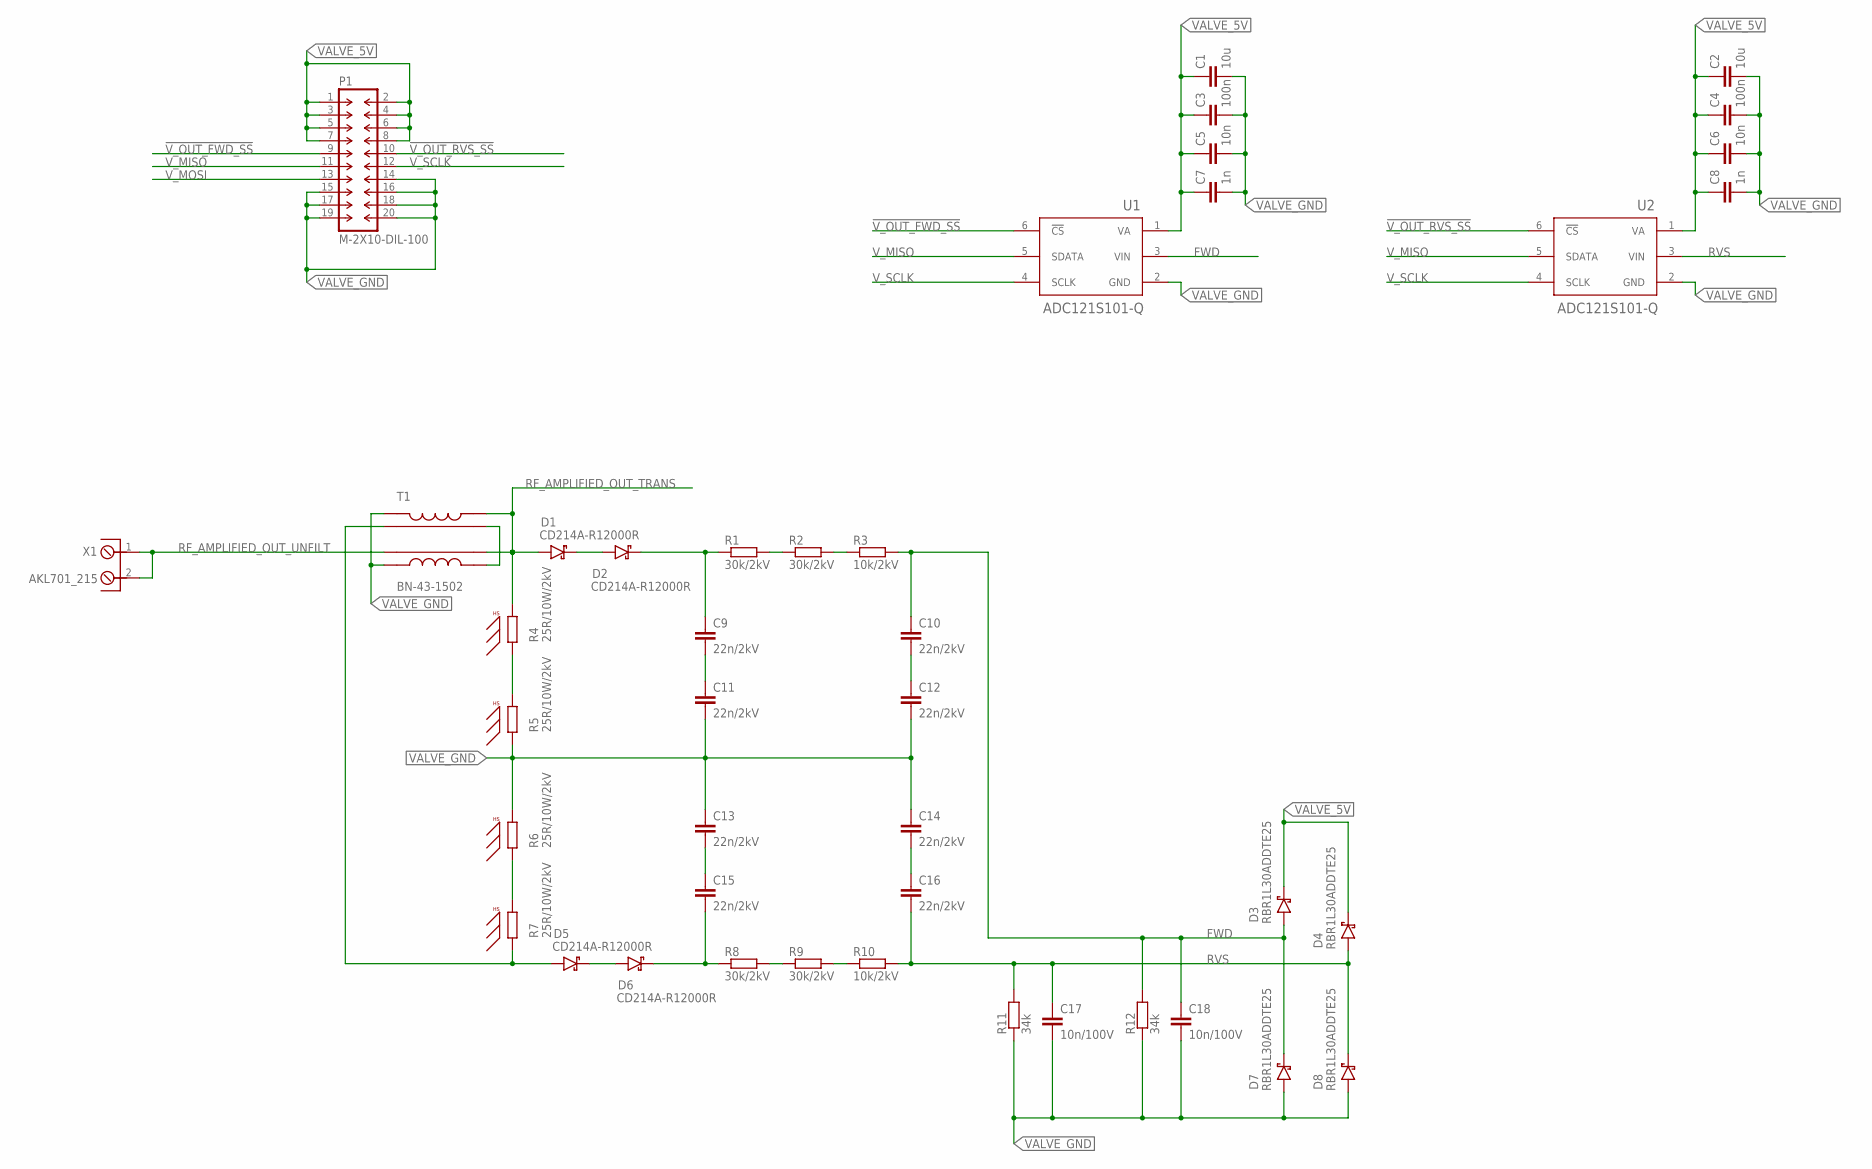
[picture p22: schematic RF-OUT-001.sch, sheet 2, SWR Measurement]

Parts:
C1, C2: 10u; C0805
C3, C4: 100n; C0603
C5, C6: 10n; C0603
C7, C8: 1n; C0603
C9, C10, C11, C12, C13, C14, C15, C16: 22n/2kV; C2220K
C17, C18: 10n/100V; C0603
D1, D2, D5, D6: CD214A-R12000R; SMB/DO-214AA
D3, D4, D7, D8: RBR1L30ADDTE25; SMA/DO-214AC
P1: M-2X10-DIL-100; DIL-100-2X10
R1, R2, R8, R9: 30k/2kV; 0309/10
R3, R10: 10k/2kV; 0309/10
R4, R5, R6, R7: 25R/10W/2kV; TO220ACS_WITH_WV-T220-101E
R11, R12: 34k; R0603
T1: BN-43-1502
U1, U2: ADC121S101-Q; SOT23-6
X1: AKL701_215; AKL701_2_15

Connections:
!V_OUT_FWD_SS: P1.9, U1.6 (!CS)
!V_OUT_RVS_SS: P1.10, U2.6 (!CS)
FWD: C10.1, C18.1, D3.A (ANODE), D7.C (CATHODE), R3.2, R12.2, U1.3 (VIN)
unnamed: T1.L2-2 (C2-2), T1.T1-2 (L1-2)
unnamed: R4.1, R5.2
unnamed: R6.1, R7.2
unnamed: C9.2, C11.1
unnamed: D1.C (CATHODE), D2.A (ANODE)
unnamed: C9.1, D2.C (CATHODE), R1.1
unnamed: R1.2, R2.1
unnamed: C10.2, C12.1
unnamed: R2.2, R3.1
unnamed: C13.2, C15.1
unnamed: D5.C (CATHODE), D6.A (ANODE)
unnamed: C15.2, D6.C (CATHODE), R8.1
unnamed: C14.2, C16.1
unnamed: R8.2, R9.1
unnamed: R9.2, R10.1
unnamed: D5.A (ANODE), R7.1, T1.T1-1 (L1-1)
RF_AMPLIFIED_OUT_TRANS: D1.A (ANODE), R4.2, T1.L1-2 (C1-2), T1.T2-2 (L2-2); also elsewhere on the board
RF_AMPLIFIED_OUT_UNFILT: T1.T2-1 (L2-1), X1.1, X1.2
RVS: C16.2, C17.1, D4.A (ANODE), D8.C (CATHODE), R10.2, R11.2, U2.3 (VIN)
VALVE_5V: C1.1, C2.1, C3.1, C4.1, C5.1, C6.1, C7.1, C8.1, D3.C (CATHODE), D4.C (CATHODE), P1.1, P1.2, P1.3, P1.4, P1.5, P1.6, P1.7, P1.8, U1.1 (VA), U2.1 (VA)
VALVE_GND: C1.2, C2.2, C3.2, C4.2, C5.2, C6.2, C7.2, C8.2, C11.2, C12.2, C13.1, C14.1, C17.2, C18.2, D7.A (ANODE), D8.A (ANODE), P1.14, P1.15, P1.16, P1.17, P1.18, P1.19, P1.20, R5.1, R6.2, R11.1, R12.1, T1.L1-1 (C1-1), T1.L2-1 (C2-1), U1.2 (GND), U2.2 (GND); also elsewhere on the board
V_MISO: P1.11, U1.5 (SDATA), U2.5 (SDATA)
V_MOSI: P1.13
V_SCLK: P1.12, U1.4 (SCLK), U2.4 (SCLK)

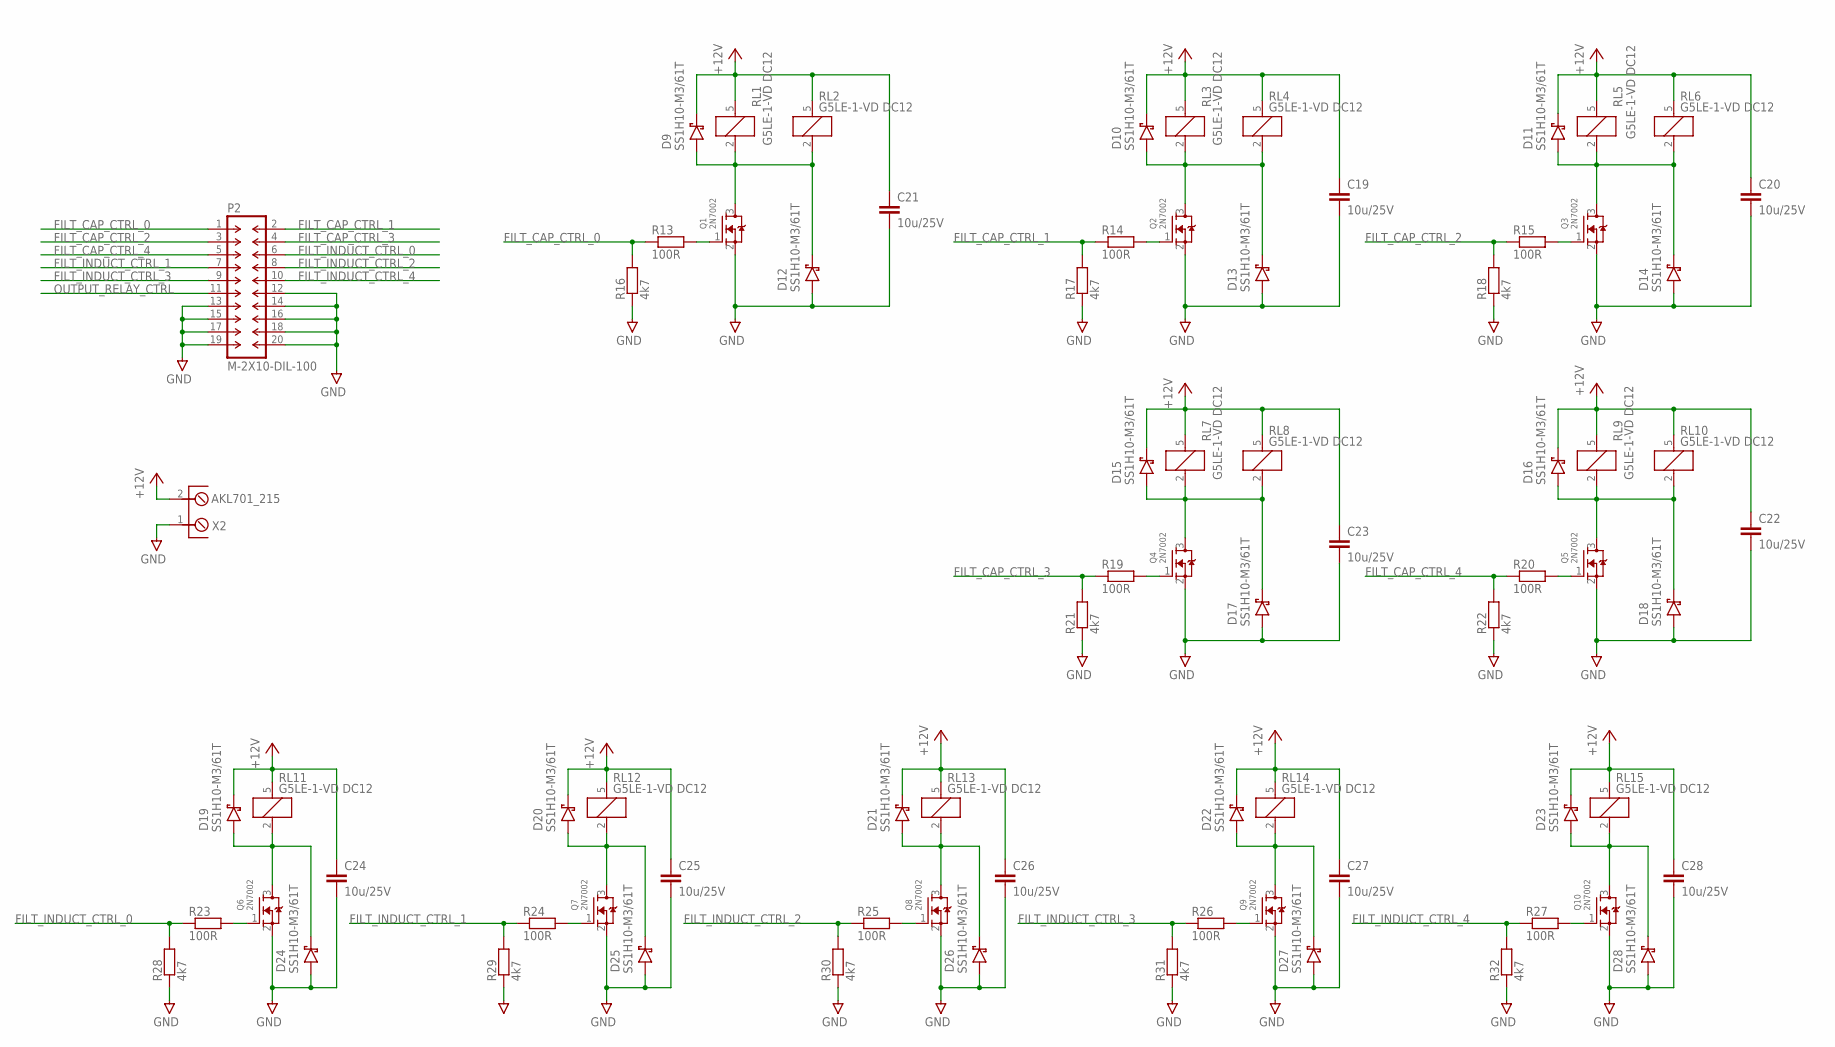
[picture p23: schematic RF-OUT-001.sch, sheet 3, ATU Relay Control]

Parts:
C19, C20, C21, C22, C23, C24, C25, C26, C27, C28: 10u/25V; C0805
D9, D10, D11, D12, D13, D14, D15, D16, D17, D18, D19, D20, D21, D22, D23, D24, D25, D26, D27, D28: SS1H10-M3/61T; SMA/DO-214AC
P2: M-2X10-DIL-100; DIL-100-2X10
Q1, Q2, Q3, Q4, Q5, Q6, Q7, Q8, Q9, Q10: 2N7002; SOT23
R13, R14, R15, R19, R20, R23, R24, R25, R26, R27: 100R; R0603
R16, R17, R18, R21, R22, R28, R29, R30, R31, R32: 4k7; R0603
RL1, RL2, RL3, RL4, RL5, RL6, RL7, RL8, RL9, RL10, RL11, RL12, RL13, RL14, RL15: G5LE-1-VD DC12; SPDT
X2: AKL701_215; AKL701_2_15

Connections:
+12V: C19.1, C20.1, C21.1, C22.1, C23.1, C24.1, C25.1, C26.1, C27.1, C28.1, D9.C (CATHODE), D10.C (CATHODE), D11.C (CATHODE), D15.C (CATHODE), D16.C (CATHODE), D19.C (CATHODE), D20.C (CATHODE), D21.C (CATHODE), D22.C (CATHODE), D23.C (CATHODE), RL1.5, RL2.5, RL3.5, RL4.5, RL5.5, RL6.5, RL7.5, RL8.5, RL9.5, RL10.5, RL11.5, RL12.5, RL13.5, RL14.5, RL15.5, X2.2; also elsewhere on the board
FILT_CAP_CTRL_0: P2.1, R13.1, R16.2
FILT_CAP_CTRL_1: P2.2, R14.1, R17.2
FILT_CAP_CTRL_2: P2.3, R15.1, R18.2
FILT_CAP_CTRL_3: P2.4, R19.1, R21.2
FILT_CAP_CTRL_4: P2.5, R20.1, R22.2
FILT_INDUCT_CTRL_0: P2.6, R23.1, R28.2
FILT_INDUCT_CTRL_1: P2.7, R24.1, R29.2
FILT_INDUCT_CTRL_2: P2.8, R25.1, R30.2
FILT_INDUCT_CTRL_3: P2.9, R26.1, R31.2
FILT_INDUCT_CTRL_4: P2.10, R27.1, R32.2
GND: C19.2, C20.2, C21.2, C22.2, C23.2, C24.2, C25.2, C26.2, C27.2, C28.2, D12.A (ANODE), D13.A (ANODE), D14.A (ANODE), D17.A (ANODE), D18.A (ANODE), D24.A (ANODE), D25.A (ANODE), D26.A (ANODE), D27.A (ANODE), D28.A (ANODE), P2.12, P2.13, P2.14, P2.15, P2.16, P2.17, P2.18, P2.19, P2.20, Q1.2 (S), Q2.2 (S), Q3.2 (S), Q4.2 (S), Q5.2 (S), Q6.2 (S), Q7.2 (S), Q8.2 (S), Q9.2 (S), Q10.2 (S), R16.1, R17.1, R18.1, R21.1, R22.1, R28.1, R29.1, R30.1, R31.1, R32.1, X2.1; also elsewhere on the board
unnamed: D9.A (ANODE), D12.C (CATHODE), Q1.3 (D), RL1.2, RL2.2
unnamed: Q1.1 (G), R13.2
unnamed: D10.A (ANODE), D13.C (CATHODE), Q2.3 (D), RL3.2, RL4.2
unnamed: Q2.1 (G), R14.2
unnamed: D11.A (ANODE), D14.C (CATHODE), Q3.3 (D), RL5.2, RL6.2
unnamed: Q3.1 (G), R15.2
unnamed: D15.A (ANODE), D17.C (CATHODE), Q4.3 (D), RL7.2, RL8.2
unnamed: Q4.1 (G), R19.2
unnamed: D16.A (ANODE), D18.C (CATHODE), Q5.3 (D), RL9.2, RL10.2
unnamed: Q5.1 (G), R20.2
unnamed: D19.A (ANODE), D24.C (CATHODE), Q6.3 (D), RL11.2
unnamed: Q6.1 (G), R23.2
unnamed: D20.A (ANODE), D25.C (CATHODE), Q7.3 (D), RL12.2
unnamed: Q7.1 (G), R24.2
unnamed: D21.A (ANODE), D26.C (CATHODE), Q8.3 (D), RL13.2
unnamed: Q8.1 (G), R25.2
unnamed: D22.A (ANODE), D27.C (CATHODE), Q9.3 (D), RL14.2
unnamed: Q9.1 (G), R26.2
unnamed: D23.A (ANODE), D28.C (CATHODE), Q10.3 (D), RL15.2
unnamed: Q10.1 (G), R27.2
OUTPUT_RELAY_CTRL: P2.11; also elsewhere on the board

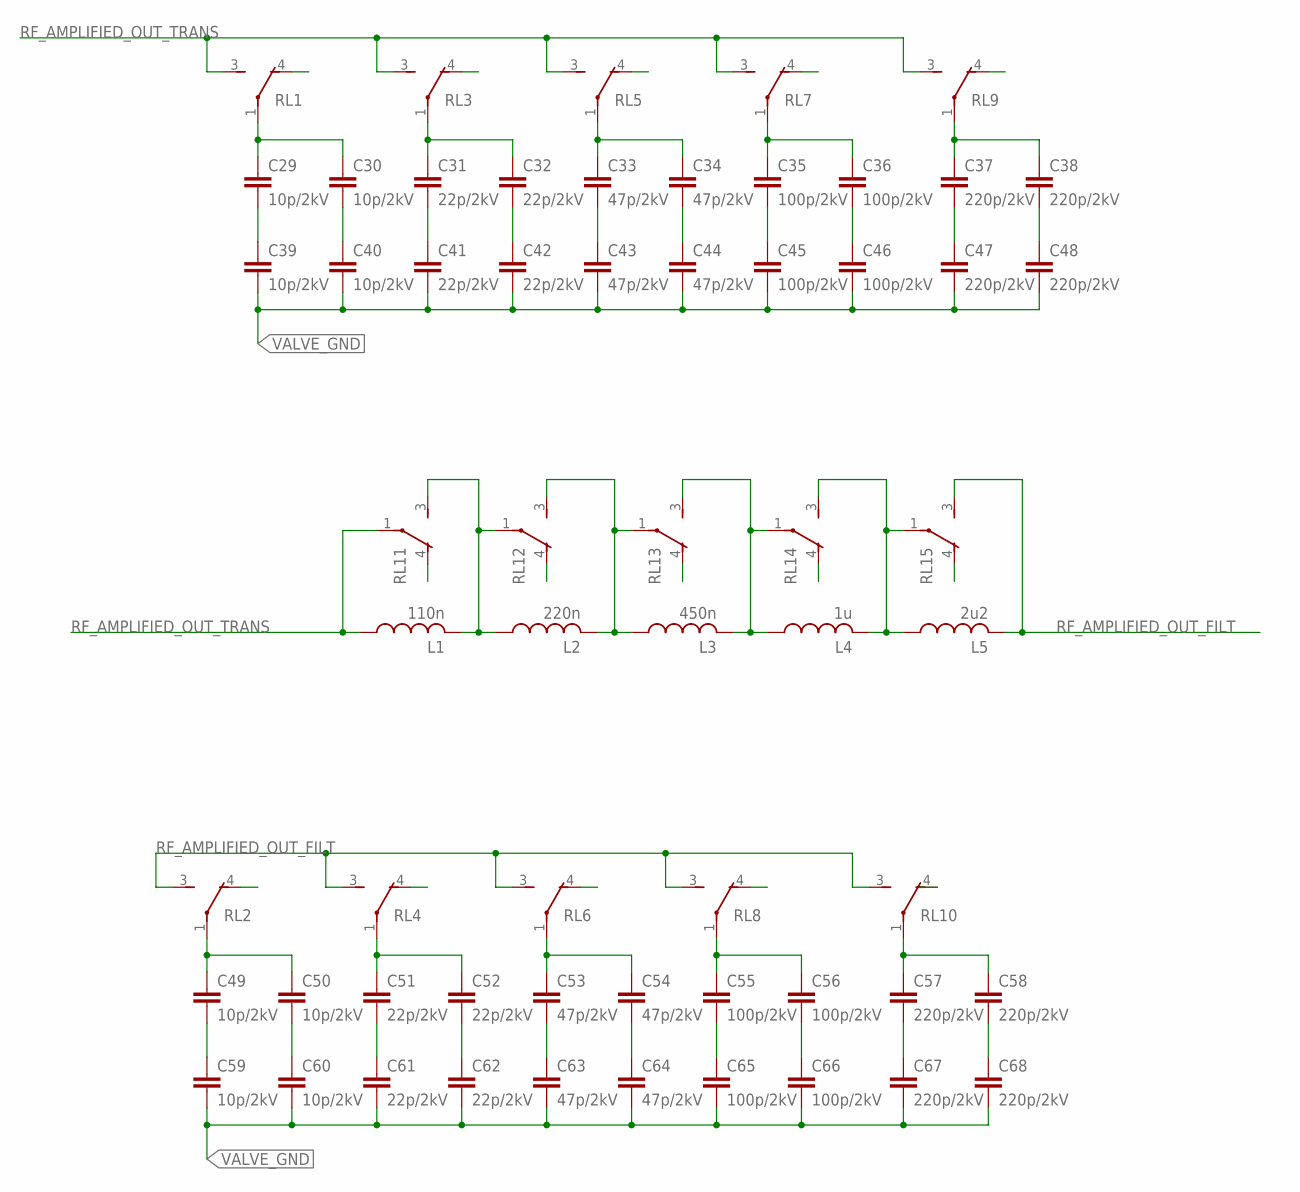
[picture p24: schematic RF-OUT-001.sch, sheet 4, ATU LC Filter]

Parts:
C29, C30, C39, C40, C49, C50, C59, C60: 10p/2kV; C050-055X075
C31, C32, C41, C42, C51, C52, C61, C62: 22p/2kV; C050-055X075
C33, C34, C43, C44, C53, C54, C63, C64: 47p/2kV; C050-055X075
C35, C36, C45, C46, C55, C56, C65, C66: 100p/2kV; C050-075X075
C37, C38, C47, C48, C57, C58, C67, C68: 220p/2kV; C050-075X075
L1: 110n; T80-6
L2: 220n; T80-6
L3: 450n; T80-6
L4: 1u; T80-6
L5: 2u2; T80-6
RL1, RL2, RL3, RL4, RL5, RL6, RL7, RL8, RL9, RL10, RL11, RL12, RL13, RL14, RL15: G5LE-1-VD DC12; SPDT

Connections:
unnamed: C29.1, C30.1, RL1.1
unnamed: C37.1, C38.1, RL9.1
unnamed: C49.1, C50.1, RL2.1
unnamed: C51.1, C52.1, RL4.1
unnamed: C53.1, C54.1, RL6.1
unnamed: C55.1, C56.1, RL8.1
unnamed: C29.2, C39.1
unnamed: C32.2, C42.1
unnamed: C30.2, C40.1
unnamed: C34.2, C44.1
unnamed: C36.2, C46.1
unnamed: C38.2, C48.1
unnamed: C31.2, C41.1
unnamed: C33.2, C43.1
unnamed: C35.2, C45.1
unnamed: C37.2, C47.1
unnamed: C57.1, C58.1, RL10.1
unnamed: C52.2, C62.1
unnamed: C50.2, C60.1
unnamed: C54.2, C64.1
unnamed: C56.2, C66.1
unnamed: C58.2, C68.1
unnamed: C49.2, C59.1
unnamed: C51.2, C61.1
unnamed: C53.2, C63.1
unnamed: C55.2, C65.1
unnamed: C57.2, C67.1
unnamed: C33.1, C34.1, RL5.1
unnamed: C35.1, C36.1, RL7.1
unnamed: C31.1, C32.1, RL3.1
unnamed: L4.2, L5.1, RL14.3, RL15.1
unnamed: L3.2, L4.1, RL13.3, RL14.1
unnamed: L2.2, L3.1, RL12.3, RL13.1
unnamed: L1.2, L2.1, RL11.3, RL12.1
RF_AMPLIFIED_OUT_FILT: L5.2, RL2.3, RL4.3, RL6.3, RL8.3, RL10.3, RL15.3; also elsewhere on the board
RF_AMPLIFIED_OUT_TRANS: L1.1, RL1.3, RL3.3, RL5.3, RL7.3, RL9.3, RL11.1; also elsewhere on the board
VALVE_GND: C39.2, C40.2, C41.2, C42.2, C43.2, C44.2, C45.2, C46.2, C47.2, C48.2, C59.2, C60.2, C61.2, C62.2, C63.2, C64.2, C65.2, C66.2, C67.2, C68.2; also elsewhere on the board

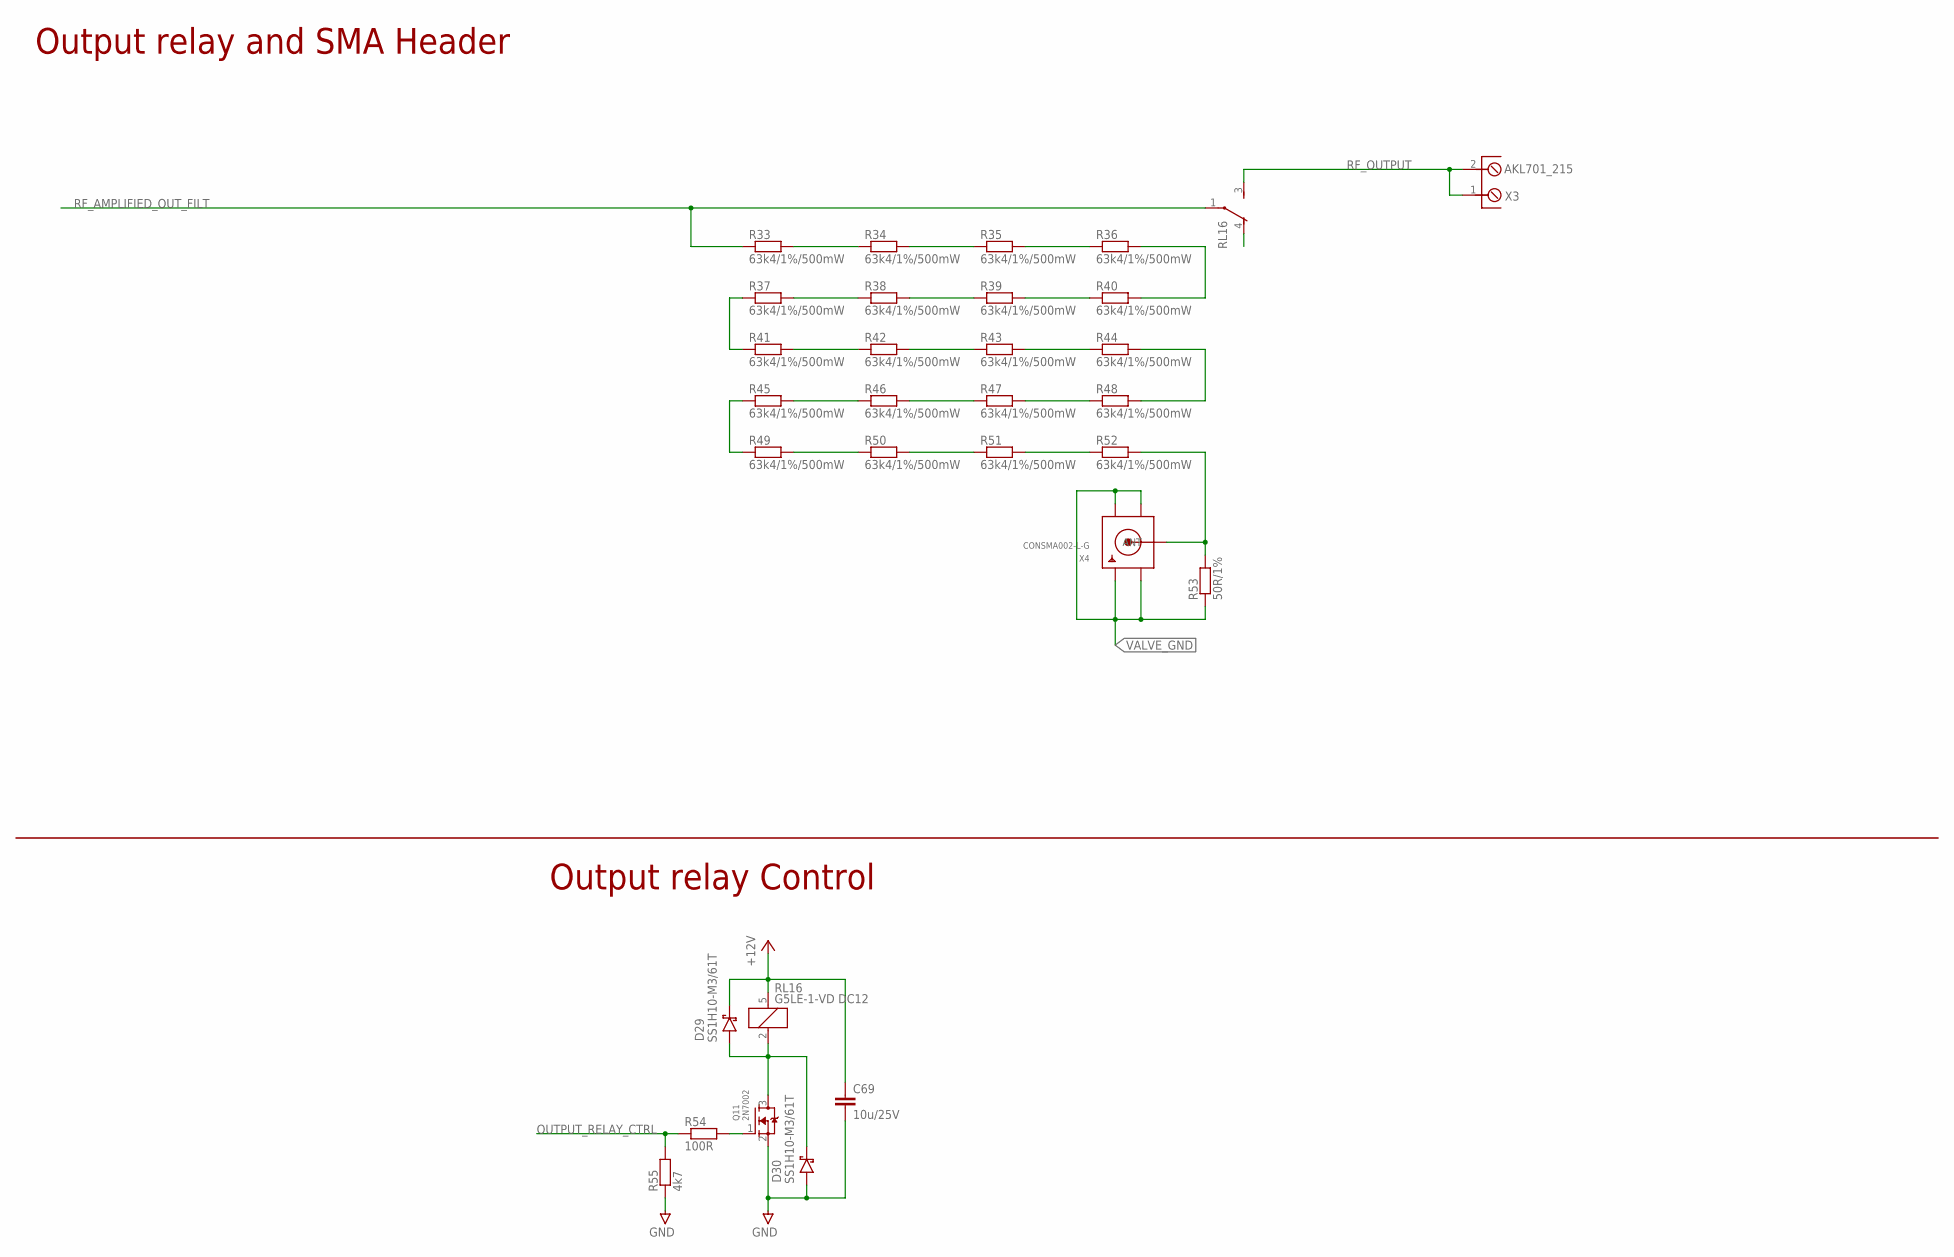
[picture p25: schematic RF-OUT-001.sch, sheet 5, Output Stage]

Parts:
C69: 10u/25V; C0805
D29, D30: SS1H10-M3/61T; SMA/DO-214AC
Q11: 2N7002; SOT23
R33, R34, R35, R36, R37, R38, R39, R40, R41, R42, R43, R44, R45, R46, R47, R48, R49, R50, R51, R52: 63k4/1%/500mW; R0805
R53: 50R/1%; R0603
R54: 100R; R0603
R55: 4k7; R0603
RL16: G5LE-1-VD DC12; SPDT
X3: AKL701_215; AKL701_2_15
X4: CONSMA002-L-G; SMA90_DIP

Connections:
+12V: C69.1, D29.C (CATHODE), RL16.5; also elsewhere on the board
GND: C69.2, D30.A (ANODE), Q11.2 (S), R55.1; also elsewhere on the board
unnamed: R52.2, R53.2, X4.ANTENNA (ANT)
unnamed: R33.2, R34.1
unnamed: R37.1, R41.1
unnamed: R37.2, R38.1
unnamed: R45.1, R49.1
unnamed: R41.2, R42.1
unnamed: R45.2, R46.1
unnamed: R49.2, R50.1
unnamed: R34.2, R35.1
unnamed: R38.2, R39.1
unnamed: R42.2, R43.1
unnamed: R46.2, R47.1
unnamed: R50.2, R51.1
unnamed: R35.2, R36.1
unnamed: R39.2, R40.1
unnamed: R43.2, R44.1
unnamed: R47.2, R48.1
unnamed: R51.2, R52.1
unnamed: R36.2, R40.2
unnamed: R44.2, R48.2
unnamed: D29.A (ANODE), D30.C (CATHODE), Q11.3 (D), RL16.2
unnamed: Q11.1 (G), R54.2
OUTPUT_RELAY_CTRL: R54.1, R55.2; also elsewhere on the board
RF_AMPLIFIED_OUT_FILT: R33.1, RL16.1; also elsewhere on the board
RF_OUTPUT: RL16.3, X3.1, X3.2
VALVE_GND: R53.1, X4.GND1, X4.GND2, X4.GND3, X4.GND4; also elsewhere on the board

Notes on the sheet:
Output relay Control
Output relay and SMA Header

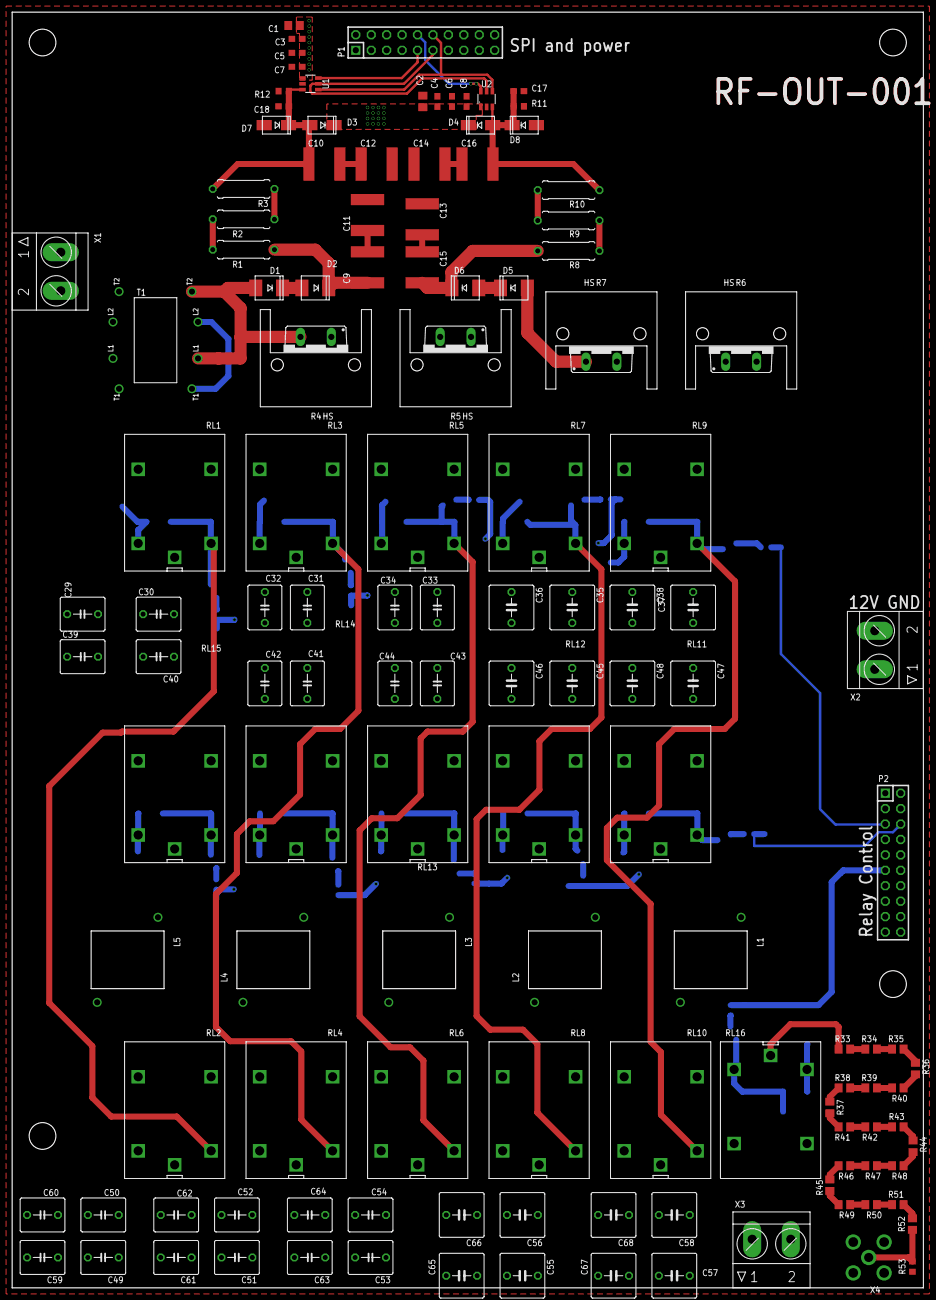
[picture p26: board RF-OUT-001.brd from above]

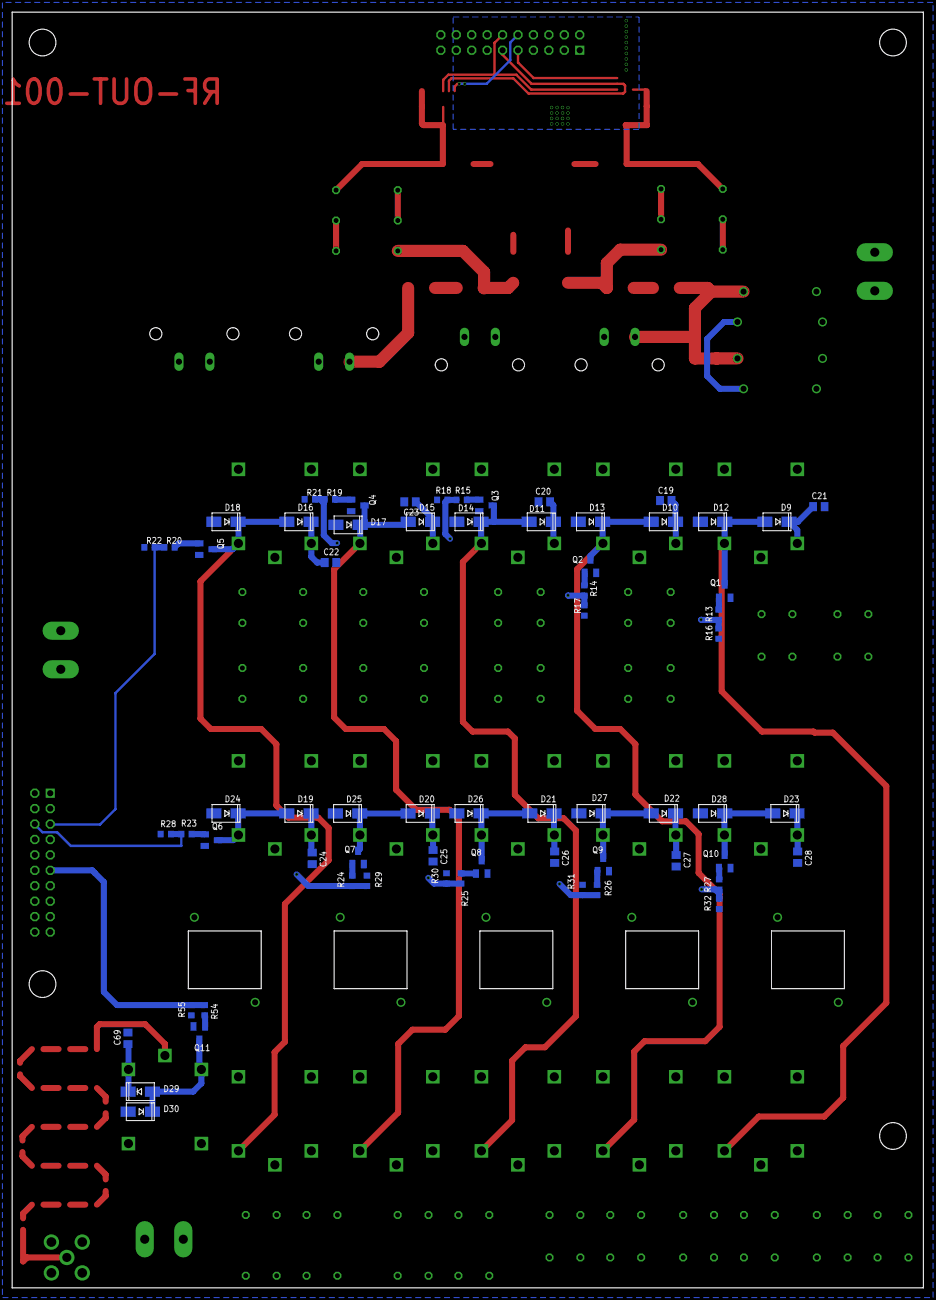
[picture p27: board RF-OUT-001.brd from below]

Board: 4 copper layers, 150.0 x 210.0 mm, 195 parts (66 on the bottom side), 117 nets.

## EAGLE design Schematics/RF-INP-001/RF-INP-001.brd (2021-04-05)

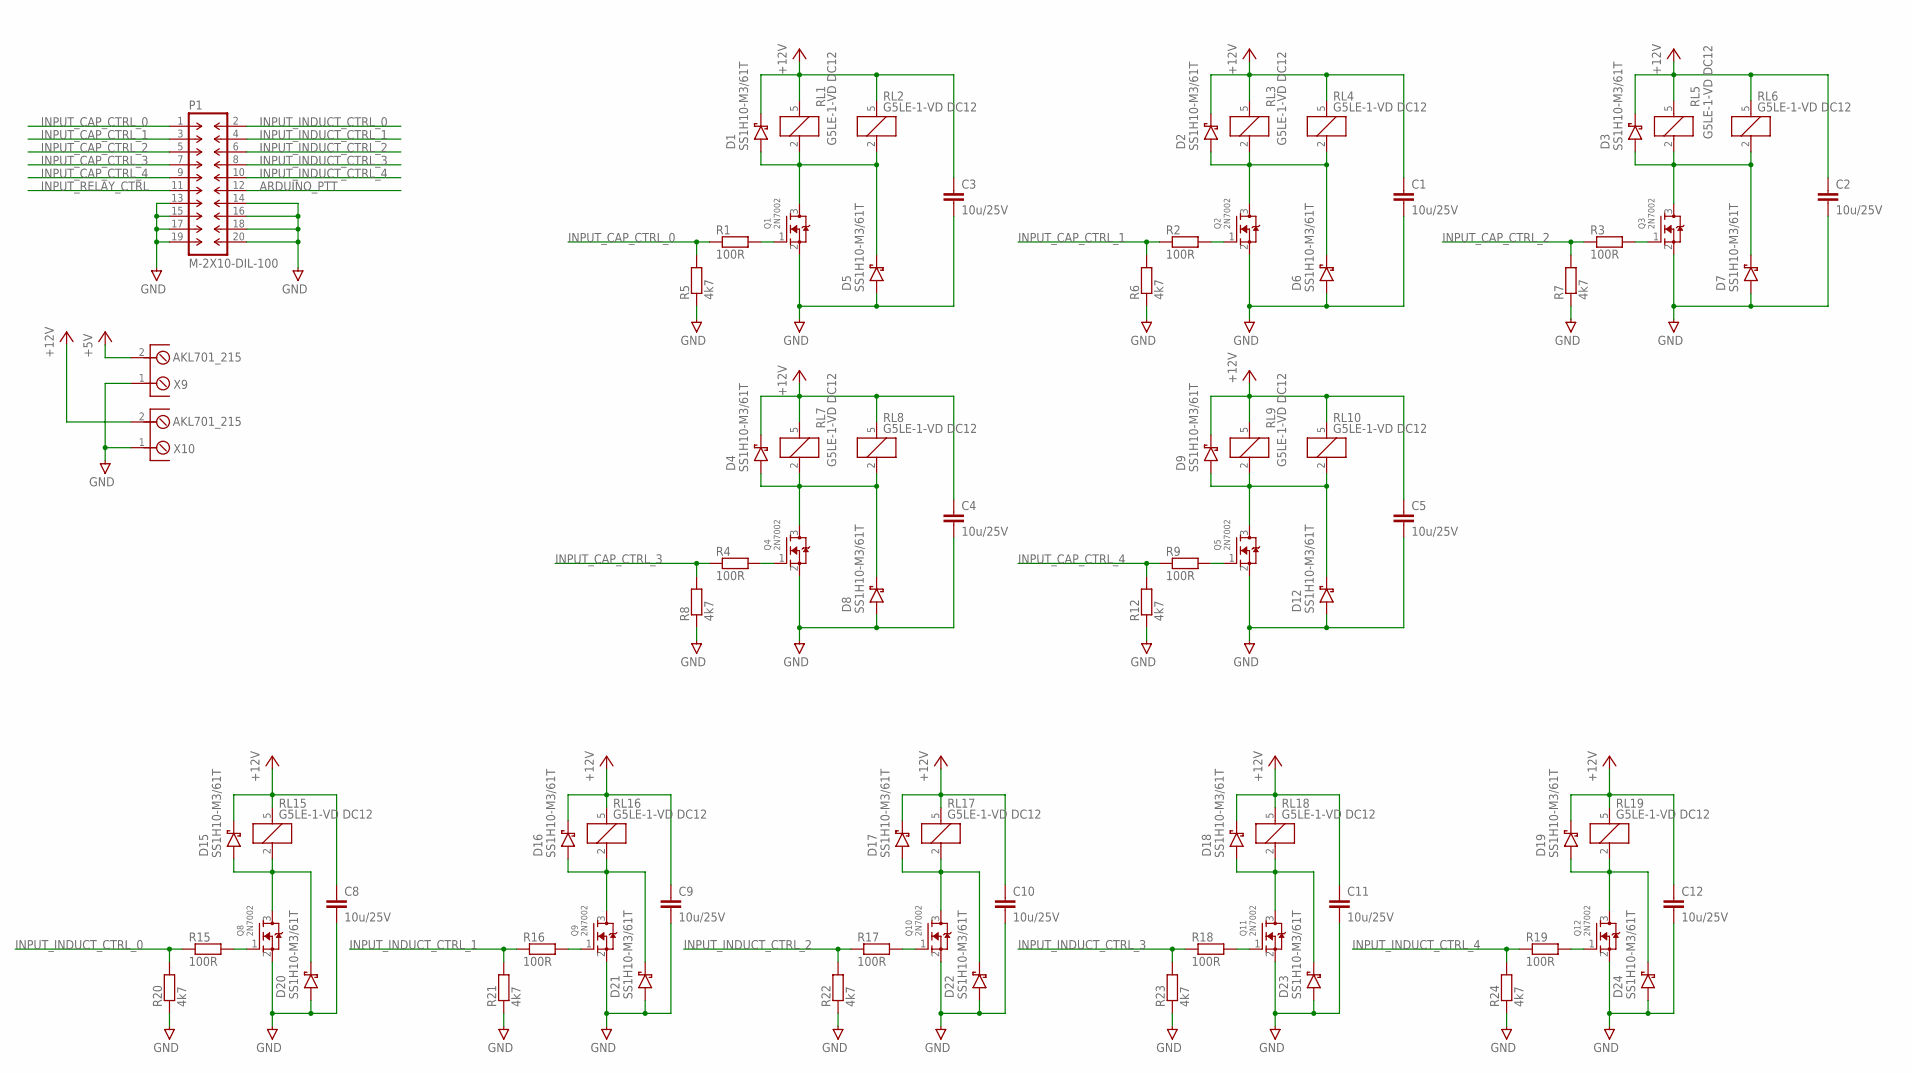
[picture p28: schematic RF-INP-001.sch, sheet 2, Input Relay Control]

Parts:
C1, C2, C3, C4, C5, C8, C9, C10, C11, C12: 10u/25V; C0805
D1, D2, D3, D4, D5, D6, D7, D8, D9, D12, D15, D16, D17, D18, D19, D20, D21, D22, D23, D24: SS1H10-M3/61T; SMA/DO-214AC
P1: M-2X10-DIL-100; DIL-100-2X10
Q1, Q2, Q3, Q4, Q5, Q8, Q9, Q10, Q11, Q12: 2N7002; SOT23
R1, R2, R3, R4, R9, R15, R16, R17, R18, R19: 100R; R0603
R5, R6, R7, R8, R12, R20, R21, R22, R23, R24: 4k7; R0603
RL1, RL2, RL3, RL4, RL5, RL6, RL7, RL8, RL9, RL10, RL15, RL16, RL17, RL18, RL19: G5LE-1-VD DC12; SPDT
X9, X10: AKL701_215; AKL701_2_15

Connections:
+5V: X9.2; also elsewhere on the board
+12V: C1.1, C2.1, C3.1, C4.1, C5.1, C8.1, C9.1, C10.1, C11.1, C12.1, D1.C (CATHODE), D2.C (CATHODE), D3.C (CATHODE), D4.C (CATHODE), D9.C (CATHODE), D15.C (CATHODE), D16.C (CATHODE), D17.C (CATHODE), D18.C (CATHODE), D19.C (CATHODE), RL1.5, RL2.5, RL3.5, RL4.5, RL5.5, RL6.5, RL7.5, RL8.5, RL9.5, RL10.5, RL15.5, RL16.5, RL17.5, RL18.5, RL19.5, X10.2; also elsewhere on the board
ARDUINO_PTT: P1.12; also elsewhere on the board
GND: C1.2, C2.2, C3.2, C4.2, C5.2, C8.2, C9.2, C10.2, C11.2, C12.2, D5.A (ANODE), D6.A (ANODE), D7.A (ANODE), D8.A (ANODE), D12.A (ANODE), D20.A (ANODE), D21.A (ANODE), D22.A (ANODE), D23.A (ANODE), D24.A (ANODE), P1.13, P1.14, P1.15, P1.16, P1.17, P1.18, P1.19, P1.20, Q1.2 (S), Q2.2 (S), Q3.2 (S), Q4.2 (S), Q5.2 (S), Q8.2 (S), Q9.2 (S), Q10.2 (S), Q11.2 (S), Q12.2 (S), R5.1, R6.1, R7.1, R8.1, R12.1, R20.1, R21.1, R22.1, R23.1, R24.1, X9.1, X10.1; also elsewhere on the board
INPUT_CAP_CTRL_0: P1.1, R1.1, R5.2
INPUT_CAP_CTRL_1: P1.3, R2.1, R6.2
INPUT_CAP_CTRL_2: P1.5, R3.1, R7.2
INPUT_CAP_CTRL_3: P1.7, R4.1, R8.2
INPUT_CAP_CTRL_4: P1.9, R9.1, R12.2
INPUT_INDUCT_CTRL_0: P1.2, R15.1, R20.2
INPUT_INDUCT_CTRL_1: P1.4, R16.1, R21.2
INPUT_INDUCT_CTRL_2: P1.6, R17.1, R22.2
INPUT_INDUCT_CTRL_3: P1.8, R18.1, R23.2
INPUT_INDUCT_CTRL_4: P1.10, R19.1, R24.2
INPUT_RELAY_CTRL: P1.11; also elsewhere on the board
unnamed: D16.A (ANODE), D21.C (CATHODE), Q9.3 (D), RL16.2
unnamed: Q9.1 (G), R16.2
unnamed: D17.A (ANODE), D22.C (CATHODE), Q10.3 (D), RL17.2
unnamed: Q10.1 (G), R17.2
unnamed: D18.A (ANODE), D23.C (CATHODE), Q11.3 (D), RL18.2
unnamed: Q11.1 (G), R18.2
unnamed: D19.A (ANODE), D24.C (CATHODE), Q12.3 (D), RL19.2
unnamed: Q12.1 (G), R19.2
unnamed: D1.A (ANODE), D5.C (CATHODE), Q1.3 (D), RL1.2, RL2.2
unnamed: Q1.1 (G), R1.2
unnamed: D2.A (ANODE), D6.C (CATHODE), Q2.3 (D), RL3.2, RL4.2
unnamed: Q2.1 (G), R2.2
unnamed: D4.A (ANODE), D8.C (CATHODE), Q4.3 (D), RL7.2, RL8.2
unnamed: Q4.1 (G), R4.2
unnamed: D9.A (ANODE), D12.C (CATHODE), Q5.3 (D), RL9.2, RL10.2
unnamed: Q5.1 (G), R9.2
unnamed: D3.A (ANODE), D7.C (CATHODE), Q3.3 (D), RL5.2, RL6.2
unnamed: Q3.1 (G), R3.2
unnamed: D15.A (ANODE), D20.C (CATHODE), Q8.3 (D), RL15.2
unnamed: Q8.1 (G), R15.2

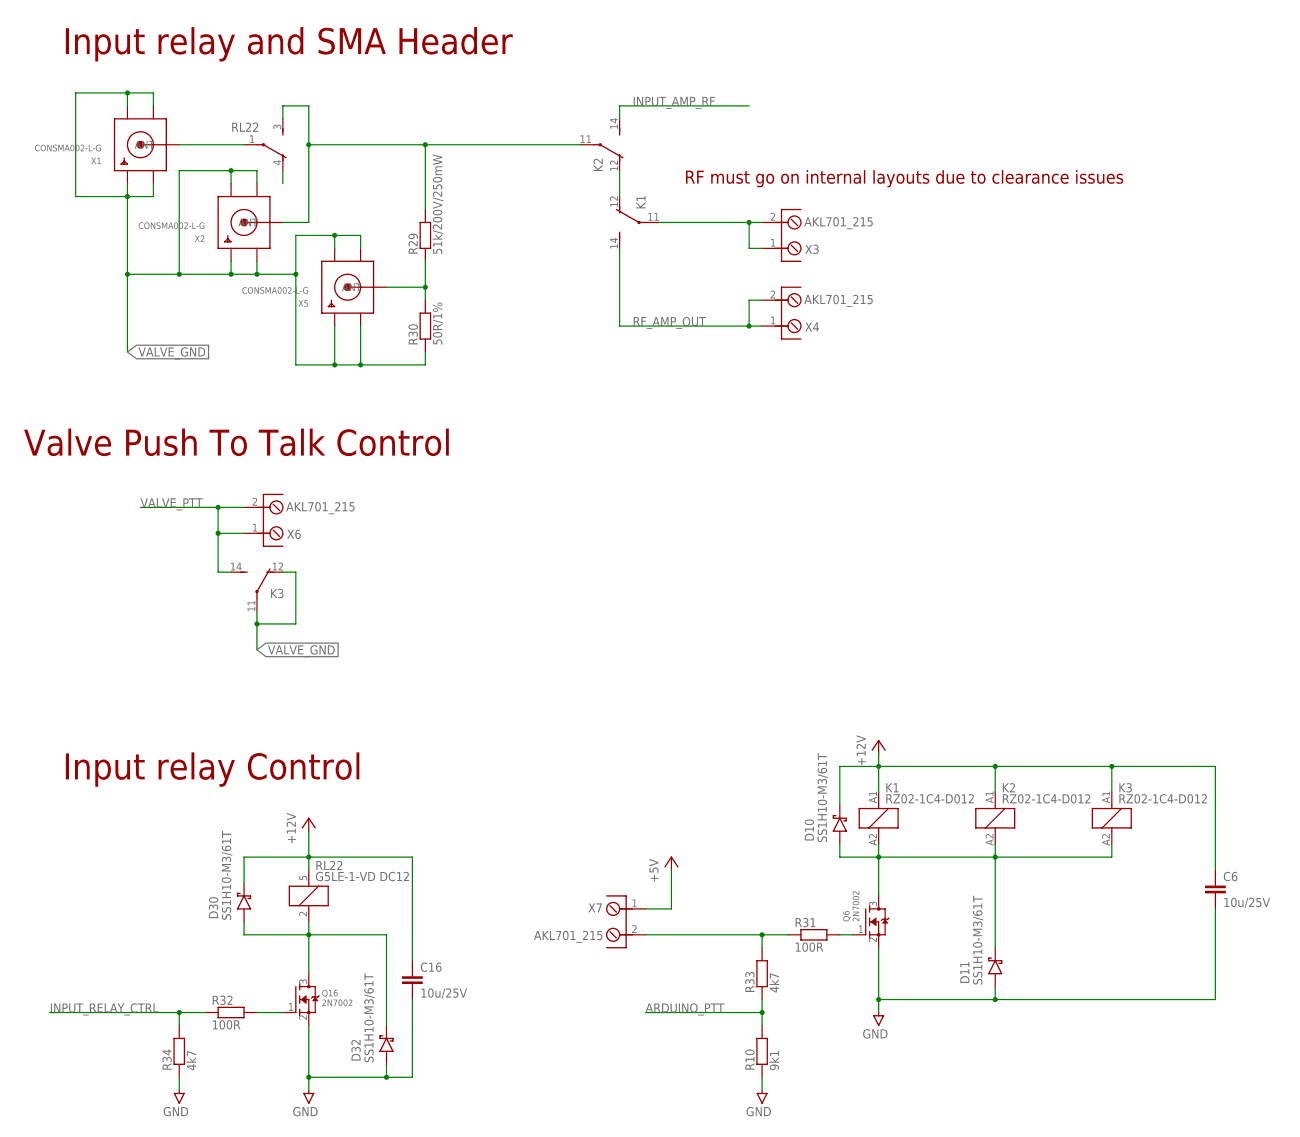
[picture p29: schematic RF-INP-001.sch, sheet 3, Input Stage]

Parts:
C6, C16: 10u/25V; C0805
D10, D11, D30, D32: SS1H10-M3/61T; SMA/DO-214AC
K1, K2, K3: RZ02-1C4-D012; 12A-5MM
Q6, Q16: 2N7002; SOT23
R10: 9k1; R0603
R29: 51k/200V/250mW; R2512
R30: 50R/1%; R0603
R31, R32: 100R; R0603
R33, R34: 4k7; R0603
RL22: G5LE-1-VD DC12; SPDT
X1, X2, X5: CONSMA002-L-G; SMA90_DIP
X3, X4, X6, X7: AKL701_215; AKL701_2_15

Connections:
+5V: X7.1; also elsewhere on the board
+12V: C6.1, C16.1, D10.C (CATHODE), D30.C (CATHODE), K1.A1 (1), K2.A1 (1), K3.A1 (1), RL22.5; also elsewhere on the board
ARDUINO_PTT: R10.2, R33.1; also elsewhere on the board
GND: C6.2, C16.2, D11.A (ANODE), D32.A (ANODE), Q6.2 (S), Q16.2 (S), R10.1, R34.1; also elsewhere on the board
INPUT_AMP_RF: K2.14 (NO); also elsewhere on the board
INPUT_RELAY_CTRL: R32.1, R34.2; also elsewhere on the board
unnamed: D10.A (ANODE), D11.C (CATHODE), K1.A2 (2), K2.A2 (2), K3.A2 (2), Q6.3 (D)
unnamed: K1.12 (NC), K2.12 (NC)
unnamed: K1.11 (COM), X3.1, X3.2
unnamed: Q6.1 (G), R31.2
unnamed: D30.A (ANODE), D32.C (CATHODE), Q16.3 (D), RL22.2
unnamed: Q16.1 (G), R32.2
unnamed: R29.1, R30.2, X5.ANTENNA (ANT)
unnamed: RL22.1, X1.ANTENNA (ANT)
unnamed: R31.1, R33.2, X7.2
unnamed: K2.11 (COM), R29.2, RL22.3, X2.ANTENNA (ANT)
RF_AMP_OUT: K1.14 (NO), X4.1, X4.2
VALVE_GND: K3.11 (COM), K3.12 (NC), R30.1, X1.GND1, X1.GND2, X1.GND3, X1.GND4, X2.GND1, X2.GND2, X2.GND3, X2.GND4, X5.GND1, X5.GND2, X5.GND3, X5.GND4; also elsewhere on the board
VALVE_PTT: K3.14 (NO), X6.1, X6.2

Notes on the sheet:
Input relay and SMA Header
Input relay Control
Valve Push To Talk Control
RF must go on internal layouts due to clearance issues

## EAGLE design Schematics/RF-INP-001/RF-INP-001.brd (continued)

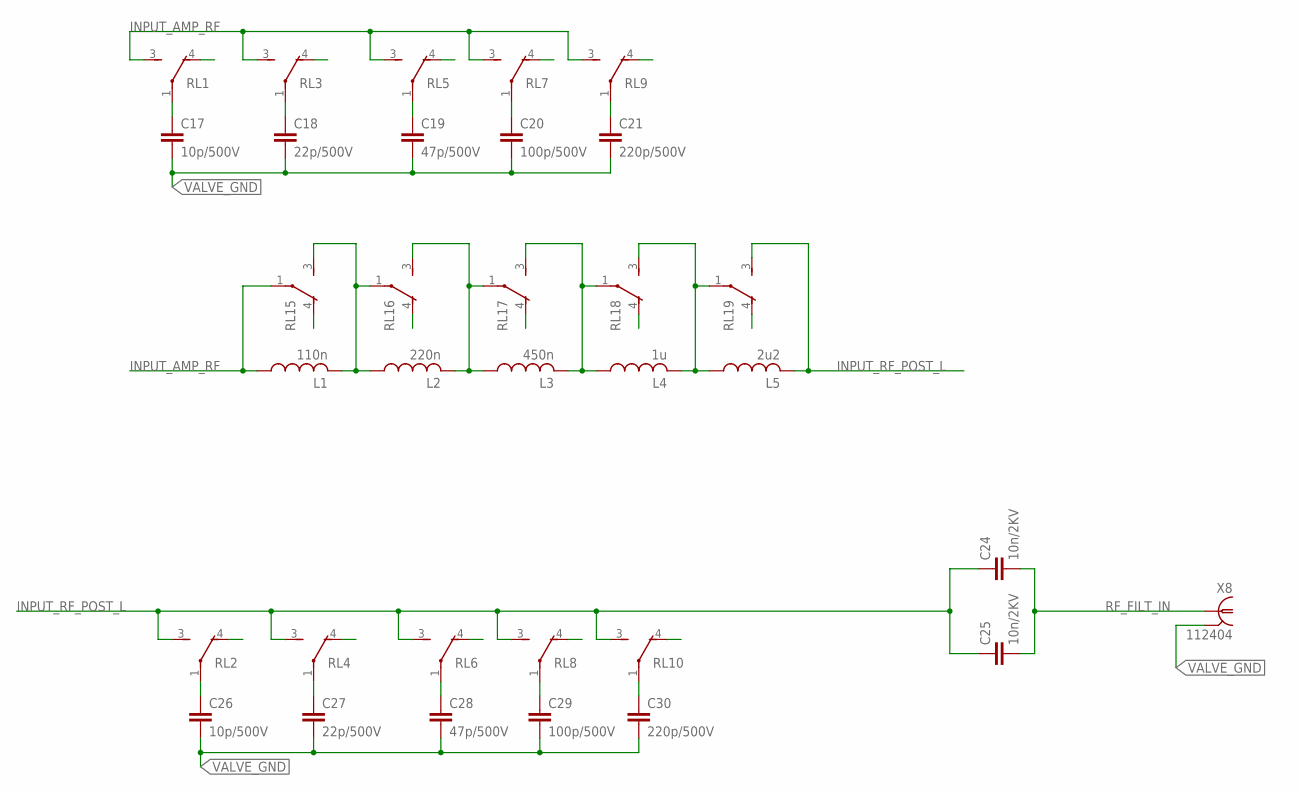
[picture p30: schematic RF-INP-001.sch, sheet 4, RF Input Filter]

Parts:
C17, C26: 10p/500V; C1812
C18, C27: 22p/500V; C1812
C19, C28: 47p/500V; C1812
C20, C29: 100p/500V; C1812
C21, C30: 220p/500V; C1812
C24, C25: 10n/2KV; C1812
L1: 110n; T80-6
L2: 220n; T80-6
L3: 450n; T80-6
L4: 1u; T80-6
L5: 2u2; T80-6
RL1, RL2, RL3, RL4, RL5, RL6, RL7, RL8, RL9, RL10, RL15, RL16, RL17, RL18, RL19: G5LE-1-VD DC12; SPDT
X8: 112404

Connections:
INPUT_AMP_RF: L1.1, RL1.3, RL3.3, RL5.3, RL7.3, RL9.3, RL15.1; also elsewhere on the board
INPUT_RF_POST_L: C24.1, C25.1, L5.2, RL2.3, RL4.3, RL6.3, RL8.3, RL10.3, RL19.3
unnamed: C17.1, RL1.1
unnamed: C26.1, RL2.1
unnamed: C27.1, RL4.1
unnamed: C28.1, RL6.1
unnamed: C29.1, RL8.1
unnamed: C30.1, RL10.1
unnamed: C18.1, RL3.1
unnamed: C19.1, RL5.1
unnamed: C21.1, RL9.1
unnamed: C20.1, RL7.1
unnamed: L4.2, L5.1, RL18.3, RL19.1
unnamed: L3.2, L4.1, RL17.3, RL18.1
unnamed: L2.2, L3.1, RL16.3, RL17.1
unnamed: L1.2, L2.1, RL15.3, RL16.1
RF_FILT_IN: C24.2, C25.2, X8.1
VALVE_GND: C17.2, C18.2, C19.2, C20.2, C21.2, C26.2, C27.2, C28.2, C29.2, C30.2, X8.2, X8.3 (2), X8.4 (2), X8.5 (2); also elsewhere on the board

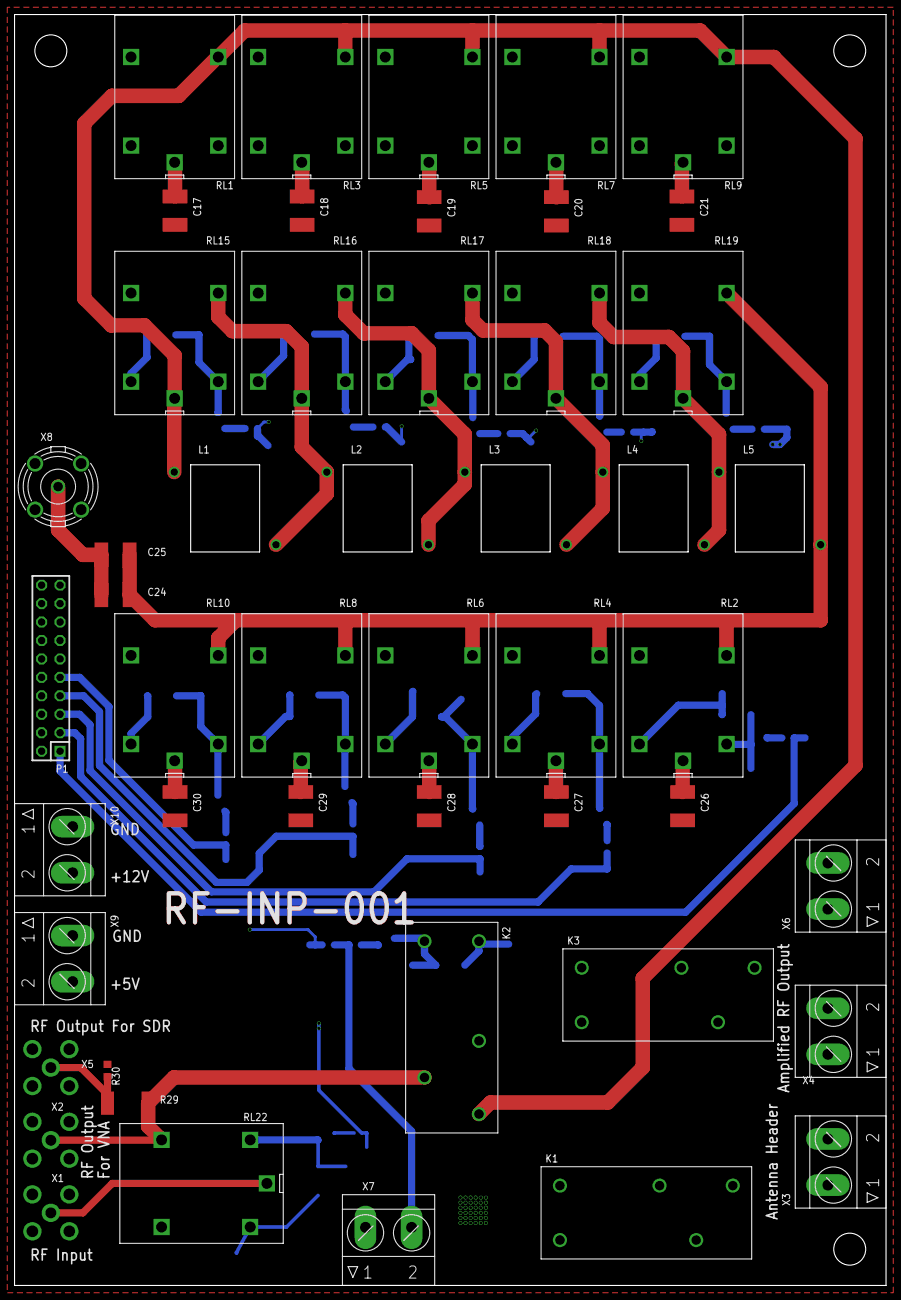
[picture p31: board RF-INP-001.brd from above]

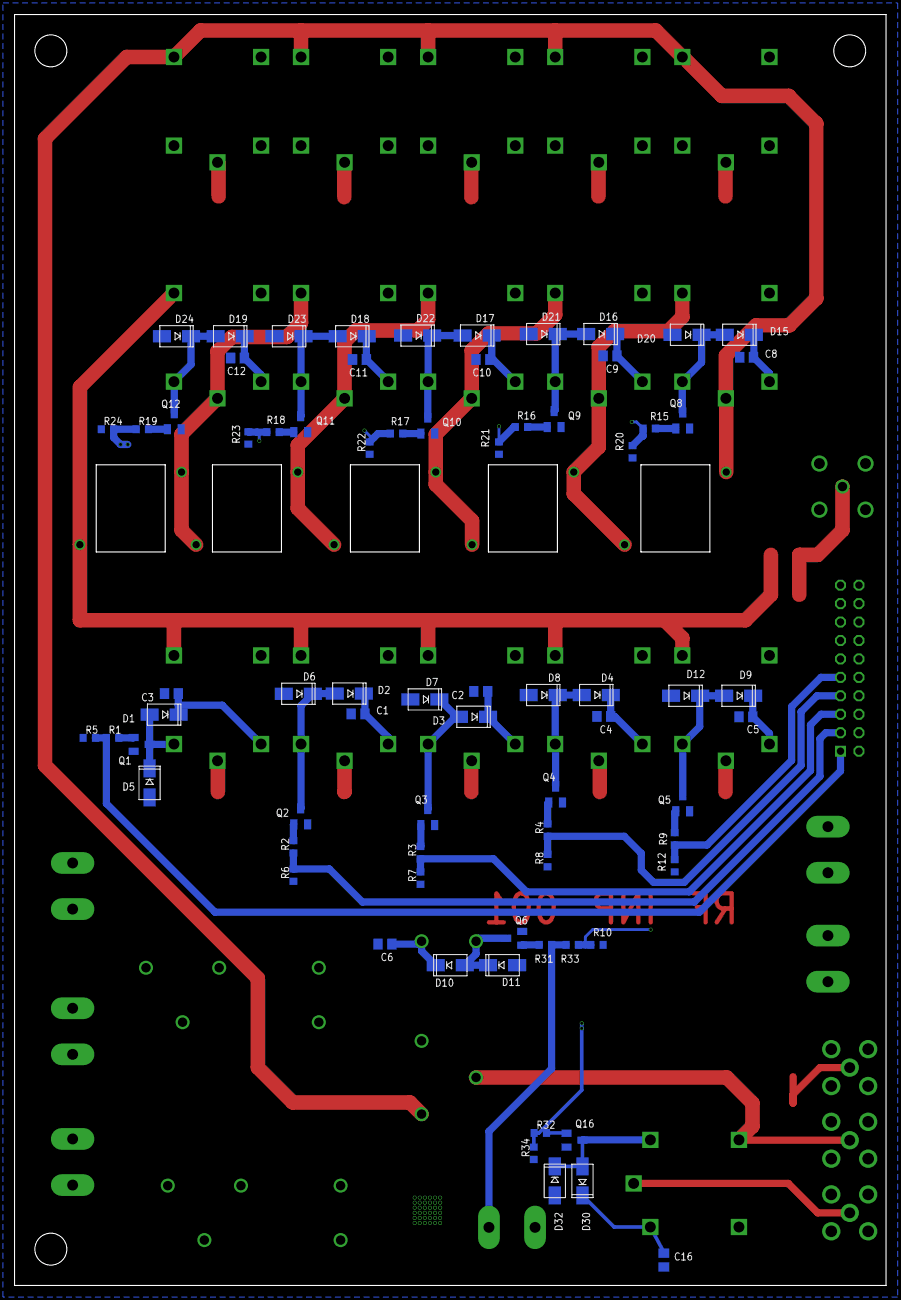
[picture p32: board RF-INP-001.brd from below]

Board: 4 copper layers, 120.0 x 175.0 mm, 122 parts (73 on the bottom side), 65 nets.

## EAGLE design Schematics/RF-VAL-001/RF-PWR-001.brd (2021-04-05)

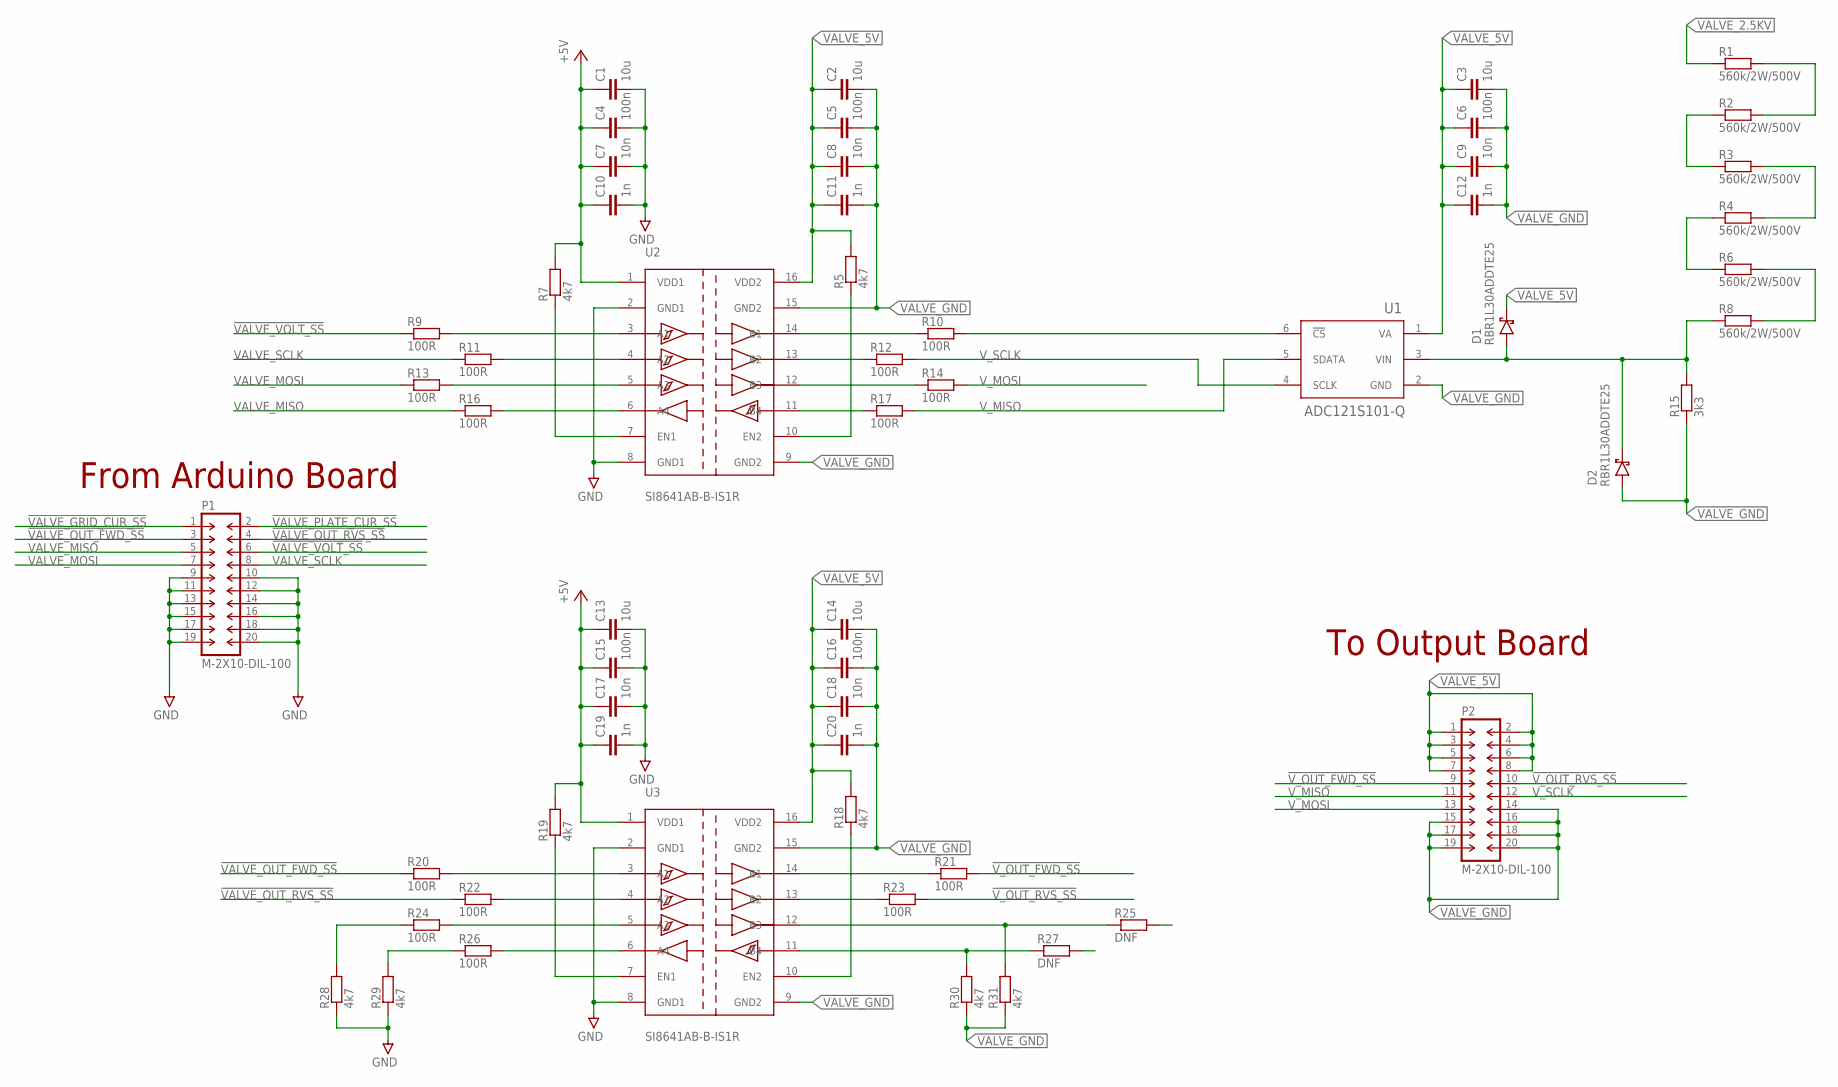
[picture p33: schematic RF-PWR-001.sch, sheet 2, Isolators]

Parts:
C1, C2, C3, C13, C14: 10u; C0805
C4, C5, C6, C15, C16: 100n; C0603
C7, C8, C9, C17, C18: 10n; C0603
C10, C11, C12, C19, C20: 1n; C0603
D1, D2: RBR1L30ADDTE25; SMA/DO-214AC
P1, P2: M-2X10-DIL-100; DIL-100-2X10
R1, R2, R3, R4, R6, R8: 560k/2W/500V; SMV1/SMF2
R5, R7, R18, R19, R28, R29, R30, R31: 4k7; R0603
R9, R10, R11, R12, R13, R14, R16, R17, R20, R21, R22, R23, R24, R26: 100R; R0603
R15: 3k3; R0603
R25, R27: DNF; R0603
U1: ADC121S101-Q; SOT23-6
U2, U3: SI8641AB-B-IS1R; SO16

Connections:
!VALVE_GRID_CUR_SS: P1.1; also elsewhere on the board
!VALVE_OUT_FWD_SS: P1.3, R20.1
!VALVE_OUT_RVS_SS: P1.4, R22.1
!VALVE_PLATE_CUR_SS: P1.2; also elsewhere on the board
!VALVE_VOLT_SS: P1.6, R9.1
!V_OUT_FWD_SS: P2.9, R21.2
!V_OUT_RVS_SS: P2.10, R23.2
+5V: C1.1, C4.1, C7.1, C10.1, C13.1, C15.1, C17.1, C19.1, R7.2, R19.2, U2.1 (VDD1), U3.1 (VDD1); also elsewhere on the board
GND: C1.2, C4.2, C7.2, C10.2, C13.2, C15.2, C17.2, C19.2, P1.9, P1.10, P1.11, P1.12, P1.13, P1.14, P1.15, P1.16, P1.17, P1.18, P1.19, P1.20, R28.1, R29.1, U2.2 (GND1), U2.8 (GND1), U3.2 (GND1), U3.8 (GND1); also elsewhere on the board
unnamed: R24.1, R28.2
unnamed: R13.2, U2.5 (A3)
unnamed: R16.2, U2.6 (A4)
unnamed: R11.2, U2.4 (A2)
unnamed: R9.2, U2.3 (A1)
unnamed: R7.1, U2.7 (EN1)
unnamed: R5.1, U2.10 (EN2)
unnamed: R14.1, U2.12 (B3)
unnamed: R17.1, U2.11 (B4)
unnamed: R27.1, R30.2, U3.11 (B4)
unnamed: R12.1, U2.13 (B2)
unnamed: R10.1, U2.14 (B1)
unnamed: R10.2, U1.6 (!CS)
unnamed: R23.1, U3.13 (B2)
unnamed: R21.1, U3.14 (B1)
unnamed: D1.A (ANODE), D2.C (CATHODE), R8.1, R15.2, U1.3 (VIN)
unnamed: R4.1, R6.1
unnamed: R6.2, R8.2
unnamed: R3.2, R4.2
unnamed: R1.2, R2.2
unnamed: R2.1, R3.1
unnamed: R24.2, U3.5 (A3)
unnamed: R26.2, U3.6 (A4)
unnamed: R22.2, U3.4 (A2)
unnamed: R20.2, U3.3 (A1)
unnamed: R19.1, U3.7 (EN1)
unnamed: R18.1, U3.10 (EN2)
unnamed: R25.1, R31.2, U3.12 (B3)
unnamed: R26.1, R29.2
VALVE_2.5KV: R1.1; also elsewhere on the board
VALVE_5V: C2.1, C3.1, C5.1, C6.1, C8.1, C9.1, C11.1, C12.1, C14.1, C16.1, C18.1, C20.1, D1.C (CATHODE), P2.1, P2.2, P2.3, P2.4, P2.5, P2.6, P2.7, P2.8, R5.2, R18.2, U1.1 (VA), U2.16 (VDD2), U3.16 (VDD2); also elsewhere on the board
VALVE_GND: C2.2, C3.2, C5.2, C6.2, C8.2, C9.2, C11.2, C12.2, C14.2, C16.2, C18.2, C20.2, D2.A (ANODE), P2.14, P2.15, P2.16, P2.17, P2.18, P2.19, P2.20, R15.1, R30.1, R31.1, U1.2 (GND), U2.9 (GND2), U2.15 (GND2), U3.9 (GND2), U3.15 (GND2); also elsewhere on the board
VALVE_MISO: P1.5, R16.1; also elsewhere on the board
VALVE_MOSI: P1.7, R13.1
VALVE_SCLK: P1.8, R11.1; also elsewhere on the board
V_MISO: P2.11, R17.2, U1.5 (SDATA)
V_MOSI: P2.13, R14.2
V_SCLK: P2.12, R12.2, U1.4 (SCLK)

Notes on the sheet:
To Output Board
From Arduino Board


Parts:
C21, C22, C23, C24, C25, C26: 220n/450V; C1210
C27, C31, C49, C53: 10u/25V; C0805
C28, C32, C50, C54: 100n/25V; C0603
C29, C33, C51, C55: 10n/25V; C0603
C30, C34, C52, C56: 1n/25V; C0603
C35: 10u; C0805
C36: 100n; C0603
C37: 10n; C0603
C38: 1n; C0603
C39: DNF-100n; C0603
C40, C45: DNF; C0805
C41, C42, C43, C46, C47, C48: DNF; C0603
C44: DNF; C1206
D3, D4, D5, D6, D7, D8, D9, D10: MBR10100-M3/4W; TO220ACS
L1: 3.9mH; WE-FCL_ET35
L2: DNF-47uH; WE-HCF_2920_ROUND
P3: M-2X10-DIL-100; DIL-100-2X10
R32: DNF-30R; R0603
R33: DNF-174k; R0603
R34: DNF-40k2/0.1%; R0603
R35: DNF-36.5k; R0603
R36: DNF-10k/0.1%; R0603
VR1: IRM-02-5; IRM_1-2_TH
VR2: DNF-TPS56339DDCR; SOT23-6
VR3: IRM-05-5; IRM_5-10_TH
VR4: IRM-20-12; IRM_15-20_TH
X1, X3, X5, X6: AKL701_3_15
X2, X4, X7, X8, X9, X10, X11, X12, X13: AKL701_215; AKL701_2_15

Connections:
+4V: C44.1, C45.1, C46.1, C47.1, C48.1, L2.2, X10.2
+5V: C49.1, C50.1, C51.1, C52.1, P3.2, P3.4, P3.6, P3.8, P3.10, VR3.+V (V+), X11.2; also elsewhere on the board
+12V: C40.1, C41.1, C42.1, C43.1, C53.1, C54.1, C55.1, C56.1, P3.1, P3.3, P3.5, P3.7, P3.9, R33.2, VR2.3 (VIN), VR4.+V (V+), X12.2, X13.2
AC/L: C22.1, C24.1, L1.3 (2), VR1.AC/L, VR3.AC/L, VR4.AC/L, X3.3, X5.3, X6.3
AC/N: C24.2, C26.2, L1.2 (3), VR1.AC/N, VR3.AC/N, VR4.AC/N, X3.1, X5.1, X6.1
EARTH: C21.2, C22.2, C25.1, C26.1, X1.2, X3.2, X5.2, X6.2
GND: C40.2, C41.2, C42.2, C43.2, C44.2, C45.2, C46.2, C47.2, C48.2, C49.2, C50.2, C51.2, C52.2, C53.2, C54.2, C55.2, C56.2, P3.11, P3.12, P3.13, P3.14, P3.15, P3.16, P3.17, P3.18, P3.19, P3.20, R35.1, R36.1, VR2.1 (GND), VR3.-V (V-), VR4.-V (V-), X10.1, X11.1, X12.1, X13.1; also elsewhere on the board
unnamed: D3.A, D5.C, X4.2
unnamed: D4.A, D6.C, X4.1
unnamed: R33.1, R35.2, VR2.5 (EN)
unnamed: D7.A, D9.C, X8.2
unnamed: D8.A, D10.C, X8.1
unnamed: C21.1, C23.1, L1.4 (1), X1.1
unnamed: C23.2, C25.2, L1.1 (4), X1.3
unnamed: C39.1, R32.2
unnamed: C39.2, L2.1, R34.2, VR2.2 (SW)
unnamed: R34.1, R36.2, VR2.4 (FB)
unnamed: R32.1, VR2.6 (BOOT)
VALVE_5V: C35.1, C36.1, C37.1, C38.1, VR1.+V (V+), X9.2; also elsewhere on the board
VALVE_6V3: C27.1, C28.1, C29.1, C30.1, D3.C, D4.C, X2.2
VALVE_-30V: X7.1; also elsewhere on the board
VALVE_-30V_GEN: C31.2, C32.2, C33.2, C34.2, D9.A, D10.A; also elsewhere on the board
VALVE_GND: C27.2, C28.2, C29.2, C30.2, C31.1, C32.1, C33.1, C34.1, C35.2, C36.2, C37.2, C38.2, D5.A, D6.A, D7.C, D8.C, VR1.-V (V-), X2.1, X7.2, X9.1; also elsewhere on the board

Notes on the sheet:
Pi and Rasp Power


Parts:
C57, C58, C59, C61, C62, C63, C87: 18n/2kV; C050-075X075
C60, C64, C66, C74, C79, C81, C82: 470uF/450V; STYLE_D(35MM)
C65, C83: DNF; C0805
C67, C68, C85, C86: 10u; C0805
C69, C72, C76, C84, C88, C91: DNF; C0603
C70, C71, C89, C90: 100n; C0603
C73, C75, C80, C92, C93, C96: 10n; C0603
C77, C78, C94, C95: 1n; C0603
D11, D12, D13, D14, D15, D16, D17, D18: C5D05170H; TO-247-2
IC1, IC2: LMV321M5X/NOPB; SOT23-5
R37, R39: 10M/1W/1kV; R2512
R38, R40, R41, R42, R45, R49, R50: 100k/500V/1W; R2512
R43, R46, R48, R51, R52, R54, R55, R57: DNF; R0603
R44, R53: 0R; R0603
R47, R56: 4k7; R0603
TP1, TP2: TPTP16R; TP16R
U4, U6: ADC121S101-Q; SOT23-6
U5, U7: MCA1101-5-5; SOIC_16
X14, X15, X16, X17: AKL701_215; AKL701_2_15

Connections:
!VALVE_GRID_CUR_SS: U4.6 (!CS); also elsewhere on the board
!VALVE_PLATE_CUR_SS: U6.6 (!CS); also elsewhere on the board
+5V: C65.1, C67.1, C68.1, C69.1, C70.1, C71.1, C72.1, C73.1, C75.1, C76.1, C77.1, C78.1, C83.1, C84.1, C85.1, C86.1, C88.1, C89.1, C90.1, C91.1, C92.1, C93.1, C94.1, C95.1, IC1.5 (V+), IC2.5 (V+), R43.2, R52.2, U4.1 (VA), U5.10 (VCC), U6.1 (VA), U7.10 (VCC); also elsewhere on the board
GND: C65.2, C67.2, C68.2, C69.2, C70.2, C71.2, C72.2, C73.2, C75.2, C76.2, C77.2, C78.2, C80.2, C83.2, C84.2, C85.2, C86.2, C88.2, C89.2, C90.2, C91.2, C92.2, C93.2, C94.2, C95.2, C96.2, IC1.2 (V-), IC2.2 (V-), R47.1, R48.1, R55.1, R56.1, U4.2 (GND), U5.11 (GND), U5.14 (GND), U5.15 (GND), U6.2 (GND), U7.11 (GND), U7.14 (GND), U7.15 (GND); also elsewhere on the board
GRID_CURR_AMP: R44.1, R57.1, U4.3 (VIN)
GRID_CURR_FAULT: TP2.TP, U5.9 (!FAULTB)
GRID_CURR_OUT: IC1.1 (+IN), R44.2, U5.12 (VOUT)
unnamed: IC1.4 (OUT), R46.1, R57.2
unnamed: IC2.4 (OUT), R51.2, R54.1
unnamed: C81.-VE (-), C82.+VE (+), R49.1, R50.2
unnamed: D11.3 (ANODE), D13.1 (CATHODE)
unnamed: D15.3 (ANODE), D17.1 (CATHODE)
unnamed: D12.3 (ANODE), D14.1 (CATHODE)
unnamed: D16.3 (ANODE), D18.1 (CATHODE)
unnamed: C79.-VE (-), C81.+VE (+), R45.1, R49.2
unnamed: C66.-VE (-), C74.+VE (+), R41.1, R42.2
unnamed: C64.-VE (-), C66.+VE (+), R40.1, R41.2
unnamed: C60.-VE (-), C64.+VE (+), R38.1, R40.2
unnamed: C74.-VE (-), C79.+VE (+), R42.1, R45.2
unnamed: R52.1, R56.2, U7.16 (VOC)
unnamed: C96.1, U7.13 (VREF)
unnamed: C57.2, C58.2, C59.2, C61.1, C62.1, C63.1, R37.1, R39.2
unnamed: R43.1, R47.2, U5.16 (VOC)
unnamed: IC2.3 (-IN), R54.2, R55.2
unnamed: C80.1, U5.13 (VREF)
unnamed: IC1.3 (-IN), R46.2, R48.2
PLATE_CURR_AMP: R51.1, R53.1, U6.3 (VIN)
PLATE_CURR_FAULT: TP1.TP, U7.9 (!FAULTB)
PLATE_CURR_OUT: IC2.1 (+IN), R53.2, U7.12 (VOUT)
VALVE_2.5KV: C57.1, C58.1, C59.1, C60.+VE (+), D11.1 (CATHODE), D12.1 (CATHODE), R37.2, R38.2, X14.1, X14.2; also elsewhere on the board
VALVE_-30V: U5.5 (IP-), U5.6 (IP-), U5.7 (IP-), U5.8 (IP-); also elsewhere on the board
VALVE_-30V_GEN: U5.1 (IP+), U5.2 (IP+), U5.3 (IP+), U5.4 (IP+); also elsewhere on the board
VALVE_GND: C87.2, U7.5 (IP-), U7.6 (IP-), U7.7 (IP-), U7.8 (IP-), X17.1, X17.2; also elsewhere on the board
VALVE_LOW: C61.2, C62.2, C63.2, C82.-VE (-), C87.1, D17.3 (ANODE), D18.3 (ANODE), R39.1, R50.1, U7.1 (IP+), U7.2 (IP+), U7.3 (IP+), U7.4 (IP+)
VALVE_MISO: U4.5 (SDATA), U6.5 (SDATA); also elsewhere on the board
VALVE_PWR_+VE: D13.3 (ANODE), D15.1 (CATHODE), X15.1, X15.2
VALVE_PWR_-VE: D14.3 (ANODE), D16.1 (CATHODE), X16.1, X16.2
VALVE_SCLK: U4.4 (SCLK), U6.4 (SCLK); also elsewhere on the board



Board: 2 copper layers, 200.0 x 200.0 mm, 208 parts (23 on the bottom side), 94 nets.

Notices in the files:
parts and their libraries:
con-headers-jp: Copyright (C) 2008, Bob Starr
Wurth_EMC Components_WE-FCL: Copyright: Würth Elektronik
